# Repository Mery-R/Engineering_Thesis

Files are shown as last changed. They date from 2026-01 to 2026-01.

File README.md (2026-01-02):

# Engineering Thesis - GPS & CAN Data Collection System

## Project Overview

This is an ESP32-based data acquisition system designed for an engineering thesis. The system collects telemetry data from multiple sources including GPS (NMEA), Temperature (DS18B20), and CAN bus (via TWAI). Data is transmitted to the ThingsBoard IoT platform via MQTT over Wi-Fi and simultaneously logged to an SD card for offline retrieval.

 The system is designed with a coordinator-driven architecture using FreeRTOS to ensure synchronized data snapshots.

## System Architecture

### Main Components

1.  **main.ino**: Entry point handling FreeRTOS task creation, hardware setup, and the central Coordinator logic.
2.  **GpsModule**: Wrapper for `TinyGPSPlus`, handles UART communication with the GPS receiver.
3.  **CanModule**: Manages the ESP32 Two-Wire Automotive Interface (TWAI) to read speed data from the vehicle's CAN bus.
4.  **SdModule**: Manages logging data to SD card in JSON Lines format (`.jsonl`), including an "offline pending" queue for later transmission.
5.  **ThingsBoardClient**: Handles MQTT connection, telemetry data upload, and attribute synchronization (e.g., changing sampling intervals remotely).
6.  **TimeManager**: Maintains high-precision system time, synchronized via GPS PPS (Pulse Per Second) or optional NTP/WiFi fallback.
7.  **WebServerModule**: Provides a local web interface for system status/map visualization (runs on port 80).
8.  **WiFiManager**: Handles Wi-Fi connection logic, manages a list of known networks (SSID/Password), and handles automatic reconnection.
9.  **SensorData**: Header-only helper defining the core global data structure (`struct SensorData`) and bitwise error codes [ec] used for data exchange between tasks.

### FreeRTOS Tasks & Logic

 The system uses a **Coordinator-driven** architecture. A central task triggers sensors, waits for their data, creates a synchronized snapshot, and dispatches it for storage/upload.

1.  **CoordinatorTask** (Priority 2)
    *   Wakes up every `Delay_MAIN` (default 15s).
    *   Triggers measurement tasks (`TaskGPS`, `TaskTemp`, `TaskCAN`) via task notifications.
    *   Waits for an Event Group signal indicating all enabled sensors have finished (or timed out).
    *   Collects a snapshot of all sensor data + timestamp + RSSI.
    *   Pushes the snapshot to a Ring Buffer (Queue).
    *   Notifies `TaskDataSync` to process the new data.

2.  **TaskGPS** (Priority 1)
    *   Waits for trigger.
    *   Wakes GPS module and processes NMEA stream for up to 5 seconds to get a fresh fix.
    *   Updates global state with Lat, Lon, Alt, Speed.

3.  **TaskTemp** (Priority 1)
    *   Waits for trigger.
    *   Requests conversion on DS18B20 (approx 750ms delay).
    *   Updates global state with Temperature.

4.  **TaskCAN** (Priority 2)
    *   Continuously monitors CAN bus but updates the global snapshot timestamp/value when triggered by Coordinator or when fresh data arrives.

5.  **TaskDataSync** (Priority 1)
    *   Handles both ThingsBoard (MQTT) upload and SD Card logging.
    *   **Online**: Sends data from Ring Buffer to ThingsBoard.
    *   **Offline**: Saves data to a "Pending" file on SD card.
    *   **Recovery**: When connection is restored, reads from "Pending" file and uploads to ThingsBoard.
    *   **Archiving**: Always saves every record to `archive_timestamp.jsonl` on SD card.

6.  **TaskWiFi** (Priority 1)
    *   Monitors connection status and manages reconnection logic.

7.  **TaskSleep** (Priority 5)
    *   Handles the Wake/Sleep button.
    *   On press: debounces, waits for release, flushes all buffers to SD/MQTT, and initiates Deep Sleep.

### Data Flow

```mermaid
graph TD;
    Coord[Coordinator Task] -->|Trigger| GPS[TaskGPS];
    Coord -->|Trigger| Temp[TaskTemp];
    Coord -->|Trigger| CAN[TaskCAN];
    
    GPS -->|Signal Ready| EventGrp[Event Group];
    Temp -->|Signal Ready| EventGrp;
    CAN -->|Signal Ready| EventGrp;
    
    EventGrp -->|All Done| Coord;
    
    Coord -->|Snapshot| Queue[Ring Buffer Queue];
    Queue -->|Process| Sync[TaskDataSync];
    
    Sync -->|MQTT| Cloud[ThingsBoard];
    Sync -->|Write| SD[SD Card];
    
    subgraph SD Card;
    SD --> Archive[Archive File];
    SD --> Pending[Pending File];

    end;
    
    Pending -.->|Retry when Online| Sync;
```

## Hardware Configuration (ESP32)

### GPIO Pinout

These mappings are defined in `main.ino`.

| Component | Pin (GPIO) | Notes |
| :--- | :--- | :--- |
| **WiFi LED** | 27 | Status Indicator |
| **GPS LED** | 26 | Status Indicator |
| **SD LED** | 25 | Status Indicator |
| **GPS RX** | 17 | Connect to GPS TX |
| **GPS TX** | 16 | Connect to GPS RX |
| **GPS PPS** | 32 | Pulse Per Second (Time Sync) |
| **SD CS** | 5 | SPI Chip Select |
| **SD MOSI** | 23 | Standard VSPI |
| **SD MISO** | 19 | Standard VSPI |
| **SD SCK** | 18 | Standard VSPI |
| **DS18B20** | 4 | 1-Wire Data |
| **CAN RX** | 21 | TWAI RX |
| **CAN TX** | 22 | TWAI TX |
| **Wake Button** | 33 | Input Pullup (FALLING edge wake) |

> **Note**: The official pinout usually connects ESP32 TX to Device RX and vice-versa.
> *   `GPS_RX_PIN 17` -> Connect to GPS Module TX pin.
> *   `GPS_TX_PIN 16` -> Connect to GPS Module RX pin.

## SD Data Format

Data is stored in JSON Lines format.

**Example SD Record:**
```json
{
"ts":1767307224811,
"ts_source":2,
"lat":50.0691678,
"lon":19.9044705,
"alt":220.32,
"vel":0.87044,
"temp":18.8125,
"can_vel":0,
"lgr_ts":1767307224044,
"ltr_ts":1767307224811,
"lcr_ts":0,
"ec":0,
"tb_sent":true,
"rssi":-36
}
```

> **Note**: Explanation of fields:
> *   ts: Timestamp
> *   ts_source: Source of Timestamp
> *   lat: Latitude
> *   lon: Longitude
> *   alt: Altitude
> *   vel: Speed
> *   temp: Temperature
> *   can_vel: CAN Speed
> *   lgr_ts: Last GPS Read Timestamp
> *   ltr_ts: Last Temperature Read Timestamp
> *   lcr_ts: Last CAN Read Timestamp
> *   ec: Error Code
> *   tb_sent: If data was successfully sent to ThingsBoard
> *   rssi: Received Signal Strength Indicator

### Error Codes (`ec`)
Defined in `SensorData.h`:
*   `Bit 0 (1)`: GPS No Fix / Timeout
*   `Bit 1 (2)`: Temperature Sensor Failure
*   `Bit 2 (4)`: SD Card Failure
*   `Bit 3 (8)`: ThingsBoard/MQTT Failure

### Time Source (`ts_source`)
Defined in `TimeManager.h`:
*   `0`: Local/RTC
*   `1`: NTP
*   `2`: GPS

## ThingsBoard Data Format

Data is sent in ThingsBoard MQTT Telemetry JSON format.

**Example TB data with 2 records:**
```json
[
  {
    "ts": 1767307224811,
    "values": {
      "ts_source": 2,
      "lat": 50.0691678,
      "lon": 19.9044705,
      "alt": 220.32,
      "vel": 0.87044,
      "temp": 18.8125,
      "can_vel": 0,
      "ec": 0,
      "rssi": -36
    }
  },
  {
    "ts": 1767307224811,
    "values": {
      "ts_source": 2,
      "lat": 50.0691678,
      "lon": 19.9044705,
      "alt": 220.32,
      "vel": 0.87044,
      "temp": 18.8125,
      "can_vel": 0,
      "ec": 0,
      "rssi": -36
    }
  }
]
```

## Configuration

Several parameters can be adjusted remotely via ThingsBoard Shared Attributes:

*   `Delay_MAIN`: Main sampling interval (ms). Default: 15000.
*   `Delay_WIFI`: WiFi check interval (ms). Default: 30000.
*   `SEND_BATCH_SIZE`: Number of records to bundle before sending/saving. (Default: 2)
*   `BUFFER_SEND_THRESHOLD`: Minimum buffered records to trigger processing. (Default: 2)
*   `REQUIRE_VALID_TIME`: If true, buffers data until valid time source (GPS/NTP) is available. (Default: true)

## Usage Instructions

1.  **Boot**: Power on the device. It will attempt to connect to WiFi and sync time via GPS/NTP.
2.  **Running**: The LEDs will indicate status.
    *   **WiFi LED (27)**: ON = Connected and got IP.
    *   **GPS LED (26)**: ON = GPS Fix acquired.
    *   **SD LED (25)**: ON = SD Write Success.
3.  **Sleep**: Press the Button (GPIO 33) to trigger a flush of all data and enter Deep Sleep.
4.  **Wake**: Press the Button again to wake the device.

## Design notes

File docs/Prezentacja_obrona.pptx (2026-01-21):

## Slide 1

Projekt i wykonanie systemu lokalizacji pojazdu

Autor
Miłosz Stec
Opiekun pracy
dr inż. Grzegorz Góra

Akademia Górniczo-Hutnicza im. Stanisława Staszica w Krakowie
AGH University of Krakow

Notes: Dzień dobry Państwu. Nazywam się Miłosz Stec. Mam przyjemność przedstawić wyniki mojej pracy inżynierskiej pod tytułem: 'Projekt i wykonanie systemu lokalizacji pojazdu'. Praca została zrealizowana pod opieką Pana dr inż. Grzegorza Góry.

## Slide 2

Motywacja

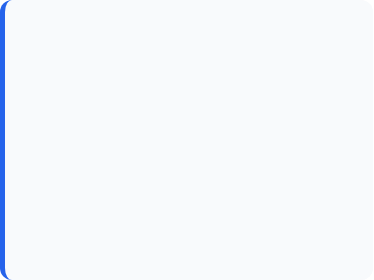
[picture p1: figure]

Rozwój
wiedzy

Chęć zdobycia praktycznej wiedzy z zakresu projektowania
i budowy urządzeń Internetu Rzeczy (IoT) oraz programowania mikrokontrolerów.

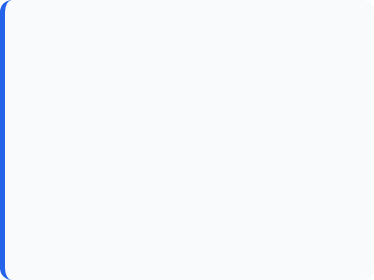
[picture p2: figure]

Zapotrzebowanie rynkowe

Rosnące zapotrzebowanie na narzędzia do precyzyjnej analizy przebytych tras oraz monitorowania parametrów eksploatacyjnych pojazdów.

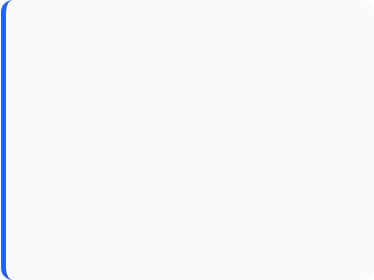
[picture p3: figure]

Aspekt
ekonomiczny

Koszt gotowych rozwiązań rynkowych jest relatywnie wysoki. Projekt własny stanowi tańszą, a równie funkcjonalną alternatywę.

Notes: Na motywację do podjęcia tego tematu złożyło się kilka czynników:
Po pierwsze, aspekt edukacyjny. Moim głównym celem osobistym była chęć zdobycia praktycznej wiedzy inżynierskiej. Zależało mi na połączeniu projektowania urządzeń Internetu Rzeczy (IoT) z programowaniem mikrokontrolerów, co stanowi fundament nowoczesnej elektroniki.
Drugim czynnikiem był aspekt ekonomiczny. Analiza rynku wykazała, że gotowe systemy są kosztowne. Mój projekt stanowi tańszą alternatywę.
Ostatnim elementem motywacji jest rosnące zapotrzebowanie rynkowe. Obserwujemy duży popyt na narzędzia pozwalające na precyzyjną analizę przebytych tras oraz monitorowanie parametrów eksploatacyjnych pojazdów, zarówno w firmach logistycznych, jak i w zastosowaniach prywatnych.

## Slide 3

Cel i założenia projektu

Cel pracy:

Projekt i realizacja urządzenia monitorowania położenia pojazdu z wykorzystaniem mikrokontrolera ESP32.

Założenia projektowe:
- Możliwość pracy urządzenia offline,
- Synchronizacja danych z serwerem po powrocie WiFi,
- Możliwość rozszerzenia o obsługę portu OBD2 oraz czujników środowiskowych,
- Oprogramowanie typu open-source.

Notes: Przechodząc do sedna pracy: celem było zaprojektowanie urządzenia opartego na mikrokontrolerze ESP32. Zdefiniowałem cztery kluczowe założenia projektowe:
Praca offline: Urządzenie musi gromadzić dane nawet przy braku zasięgu.
Synchronizacja: Po odzyskaniu połączenia WiFi dane mają automatycznie trafić na serwer.
Skalowalność: Możliwość rozszerzenia o interfejs OBD2 i dodatkowe czujniki.
Open-source: Oprogramowanie ma być otwarte i modyfikowalne."

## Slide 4

Algorytm pracy urządzenia

Wielowątkowa akwizycja danych (FreeRTOS):
- Akwizycja danych z modułów (GNSS, CAN, DS18B20) jest realizowana równolegle, w osobnych zadaniach.
Archiwizacja ciągła:
- Wszystkie dane są zapisywane na karcie SD w pliku archiwalnym.
Retransmisja danych:
- Przy braku połączenia z siecią WiFi dane trafiają do pliku „Pending”, a po odzyskaniu połączenia system automatycznie przesyła brakujące pakiety, zachowując chronologię.

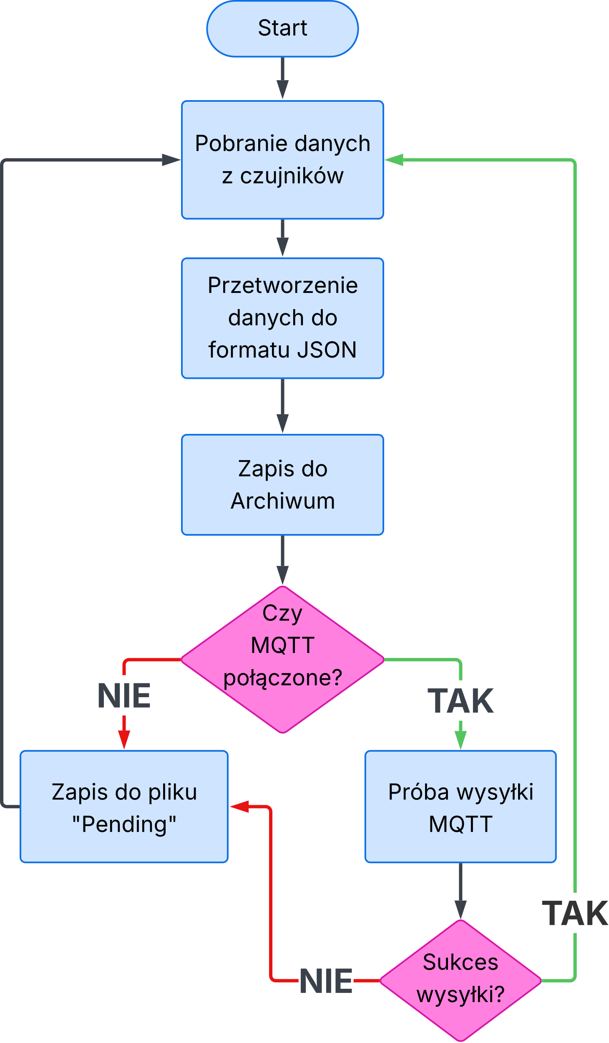
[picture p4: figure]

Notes: Sercem systemu jest oprogramowanie oparte na systemie czasu rzeczywistego FreeRTOS. Widoczny na slajdzie schemat jest pewnym uproszczeniem i prezentuje ogólną logikę pracy w trybie standardowym. W rzeczywistości, dzięki RTOS, kluczowe zadania realizowane są równolegle. Akwizycja danych z GNSS, odczyt z magistrali CAN oraz obsługa zapisu na kartę SD to niezależne wątki. Schemat pokazuje ścieżkę zapisu do pliku „Pending” przy braku sieci. Warto jednak dodać, że mechanizm retransmisji tych danych działa w tle – system automatycznie wysyła zaległe pakiety w momentach mniejszego obciążenia, nie blokując bieżących pomiarów.

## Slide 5

Realizacja prototypu

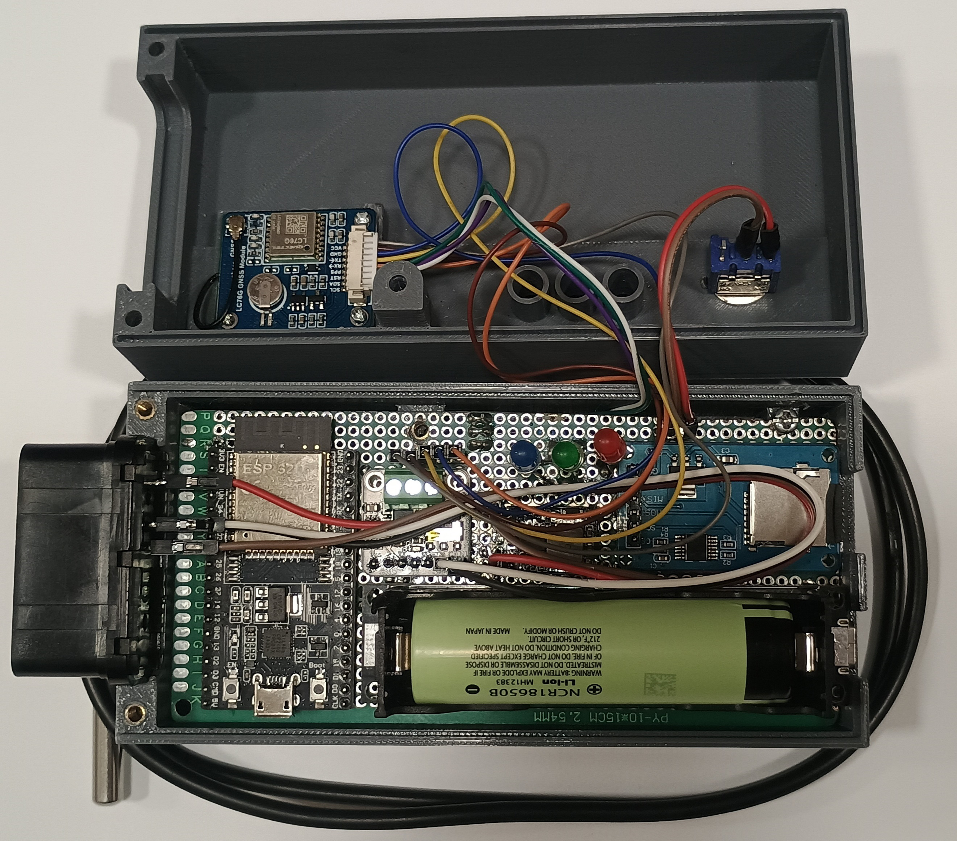
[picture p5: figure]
Obraz zawierający elektronika, Inżynieria elektroniczna, Element obwodu, Komponent elektroniczny Zawartość wygenerowana przez AI może być niepoprawna.

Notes: Fizyczna realizacja prototypu została przedstawiona na tym slajdzie. Widać tutaj moduł GNSS, mikrokontroler ESP32 oraz ogniwo zasilające 18650. Całość została zamknięta w zaprojektowanej i wydrukowanej w technologii 3D obudowie, co zapewnia ochronę mechaniczną.

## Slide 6

Interfejs ThingsBoard

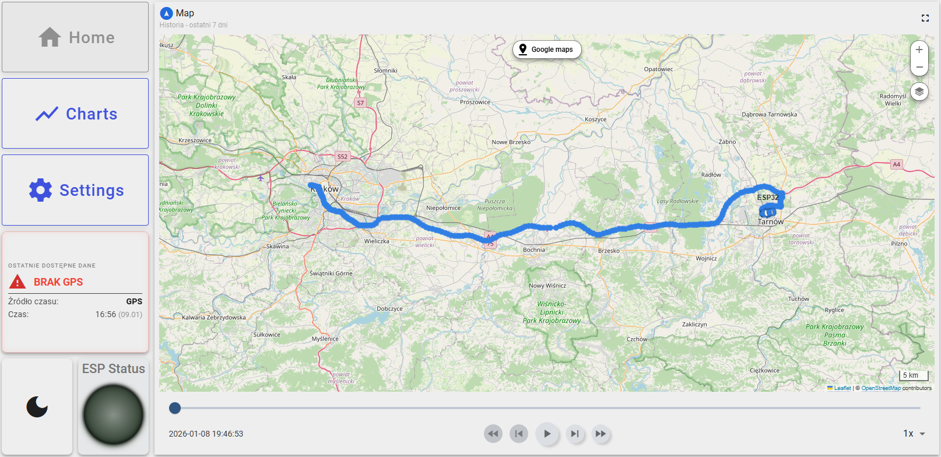
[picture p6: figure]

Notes: Do wizualizacji danych wykorzystano platformę ThingsBoard. Na slajdzie widzimy rzeczywisty zapis trasy przejazdu na odcinku Kraków – Tarnów. Potwierdza to, że precyzja pozycjonowania modułu GNSS jest wystarczająca do dokładnego śledzenia trasy, a ciągłość linii świadczy o poprawnym działaniu buforowania danych.

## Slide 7

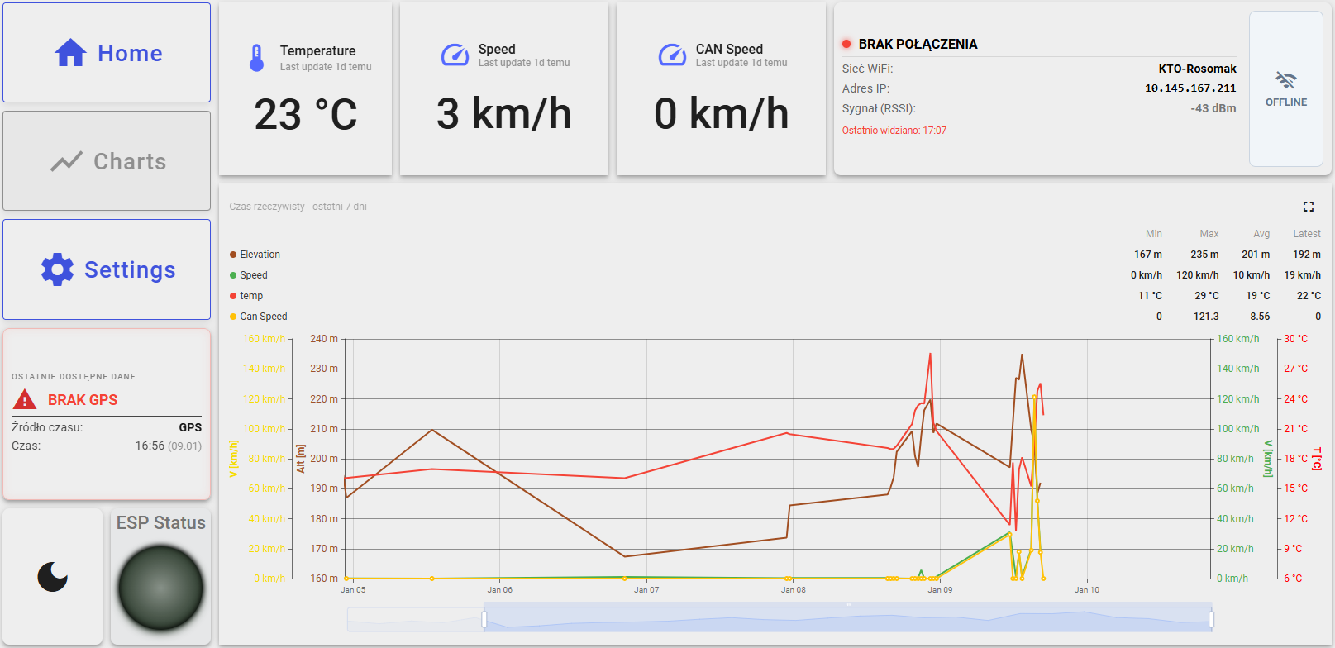
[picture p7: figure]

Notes: System oferuje również panel analityczny. Widzimy tu aktualne odczyty (temperatura, prędkość) oraz, co ważniejsze, wykresy historyczne. Na wykresie liniowym zestawiono prędkość, wysokość n.p.m. oraz temperaturę. Pozwala to na korelację parametrów jazdy z ukształtowaniem terenu.

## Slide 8

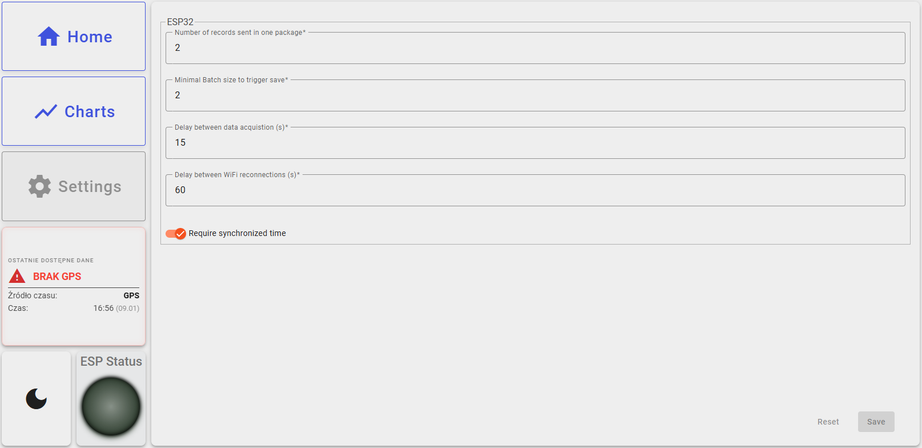
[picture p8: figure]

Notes: Zakładka 'Settings' pozwala na zdalną konfigurację urządzenia bez fizycznego dostępu do niego. Możemy zmieniać np. częstotliwość akwizycji danych czy interwały próby łączenia z WiFi, co pozwala optymalizować zużycie energii w zależności od potrzeb. Niestety działa to tylko przy poprawnym połączeniu WiFi.

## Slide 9

Podsumowanie

CEL PRACY ZOSTAŁ OSIĄGNIĘTY

Możliwości rozwoju

Wykonanie dedykowanej płytki PCB.

Dodanie modułu GSM dla śledzenia w czasie rzeczywistym.

Szyfrowanie danych na karcie SD.

Wnioski końcowe

Urządzenie realizuje wszystkie założone funkcje.

Potwierdzono poprawność integracji części sprzętowej z oprogramowaniem.

Precyzja pozycjonowania zastosowanego modułu GNSS jest wystarczająca do śledzenia trasy pojazdu.

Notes: Podsumowując, cel pracy został osiągnięty. Projekt ma jednak duży potencjał rozwojowy. Kolejnymi krokami, które zaplanowałem, są:

Zaprojektowanie dedykowanej płytki PCB zamiast układu prototypowego,
Dodanie modułu GSM, co uniezależniłoby urządzenie od WiFi i pozwoliło na śledzenie w czasie rzeczywistym,
Wdrożenie szyfrowania danych na karcie SD dla bezpieczeństwa.

Kończąc, chciałbym podkreślić najważniejsze wnioski:

Urządzenie w pełni realizuje założone funkcje akwizycji i transmisji danych.
Potwierdziłem poprawność integracji warstwy sprzętowej z oprogramowaniem i chmurą.
Zastosowany moduł GNSS zapewnia wystarczającą precyzję do śledzenia trasy pojazdu.

## Dziękuję za uwagę

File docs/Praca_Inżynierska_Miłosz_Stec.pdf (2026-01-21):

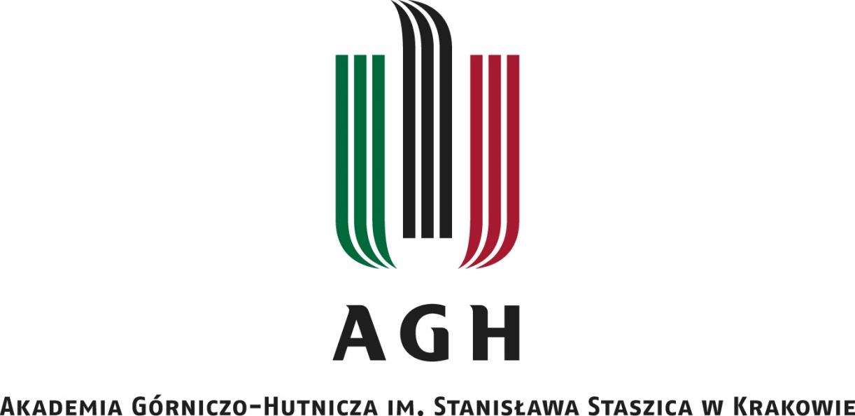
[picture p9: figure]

1

Wydział Inżynierii Mechanicznej i Robotyki

KATEDRA ROBOTYKI I MECHATRONIKI

## Projekt dyplomowy

### Projekt i wykonanie systemu lokalizacji pojazdu Design and Implementation of a Vehicle Localization System

Autor: | Miłosz Stec
Kierunek studiów: | Inżynieria Mechatroniczna
Opiekun pracy: | dr inż. Grzegorz Góra
| Kraków, 2025/2026

2

### Spis treści

4.3.6. Mechanizmy synchronizacji i komunikacji międzyprocesowej ..... 32

3

4

### 1. Wstęp

Dynamiczny rozwój technologii Internetu Rzeczy (ang. IoT – Internet of Things) oraz postępująca miniaturyzacja układów elektronicznych redefiniują współczesne podejście do systemów monitorujących. Pod pojęciem Internetu Rzeczy rozumie się koncepcję, w której przedmioty fizyczne (rzeczy) są wyposażone w czujniki, oprogramowanie i inne technologie w celu łączenia się i wymiany danych z innymi urządzeniami i systemami za pośrednictwem Internetu [1]. Możliwość tworzenia zaawansowanych, a jednocześnie kompaktowych i energooszczędnych urządzeń znajduje szerokie zastosowanie w wielu gałęziach przemysłu, ze szczególnym uwzględnieniem logistyki i transportu.

Współczesne systemy lokalizacyjne ewoluowały z prostych rejestratorów pozycji do roli kompleksowych narzędzi telemetrycznych. Telemetria, będąca kluczowym elementem omawianego zagadnienia, to dziedzina techniki zajmująca się automatycznym pozyskiwaniem danych pomiarowych z trudno dostępnych miejsc oraz ich przesyłaniem drogą radiową lub przewodową do zewnętrznych systemów rejestrujących [2]. Pozwalają one nie tylko na śledzenie trasy pojazdu, ale także na akwizycję i analizę danych diagnostycznych oraz parametrów środowiskowych, co znacząco zwiększa ich wartość użytkową w zarządzaniu flotą.

Niniejsza praca inżynierska dotyczy projektu i realizacji autorskiego systemu lokalizacji pojazdu, opartego na platformie sprzętowej ESP32. Opracowany układ, działający w architekturze IoT, ma za zadanie rejestrować dane o położeniu geograficznym i zapisywać je lokalnie na karcie pamięci SD (Secure Digital), a po uzyskaniu dostępu do zaufanej sieci bezprzewodowej – synchronizować je z serwerem zewnętrznym. Projekt zakłada również opcjonalną integrację z magistralą pojazdu (CAN – Controller Area Network / OBDII – On Board Diagnostics II) w celu rejestracji podstawowych parametrów eksploatacyjnych oraz możliwość rozbudowy o czujniki środowiskowe.

Główną motywacją do podjęcia tematu była chęć pogłębienia wiedzy w zakresie systemów wbudowanych czasu rzeczywistego oraz praktycznego zastosowania protokołów komunikacyjnych w systemach rozproszonych. Istotnym czynnikiem decyzyjnym było również zidentyfikowane zapotrzebowanie rynkowe w ramach

5

rodzinnej firmy zajmującej się wynajmem pojazdów. Istniała tam potrzeba monitorowania eksploatacji floty, jednak dostępne rozwiązania komercyjne okazywały się nieekonomiczne lub zbyt zamknięte na modyfikacje. Budowa własnego rozwiązania pozwoliła uwzględnić aspekt ekonomiczny, oferując funkcjonalną i tańszą alternatywę dostosowaną do specyficznych wymagań użytkownika.

Realizacja pracy wymagała spełnienia szeregu założeń technicznych, w tym implementacji systemu operacyjnego czasu rzeczywistego (FreeRTOS – Free Real Time Operating System), w celu zapewnienia współbieżności procesów akwizycji i transmisji danych oraz stworzenia obudowy umożliwiającej testy w warunkach drogowych.

6

### 2. Cel i zakres pracy

Celem głównym jest zaprojektowanie i realizacja urządzenia monitorowania położenia pojazdu z wykorzystaniem mikrokontrolera ESP32.

### 2.1. Szczegółowe cele pracy

Niniejszy podrozdział precyzuje zakres prac niezbędnych do realizacji celu głównego. Poniżej przedstawione zostały cele szczegółowe, które stanowią fundament planowanych działań projektowych.

- Implementację oprogramowania, umożliwiającego akwizycję danych z modułu GNSS (Global Navigation Satellite System), ich archiwizację na karcie pamięci SD oraz zdalną synchronizację z serwerem.
- Zaprojektowanie i wykonanie warstwy sprzętowej urządzenia, w tym obwodu drukowanego (lub układu prototypowego) oraz obudowy.
- Przeprowadzenie testów funkcjonalnych prototypu w warunkach rzeczywistych.
- Analizę jakości pozyskanych danych lokalizacyjnych oraz ocenę skuteczności mechanizmu synchronizacji danych.

### 2.2. Zakres pracy

W celu realizacji zdefiniowanych powyżej celów pracy, ustalono zakres prac składających się z:

- analizy wymagań projektowych i przeglądu konkurencyjnych rozwiązań,
- opracowania schematu połączeń,
- realizacji fizycznego prototypu urządzenia (montażu podzespołów),
- implementacji oprogramowania sterującego dla układu ESP32,
- weryfikacja działania urządzenia,
- przygotowania wniosków i propozycji dalszych prac.

7

Układ pracy został podzielony na rozdziały odpowiadające etapom procesu projektowego. Rozdział pierwszy stanowi wstęp, wprowadzający w tematykę systemów telemetrycznych i Internetu Rzeczy. W rozdziale drugim zdefiniowano cel główny, cele szczegółowe oraz zakres realizowanej pracy. Rozdział trzeci stanowi studium teoretyczne, zawierające przegląd wykorzystanych technologii (m.in. GNSS, MQTT – Message Queuing Telemetry Transport) oraz analizę porównawczą rozwiązań dostępnych na rynku. W rozdziale czwartym określono zakres funkcjonalny projektowanego urządzenia, przedstawiono proces projektowania i implementacji systemu, obejmujący opis architektury sprzętowej, a także strukturę oprogramowania oraz integrację z platformą serwerową ThingsBoard. Opisano tu również fizyczne wykonanie prototypu. W końcowej części tego rozdziału przedstawiono wyniki przeprowadzonych testów elektrycznych, funkcjonalnych oraz drogowych. Rozdział piąty zawiera podsumowanie i wnioski. Omówiono w nim napotkane problemy i ograniczenia realizacyjne, sformułowano finalne wnioski z realizacji projektu oraz zaproponowano kierunki dalszego rozwoju systemu.

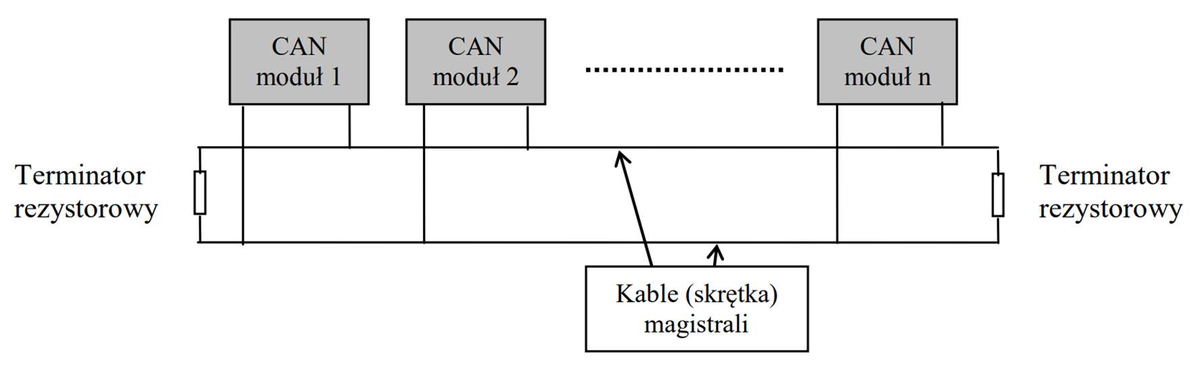
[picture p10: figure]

8

### 3. Podstawy teoretyczne i przegląd rozwiązań

### 3.1. Przegląd technologiczny

Współczesne systemy telemetryczne i lokalizacyjne wymagają integracji wielu warstw technologicznych, począwszy od niskopoziomowej obsługi sprzętu, poprzez systemy operacyjne czasu rzeczywistego, aż po protokoły komunikacyjne. Niniejszy rozdział stanowi studium technologii wybranych do realizacji projektu inżynierskiego.

### 3.1.1. Magistrala CAN

Magistrala CAN to szeregowa magistrala komunikacyjna opracowana przez firmę Bosch w latach 80. XX wieku, znormalizowana jako ISO 11898. Jest ona nadal jednym z kluczowych standardów wymiany danych w systemach motoryzacyjnych oraz automatyce przemysłowej [3].

CAN wykorzystuje transmisję różnicową, co zapewnia wysoką odporność na zakłócenia elektromagnetyczne, co jest cechą kluczową w środowisku pracy jakim jest pojazd. Dla sieci CAN pokazanej na rysunku 3.1, fizyczne medium transmisyjne stanowi zazwyczaj para skręconych przewodów tzw. „skrętka”, zakończona rezystorami terminującymi o wartości 120 Ω, co zapobiega odbiciom sygnału.

Rys. 3.1. Podstawowy schemat magistrali CAN [4]

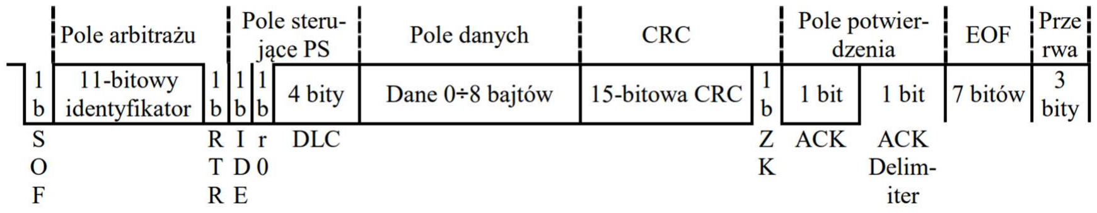
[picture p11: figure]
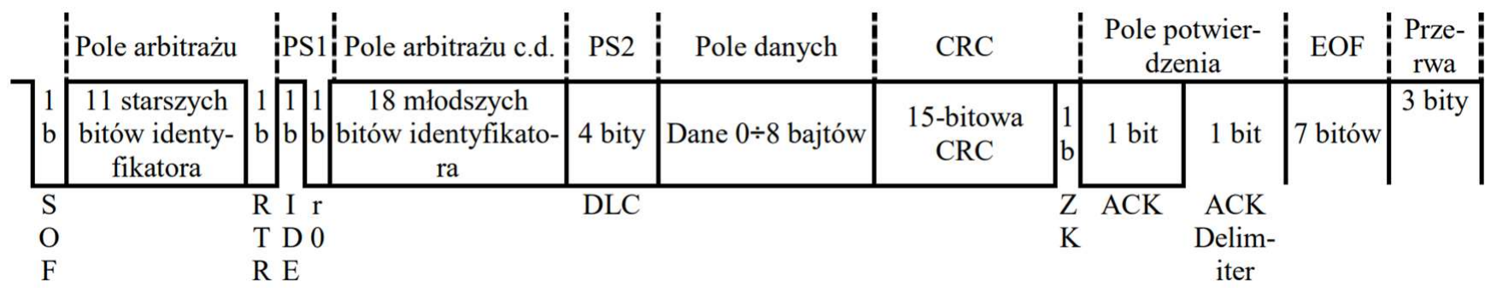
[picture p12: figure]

9

Sygnał interpretowany jest na podstawie różnicy potencjałów między liniami CAN High i CAN Low [4]:

- Stan recesywny (logiczna „1”): występuje, gdy napięcie na obu liniach jest zbliżone (ok. 2,5 V).
- Stan dominujący (logiczne „0”): występuje, gdy różnica napięć wzrasta

(CAN Higℎ = 3,5 V, CAN Low = 1,5 V).

W przypadku jednoczesnego nadawania przez dwa węzły, „wygrywa” ten, który nadaje stan dominujący („0”) na bitach identyfikatora o niższej wadze liczbowej (niższy numer ID oznacza wyższy priorytet).

Format ramek CAN pokazano na rysunkach 3.1 oraz 3.2.

Rys. 3.2 Struktura ramki danych (format ramki standardowej – CAN 2.0A) [5]

Rys. 3.3 Struktura ramki danych (format ramki rozszerzonej – CAN 2.0B) [5]
Zalety sieci CAN obejmują między innymi [5]:
- brak jednostki centralnej,
- duża prędkość transmisji,
- odporność na zakłócenia,
- sprawne procedury obsługi błędów,
- możliwość podłączenia dużej liczby stacji,
- możliwość utworzenia 2
różnych identyfikatorów wiadomości.

10

### 3.1.2. Protokół MQTT

MQTT to protokół transmisji danych (charakteryzujący się niskim narzutem danych, gdzie nagłówek pakietu może wynosić zaledwie 2 bajty), wykorzystujący protokół TCP – Transmission Control Protocol / IP – Internet Protocol jako warstwę transportową. Został znormalizowany w 2014 roku przez firmę OASIS. Jest często stosowany w systemach IoT oraz telemetrii pojazdowej. [6]

W przeciwieństwie do modelu klient-serwer (znanego np. z HTTP – Hypertext Transfer Protocol), MQTT wprowadza trzeci podmiot – brokera wiadomości. Architektura składa się z trzech elementów [6]:

- Wydawca (ang. Publisher): urządzenie końcowe (lokalizator), które wysyła dane telemetryczne.
- Broker: serwer pośredniczący, odpowiedzialny za filtrowanie i dystrybucję wiadomości.
- Subskrybent (ang. Subscriber): aplikacja lub baza danych odbierająca informacje.

Taka architektura zapewnia asynchroniczność komunikacji oraz skalowalność systemu – wydawca nie musi znać adresu IP odbiorcy ani jego stanu aktywności. Protokół MQTT definiuje trzy poziomy jakości usług (ang. QoS – Quality of Service), które pozwalają dostosować pewność dostarczenia danych do warunków sieciowych (np. niestabilnego połączenia GSM – Global System for Mobile Communications) [6]:

- QoS 0 (At most once): „Wyślij i zapomnij”. Brak potwierdzenia odbioru. Najmniejsze zużycie transferu.
- QoS 1 (At least once): gwarancja dostarczenia (możliwe duplikaty). Wymagane potwierdzenie (PUBACK).
- QoS 2 (Exactly once): gwarancja jednokrotnego dostarczenia. Największy narzut komunikacyjny.

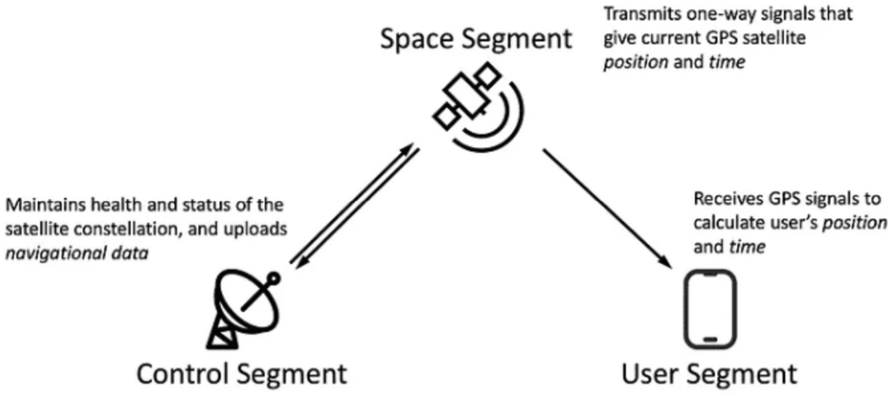
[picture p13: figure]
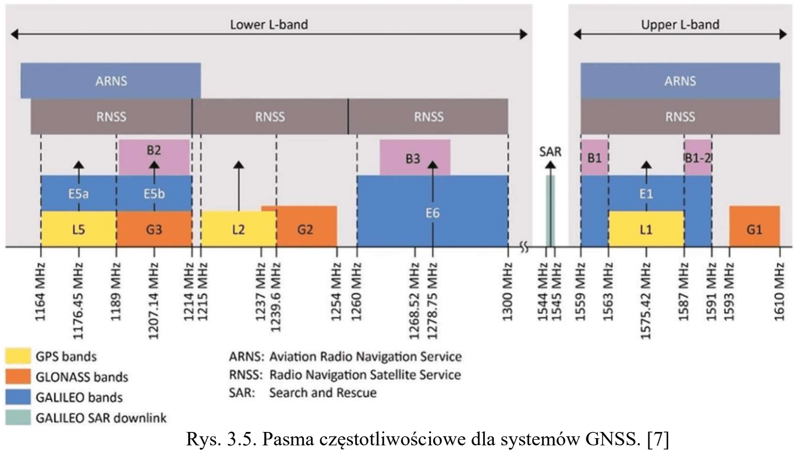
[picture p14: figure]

11

### 3.1.3. Systemy GNSS i standard NMEA 0183

GNSS to ogólna nazwa systemów nawigacji satelitarnej, obejmująca m.in. amerykański GPS, europejski Galileo, rosyjski GLONASS oraz chiński BeiDou. Architektura systemów GNSS składa się ze stacji naziemnych, satelitów oraz odbiorników końcowych, co można zaobserwować na rysunku 3.4.

Rys. 3.4. Architektura systemu GNSS. [7]
Większość tych satelitów operuje na średniej orbicie okołoziemskiej (ang. MEO – Medium Earth Orbit), czyli około 20000 km. Każdy z nich wysyła sygnał modulowany o odpowiedniej częstotliwości [7]. W zależności od systemu ta częstotliwość jest inna co można zaobserwować na rysunku 3.5.

Rys. 3.5. Pasma częstotliwościowe dla systemów GNSS. [7]

12

Zasada wyznaczania pozycji opiera się na trilateracji sferycznej, gdzie odbiornik oblicza swoją lokalizację na podstawie pomiaru czasu propagacji sygnału radiowego z co najmniej czterech satelitów [7].

Standard NMEA 0183 to dobrowolny standard specyfikacji interfejsu elektrycznego i protokołu danych dla sprzętu morskiego i nawigacyjnego, opracowany przez National Marine Electronics Association. W systemach wbudowanych komunikacja odbywa się zazwyczaj poprzez interfejs asynchroniczny UART (Universal Asynchronous Receiver/Transmitter). Dane przesyłane są w postaci czytelnych ciągów znaków ASCII, zwanych „zdaniami”.

Przykład struktury ramki RMC (Recommended Minimum Specific GNSS Data)[8]:

$GPRMC,210230,A,3855.4487,N,09446.0071,W,0.0,076.2,130495,003.8,E*69

Tabela 3.1 Wyjaśnienie struktury ramki RMC
Przykład | Wyjaśnienie
$ | Początek sekwencji
GPRMC | Typ wiadomości

210230 Obecny czas UTC

A Status pozycji (A - poprawny, V – niepoprawny)

3855.4487,N | Szerokość geograficzna wraz z kierunkiem (DDMM.MMM)
09446.0071,W | Długość geograficzna wraz z kierunkiem (DDDMM.MMM)

0.0 Prędkość

076.2 Kurs

130495 Data (DDMMYY)
003.8,E | Wariacja magnetyczna wraz z kierunkiem
*69 | Suma kontrolna (w systemie szesnastkowym)

Technologia EASY™ (Embedded Assist System) jest istotnym rozszerzeniem funkcjonalności w nowoczesnych odbiornikach GNSS. Służy ona do skrócenia czasu ustalenia pozycji. W przeciwieństwie do rozwiązań typu A-GPS wymagających

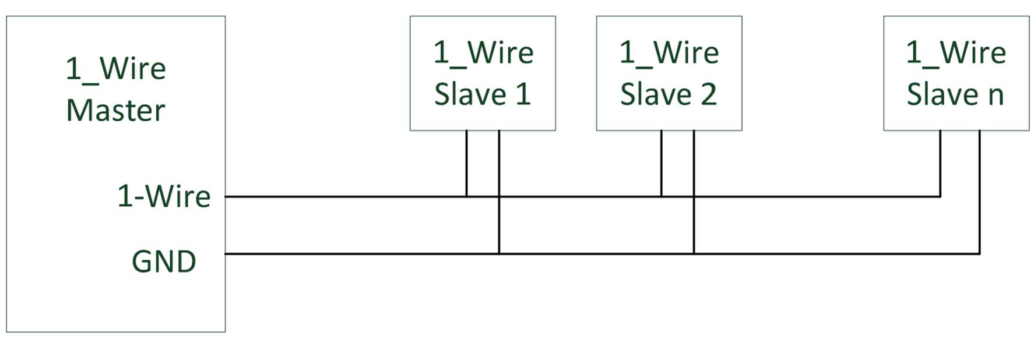
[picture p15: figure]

13

połączenia z siecią, EASY działa autonomicznie – odbiornik oblicza i przewiduje orbity satelitów na okres do 3 dni naprzód, bazując na danych odebranych podczas ostatniej aktywności. Informacje te są przechowywane w podtrzymywanej bateryjnie pamięci RAM lub Flash. Dzięki temu, po ponownym uruchomieniu urządzenia (nawet przy braku bieżącego sygnału z satelitów przez pierwsze sekundy), moduł może błyskawicznie wyznaczyć pozycję, korzystając z zapamiętanych efemeryd [9].

### 3.1.4. Magistrala 1-Wire

1-Wire to system magistrali komunikacyjnej zaprojektowany przez Dallas Semiconductor (obecnie Analog Devices), który zapewnia stosunkowo niską prędkość transmisji danych na poziomie 16 kbps. Magistrala działa w układzie „Master-Slave”, co przedstawia rys.3.3.

Rys. 3.6. Podstawowy schemat sieci 1-Wire. [10]
Kluczową cechą magistrali jest wyjście typu otwarty dren z rezystorem podciągającym (o wartości 1000-5000 Ω) do zasilania (zazwyczaj 3,3 V lub 5 V). Umożliwia to realizację tzw. „zasilania pasożytniczego” – urządzenia podrzędne mogą czerpać energię z linii danych w stanie wysokim, ładując wewnętrzny kondensator, co pozwala na redukcję okablowania do dwóch przewodów (DATA, GND). [10]

Każde urządzenie 1-Wire posiada fabrycznie nadany, unikalny, 64-bitowy kod ROM, na który składa się [10]:

- 8 bitów kodu rodziny: identyfikuje typ urządzenia (np. termometr),
- 48 bitów unikalnego numeru seryjnego,
- 8 bitów sumy kontrolnej CRC.

14

### 3.1.5. FreeRTOS

FreeRTOS jest systemem czasu rzeczywistego zapewniającym determinizm czasowy, co oznacza że czas reakcji musi być znany i powtarzalny. Sercem tego systemu jest planista (ang. Scheduler), który odpowiada za wykonywanie zadania o aktualnie najwyższym priorytecie.

Aby zapewnić stabilną wymianę danych i synchronizację między wątkami, wykorzystuje się zaawansowane mechanizmy komunikacji międzyprocesowej (ang. Inter Process Communication) [11]:

- Powiadomienia: stosuje się w celu wysłania bezpośrednio powiadomienia do innego zadania,
- Kolejki: służą do bezpiecznego buforowania i przesyłania struktur danych między zadaniami,
- Semafory: są używane do synchronizacji i zarządzania zasobami,
- Mutexy: semafory, które posiadają mechanizm dziedziczenia priorytetów,
- Grupy Zdarzeń: pozwalają zadaniu czekać na kombinacje wielu flag bitowych.

Dodatkowo, nadzór nad stabilnością pracy sprawuje sprzętowy „Watchdog Timer”, który resetuje układ w przypadku wykrycia anomalii w działaniu któregokolwiek z krytycznych wątków.

### 3.2. Analiza wybranych rozwiązań rynkowych

Rynek systemów lokalizacji pojazdów cechuje się obecnie szeroką gamą rozwiązań o zróżnicowanej funkcjonalności, cenie oraz przeznaczeniu. Od prostych rejestratorów tras, przez systemy antykradzieżowe, aż po zaawansowaną telematykę flotową. W celu osadzenia realizowanego projektu w kontekście rynkowym, dokonano analizy trzech reprezentatywnych urządzeń dostępnych w sprzedaży oraz porównano je z projektowanym rozwiązaniem.

Do przeglądu wybrano urządzenia reprezentujące różne segmenty rynku:

- klasyczny lokalizator montowany na stałe,

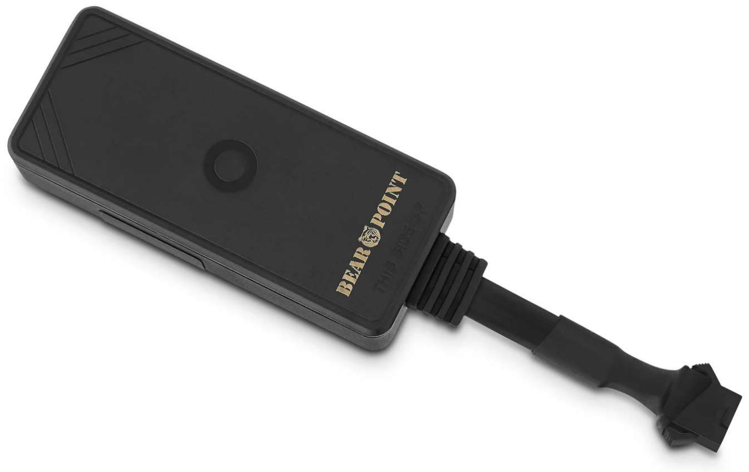
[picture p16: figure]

15

- rozwiązanie typu „Plug & Play” pod złącze OBD,
- przenośny lokalizator z własnym zasilaniem.

### 3.2.1. Lokalizator GPS BearPoint C18

Rys. 3.4. Urządzenie BearPoint C18. [12]
BearPoint C18 (rys. 3.4) stanowi przykład klasycznego lokalizatora montowanego na stałe w instalacji elektrycznej pojazdu, dedykowanego zarówno klientom indywidualnym, jak i zarządcom flot. Warstwa komunikacyjna urządzenia bazuje na technologii 4G/LTE z mechanizmem automatycznego przełączania do sieci 2G, co gwarantuje stabilność zasięgu. Konstrukcja sprzętowa uwzględnia wbudowaną baterię, podtrzymującą pracę modułu w przypadku awarii lub sabotażu zasilania głównego. W zakresie funkcjonalności system oferuje śledzenie pozycji w czasie rzeczywistym, obsługę geostref, alerty o przekroczeniu prędkości oraz możliwość zdalnego unieruchomienia pojazdu poprzez wysterowanie przekaźnika zapłonu. Z perspektywy modelu biznesowego rozwiązanie to opiera się na udostępnieniu przez producenta gotowego środowiska wizualizacyjnego, co zazwyczaj wiąże się z modelem abonamentowym i generuje stałe koszty eksploatacji.

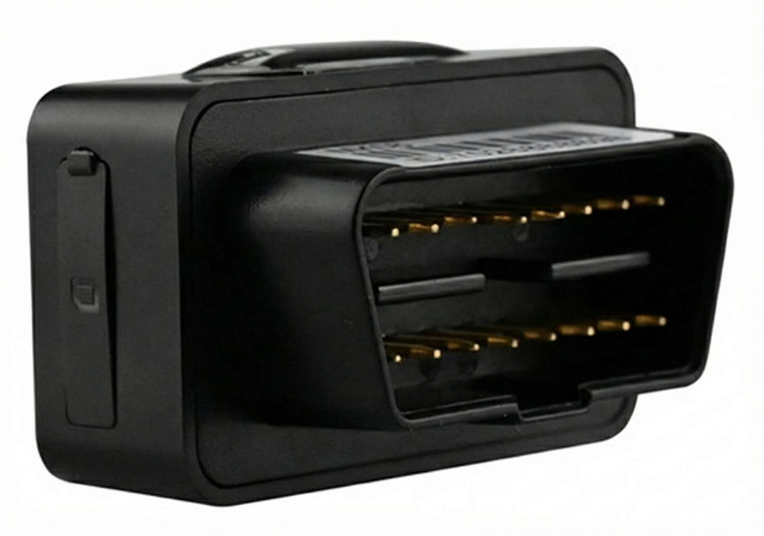
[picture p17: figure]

16

### 3.2.2. Lokalizator GPS OBD MK08

Rys. 3.5. Urządzenie MK08. [13]
MK08 (rys. 3.5) to przedstawiciel kategorii urządzeń „Plug & Play”, które wykorzystują złącze diagnostyczne OBDII jako źródło zasilania oraz punkt montażowy. Kluczową zaletą tego rozwiązania jest brak konieczności ingerencji w instalację elektryczną pojazdu, proces instalacji ogranicza się do wpięcia urządzenia w gniazdo diagnostyczne. W zakresie funkcjonalności moduł oferuje podstawowe usługi lokalizacyjne, archiwizację historii tras oraz system alarmów wstrząsowych. Warto jednak odnotować, że budżetowe wersje tego typu rozwiązań często wykorzystują interfejs OBDII wyłącznie do zasilania, nie implementując pełnej obsługi protokołu diagnostycznego (brak odczytu parametrów takich jak RPM czy kody błędów), co stanowi istotne ograniczenie względem zaawansowanych systemów telematycznych. Ciągłe zasilanie z instalacji pojazdu rozwiązuje problem konieczności ładowania baterii wewnętrznej, lecz w przypadku dłuższego postoju może prowadzić do nadmiernego obciążenia akumulatora rozruchowego.

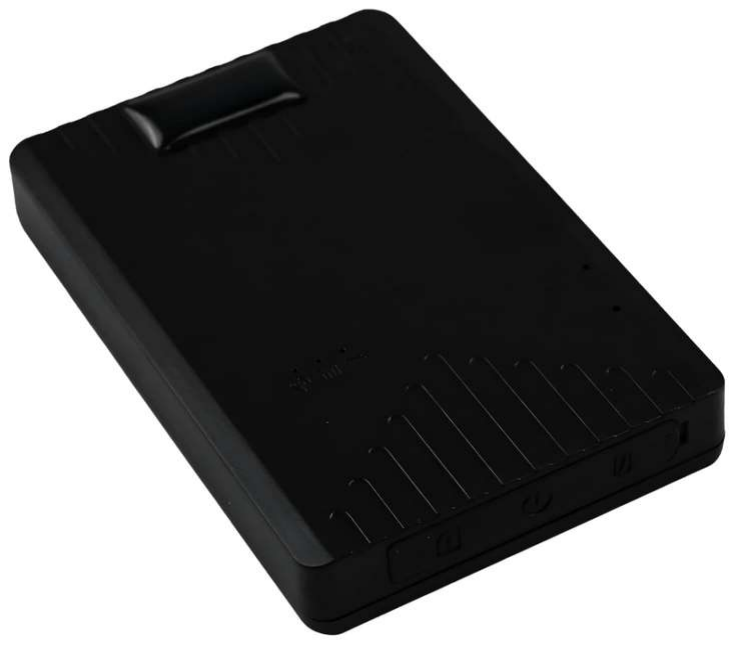
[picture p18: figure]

17

### 3.2.3. Lokalizator GPS MK6B 4G

Rys. 3.6. Urządzenie MK6B. [14]
Model MK6B (rys. 3.6) reprezentuje segment lokalizatorów mobilnych, działających niezależnie od stałej instalacji elektrycznej pojazdu. Cechą wyróżniającą to rozwiązanie jest implementacja ogniwa o wysokiej pojemności (3000 mAh), co pozwala na osiągnięcie czasu pracy wynoszącego nawet 35 dni, w zależności od skonfigurowanej częstotliwości rejestracji i wysyłania danych. Urządzenie wyposażono w zintegrowany montaż magnetyczny, umożliwiający szybką instalację na zewnętrznych elementach karoserii lub kontenerach transportowych. Warstwa komunikacyjna oparta jest na modemie 4G LTE, zapewniającym transmisję danych w czasie rzeczywistym. Ze względu na swoją autonomiczność energetyczną, urządzenie to znajduje zastosowanie głównie w monitoringu doraźnym, zabezpieczaniu ładunków oraz śledzeniu maszyn budowlanych pozbawionych dostępu do pokładowej sieci zasilającej.

18

### 3.2.4. Kategoryzacja dostępnych rozwiązań

Na podstawie przeglądu rynku można wyróżnić trzy główne kategorie systemów lokalizacji, różniące się architekturą, kosztami, dokładnością i grupą docelową.

Rozwiązania OEM (Original Equipment Manufacturer): Systemy fabrycznie montowane w nowoczesnych pojazdach, głęboko zintegrowane z magistralą CAN i systemami multimedialnymi. Stawiają na wygodę użytkownika cywilnego, a nie na analizę logistyczną. Oferują najwyższą jakość danych diagnostycznych poprzez wykorzystanie m.in. eSIM (Embedded SIM), GPS, żyroskopów, akcelerometrów, kąta skrętu kół. Poprzez bezpośrednie wbudowanie w systemy pojazdy rozwiązania takie są zamknięte dla użytkownika. Większość producentów ogranicza system do podglądu pozycji parkowania ze względów prywatności. Koszty początkowe są zerowe (w cenie zakupu auta), i często abonament na usługi lokalizacyjne jest opłacony na 1-3 lat. Niestety po tym okresie trzeba zapłacić nawet kilkaset złotych rocznie za utrzymanie łączności.

Gotowe komercyjne lokalizatory GPS (np. BearPoint C18, MK08, MK6B): są to kompletne produkty, często zamknięte systemowo, zintegrowane z kartą SIM (Subscriber Identity Module) i dedykowaną chmurą producenta. Zapewniają wysoką niezawodność, dokładność oraz łatwość obsługi dla użytkownika końcowego. Koszt początkowy to zazwyczaj kilkaset złotych w zależności od producenta i modelu. Do tego dochodzą koszty abonamentu za kartę SIM oraz dostęp do chmury. Takie rozwiązanie wiąże się z brakiem możliwości modyfikacji oprogramowania czy sposobu przetwarzania danych.

Modułowe rozwiązania własnego wykonania „DIY” (ang. Do it yourself): są to systemy oparte na uniwersalnych mikrokontrolerach (ESP32, Arduino) i oddzielnych modułach GNSS/GSM. Koszt początkowy to wartość wszystkich komponentów potrzebnych do zbudowania urządzenia, zazwyczaj do kilkuset złotych. W zależności od zastosowanych technologii mogą również występować koszty abonamentu związane np. z kartą SIM. Rozwiązanie takie cechuje się wysoką elastycznością, relatywnie niskim kosztem początkowym i pełną kontrolą nad danymi, wymagają jednak samodzielnej integracji sprzętowej i programowej.

19

### 3.2.5. Wnioski z przeglądu i uzasadnienie wyboru technologii

Analiza konkurencyjnych rozwiązań prowadzi do następujących wniosków, które ukształtowały założenia projektowe niniejszej pracy:

- Zasadność podejścia modułowego: dla celów edukacyjnych i prototypowych, wykorzystanie mikrokontrolera jest wystarczające. Pozwala na obniżenie kosztów budowy urządzenia oraz umożliwia szybkie iteracje (zmiany w algorytmie i sprzęcie), co jest niemożliwe w zamkniętych produktach komercyjnych.
- Akceptacja ograniczeń komunikacyjnych: wybór Wi-Fi jako głównego kanału transmisji jest świadomym kompromisem pomiędzy ciągłością transmisji oferowaną przez GSM a minimalizacją kosztów, wynikającą z rezygnacji z modułów łączności (GSM) oraz abonamentu karty SIM. Choć komercyjne lokalizatory (BearPoint C18, MK08, MK6B) oferują ciągły monitoring przez LTE, w zastosowaniach takich jak analiza tras po fakcie, logistyka wewnętrzna czy „czarne skrzynki”, synchronizacja okresowa po powrocie do zasięgu znanej sieci jest wystarczająca.
- Potencjał integracji OBD2: przegląd urządzenia MK08 wskazuje na duży potencjał złącza diagnostycznego. Jednakże, aby w projekcie „DIY” uzyskać funkcjonalność wykraczającą poza samo zasilanie, konieczne jest zastosowanie dodatkowego transceivera CAN (np. TJA1050).

Podsumowując, realizowany projekt nie stanowi bezpośredniej konkurencji dla systemów antykradzieżowych (wymagających LTE), lecz jest elastyczną platformą telemetryczną, oferującą funkcjonalności niedostępne w tanich lokalizatorach, takie jak pełny dostęp do surowych danych i możliwość dowolnej konfiguracji parametrów zapisu.

20

### 4. Projekt i implementacja urządzenia

Rozdział ten opisuje szczegóły projektowe warstwy sprzętowej i programowej, prezentując sposób, w jaki omówione wcześniej technologie zostały zintegrowane w spójny system.

### 4.1. Założenia projektowe

Na podstawie zdefiniowanego celu głównego przyjęto szereg założeń funkcjonalnych, sprzętowych oraz programowych, które determinują sposób realizacji projektu.

### 4.1.1. Założenia funkcjonalne

Określają one zakres operacji realizowanych przez system, aby spełnić cel projektu. Poniżej zdefiniowano kluczowe funkcje i zachowania, jakimi musi charakteryzować się gotowe urządzenie.

- Autonomia działania: urządzenie powinno działać w sposób bezobsługowy, automatycznie rozpoczynając akwizycję danych po włączeniu zasilania.
- Rejestracja danych: system musi umożliwiać ciągły zapis parametrów lokalizacyjnych (szerokość i długość geograficzna, czas, prędkość) na lokalnym nośniku danych (karta SD).
- Synchronizacja danych: urządzenie powinno posiadać mechanizm wykrywania dostępności połączenia sieciowego i automatycznego przesyłania zgromadzonych danych na serwer zewnętrzny (buforowanie danych w trybie offline).
- Sygnalizacja stanu: zastosowanie diod LED (Light Emitting Diode) lub innego interfejsu informującego użytkownika o statusie pracy (np. status WiFi, status karty SD, aktywność GNSS).
- Możliwość rozbudowy: projekt powinien uwzględniać możliwość przyszłego dołączenia interfejsu diagnostycznego pojazdu (OBD/CAN) oraz dodatkowych czujników (np. temperatury).

21

### 4.1.2. Założenia sprzętowe

Definiują one wymagania dotyczące fizycznej konstrukcji urządzenia, w tym doboru układów elektronicznych i parametrów zasilania. Do realizacji projektu niezbędne jest zastosowanie podzespołów spełniających następujące kryteria.

- Jednostka sterująca: wykorzystanie mikrokontrolera z wbudowanym modułem komunikacji bezprzewodowej (Wi-Fi/Bluetooth) oraz wysoką wydajnością obliczeniową.
- Moduł lokalizacyjny: zastosowanie modułu GNSS obsługującego standard NMEA, zapewniającego dokładność lokalizacji wystarczającą do śledzenia trasy pojazdu.
- Zasilanie: system przystosowany do zasilania z instalacji samochodowej (poprzez odpowiedni układ obniżający napięcie) lub zewnętrznego źródła mobilnego (powerbank/akumulator Li-Ion).
- Pamięć masowa: wykorzystanie karty pamięci SD jako bufora danych o dużej pojemności, umożliwiającego długotrwały zapis historii tras.
- Obudowa: konstrukcja mechaniczna powinna zapewniać ochronę układów elektronicznych przed uszkodzeniami mechanicznymi.

### 4.1.3. Założenia programowe

Dotyczą architektury kodu, wyboru języka programowania, środowiska deweloperskiego oraz zastosowanych algorytmów i protokołów komunikacyjnych. Warstwę logiczną zaprojektowano w oparciu o następujące wytyczne i narzędzia:

- Środowisko programistyczne: oprogramowanie zostanie zrealizowane w języku C++ w oparciu o środowisko programistyczne Arduino, co zapewni dostęp do szerokiej bazy bibliotek obsługi układów peryferyjnych.

22

- Struktura danych: dane na karcie SD będą zapisywane w ustrukturyzowanym formacie tekstowym (np. CSV – Comma Separated Values, JSON – JavaScript Object Notation), co umożliwi ich późniejsze przetwarzanie i analizę.
- Obsługa błędów: system musi być odporny na typowe błędy, takie jak brak karty SD, utrata sygnału GNSS czy brak połączenia z serwerem, i wznawiać pracę po ustąpieniu awarii.

### 4.2. Architektura sprzętowa

Zaprojektowany system akwizycji danych opiera się na architekturze modułowej, w której jednostka centralna zarządza układami peryferyjnymi odpowiedzialnymi za pozycjonowanie, komunikację z magistralą pojazdu, pomiary środowiskowe oraz
archiwizację | danych. | Poniżej | przedstawiono | szczegółową | charakterystykę
poszczególnych bloków funkcjonalnych urządzenia.

### 4.2.1. Jednostka centralna

Jako główny sterownik systemu wybrano moduł deweloperski ESP32-DevKitC V4 (widocznym na rysunku 4.1) firmy Espressif Systems. Decyzja ta podyktowana była obecnością dwurdzeniowego procesora, który umożliwia jednoczesną obsługę stosu komunikacyjnego Wi-Fi oraz zadań czasu rzeczywistego (akwizycja danych z czujników). Mikrokontroler pracuje w standardzie napięciowym 3,3 V i dysponuje wystarczającą liczbą interfejsów sprzętowych (UART, SPI, TWAI/CAN) do obsługi wszystkich założonych modułów bez konieczności stosowania ekspanderów wyprowadzeń. [15]

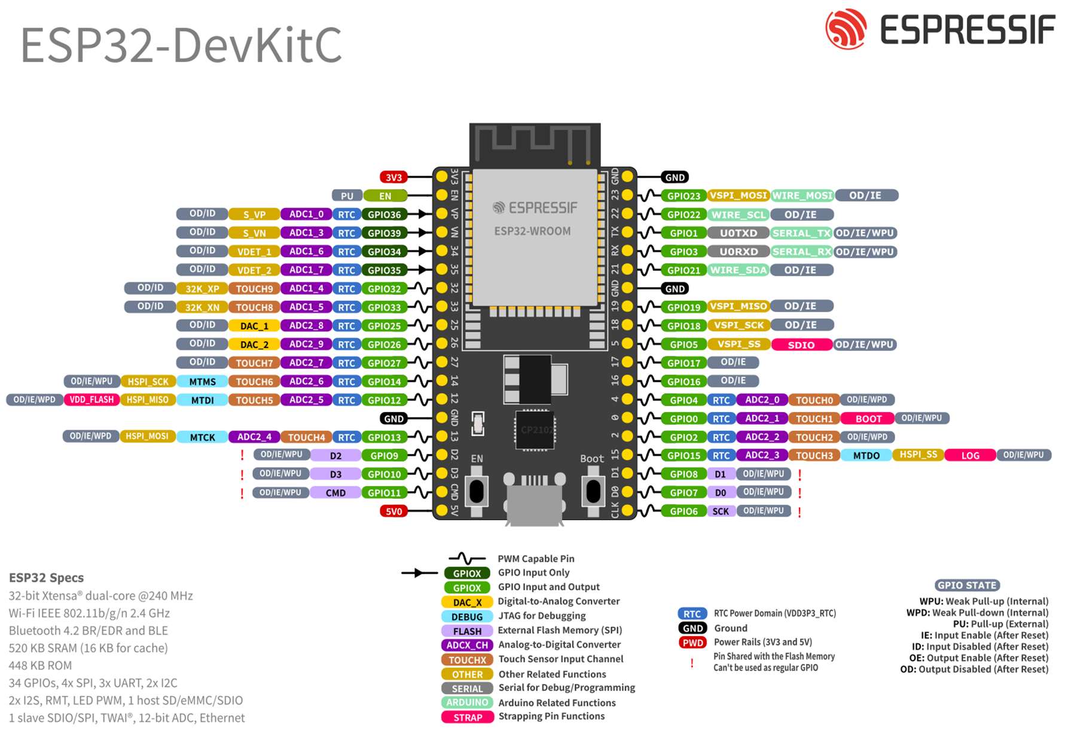
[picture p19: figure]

23

Rys. 4.1. Schemat wyprowadzeń ESP32-DevKitC V4. [15]

### 4.2.2. Układy peryferyjne

### 1. Moduł pozycjonowania GNSS

Do określania pozycji geograficznej wykorzystano układ Quectel LC76G. Jest to odbiornik Multi-GNSS obsługujący systemy GPS, GLONASS, Galileo oraz BeiDou, co zapewnia wysoką precyzję i szybkość ustalania pozycji nawet w trudnych warunkach terenowych. Komunikacja z mikrokontrolerem odbywa się za pośrednictwem interfejsu UART (piny GPIO 16 i 17), przy prędkości transmisji 9600 bps. Dodatkowo, system wykorzystuje sygnał PPS (Pulse Per Second) podłączony do pinu GPIO 32 w celu precyzyjnej synchronizacji czasu systemowego. [16]

### 2. Komunikacja z magistralą CAN

W celu odczytu danych telemetrycznych z pojazdu (np. prędkość pojazdu), zastosowano zewnętrzny transceiver CAN-PAL oparty na układzie TJA1051T/3. Pełni on rolę medium fizycznego, konwertując poziomy napięć magistrali różnicowej CAN na poziomy logiczne akceptowane przez sterownik CAN (TWAI) wbudowany w układ ESP32. Transceiver podłączono do pinów GPIO 21 (RX) oraz GPIO 22 (TX). [17]

24

### 3. Pomiar temperatury

Do pomiaru temperatury wykorzystano cyfrowy czujnik temperatury DS18B20, wykorzystujący magistralę 1-Wire o parametrach technicznych:

- Zakres pomiarowy: od -55 °C do +100 °C. (ograniczenie do 100 °C wynika z wytrzymałości przewodów.)
- Dokładność: ±0,5 °C (w zakresie od -10 °C do +85 °C).
- Rozdzielczość: od 9 do 12 bitów.

Został on podpięty do GPIO 4 co pozwoliło na monitorowanie temperatury otoczenia lub, w zależności od montażu, temperatury wewnątrz pojazdu. [18]

### 4. Pamięć masowa

W celu zapewnienia redundancji danych oraz możliwości pracy w trybie offline, system wyposażono w moduł czytnika kart microSD komunikujący się poprzez magistralę SPI (piny GPIO 5, 18, 19, 23). Umożliwia to zapis danych do archiwizacji lub bufforowanie danych w przypadku braku połączenia z siecią Wi-Fi.

### 4.2.3. Układ zasilania

Ze względu na specyfikę pracy w pojeździe, zaprojektowano hybrydowy układ zasilania:

- Wejścia zasilania: urządzenie może być zasilane z instalacji 12 V pojazdu (poprzez złącze OBDII) lub z portu USB-C.
- Przetwornica Step-Down: napięcie 12 V jest obniżane do 5 V za pomocą przetwornicy impulsowej.
- Zabezpieczenie przetwornicy: zastosowano diodę Schottky’ego co pozwala na bezprzerwowe przełączanie między zasilaniem USB-C lub 12 V z instalacji pojazdu.
- Zasilanie awaryjne (UPS): ogniwo Li-Ion typu 18650 (Panasonic NCR18650B) wraz z modułem ładowania i przetwornicą podwyższającą, która zapewnia ciągłość pracy urządzenia po wyłączeniu zapłonu w pojeździe.

25

### 4.3. Architektura oprogramowania

Oprogramowanie urządzenia zaimplementowano w języku C++ z wykorzystaniem frameworka Arduino dla platformy ESP32. Ze względu na konieczność równoległej obsługi wielu procesów asynchronicznych, takich jak akwizycja danych z czujników, obsługa stosu sieciowego TCP/IP, operacje plikowe oraz obsługa żądań HTTP, zrezygnowano z klasycznej pętli głównej (super-loop) na rzecz systemu operacyjnego czasu rzeczywistego FreeRTOS.

### 4.3.1. Organizacja kodu źródłowego i struktura plików

Kod źródłowy projektu został przygotowany w środowisku Visual Studio Code z wykorzystaniem Arduino IDE jako narzędzia do wgrywania kodu na ESP32. Zarządzanie cyklem życia oprogramowania oraz historią zmian realizowano przy użyciu rozproszonego systemu kontroli wersji Git. Kompletne repozytorium projektu, zawierające pełną strukturę katalogów, pliki konfiguracyjne oraz dokumentację techniczną, zostało umieszczone w serwisie hostingowym GitHub. Takie podejście umożliwia łatwą replikację środowiska programistycznego oraz weryfikację poszczególnych etapów powstawania oprogramowania. Kod źródłowy podzielono na moduły funkcjonalne zgodnie z zasadami programowania obiektowego. Poniżej przedstawiono charakterystykę kluczowych plików projektu:

- main.ino: zawiera konfigurację sprzętową (setup()), inicjalizację obiektów systemowych (kolejki, semafory) oraz implementację głównego zadania CoordinatorTask,
- SensorData.h: plik nagłówkowy definiujący globalną strukturę danych oraz mapowania dla serializacji JSON (X-Macro). Jest to jedyne miejsce definicji parametrów telemetrycznych, co gwarantuje spójność w całym projekcie,
- SdModule: zaawansowany menedżer pamięci masowej. Odpowiada za fizyczny zapis na kartę SD i rotację plików archiwalnych,
- ThingsBoardClient: obsługuje protokół MQTT dla platfromy Thingsboard, w tym autoryzację, przesyłanie telemetrii oraz odbiór atrybutów zdalnej konfiguracji,

26

- WiFiManager: moduł zarządzający łącznością. Implementuje logikę skanowania i wyboru najlepszego punktu dostępowego z listy znanych sieci,
- WebServerModule: obsługuje lokalny serwer HTTP, udostępniając interfejs mapy,
- GpsModule / CanModule: klasy warstwy abstrakcji sprzętowej. Ukrywają one złożoność komunikacji UART/TWAI, udostępniając wyższym warstwom gotowe, przetworzone dane (np. prędkość w km/h, współrzędne geograficzne),
- TimeManager: moduł odpowiedzialny za synchronizację czasu. Zarządza priorytetami źródeł czasu (GPS > NTP > RTC) i dostarcza spójny znacznik czasowy Unix Timestamp dla wszystkich logowanych zdarzeń.

### 4.3.2. Podział na zadania

System operacyjny zarządza pulą niezależnych wątków o zróżnicowanych priorytetach:

- CoordinatorTask: cykliczne wyzwalanie pomiarów i agregacja danych (Snapshot),
- TaskGPS / TaskTemp / TaskCAN: obsługa poszczególnych czujników i protokołów komunikacyjnych,
- TaskDataSync: krytyczny proces odpowiedzialny za opróżnianie bufora danych (wysyłka MQTT oraz zapis SD),
- TaskWiFi: monitorowanie stanu połączenia i automatyczna reasocjacja,
- TaskWebServer: obsługa żądań HTTP od klientów lokalnych (przeglądarka),
- TaskSleep: zarządzanie energią i procesem bezpiecznego wyłączania urządzenia.

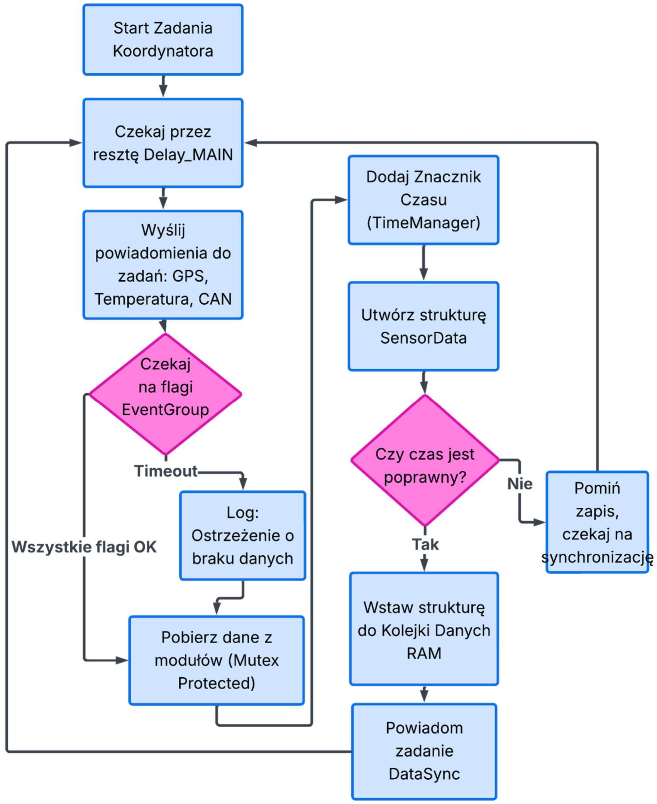
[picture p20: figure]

27

Rys. 4.2. Diagram funkcjonalny zadania koordynatora

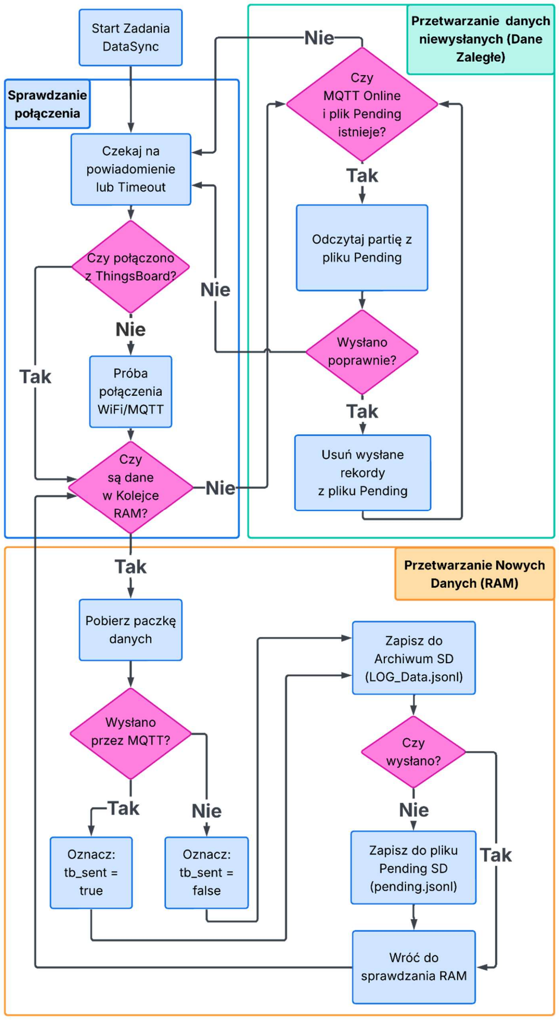
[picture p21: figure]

28

Rys. 4.3. Diagram funkcjonalny zadania synchronizacji danych

29

### 4.3.3. Użyte biblioteki

Efektywna realizacja oprogramowania wbudowanego wymagała wykorzystania sprawdzonych bibliotek open-source, które zapewniają stabilność działania oraz abstrakcję warstwy sprzętowej. Poniżej zestawiono kluczowe biblioteki użyte w projekcie wraz z uzasadnieniem ich doboru.

- ArduinoJson [19]: jest to standard w środowisku Arduino służący do manipulacji danymi w formacie JSON. W projekcie biblioteka ta pełni kluczową rolę w formowaniu pakietów telemetrycznych wysyłanych do brokera MQTT. Pozwala na dynamiczne tworzenie struktur danych, co jest niezbędne przy zmiennej liczbie parametrów.
- PubSubClient [20]: biblioteka implementująca klienta protokołu MQTT. Została wybrana ze względu na swoją niezawodność, minimalne zużycie pamięci oraz pełną obsługę poziomów Quality of Service. Odpowiada za utrzymywanie połączenia z brokerem, obsługę mechanizmu „Keep-Alive” oraz publikowanie i subskrybowanie tematów.
- TinyGPS++ [21]: biblioteka służąca do parsowania surowego strumienia danych NMEA 0183, odbieranego z modułu GNSS przez interfejs UART. Jej obiektowa struktura pozwala na łatwą ekstrakcję kluczowych informacji, takich jak szerokość i długość geograficzna, wysokość n.p.m., prędkość oraz czas, eliminując konieczność ręcznego analizowania ciągów znaków.
- OneWire [22] oraz DallasTemperature [23]: zestaw bibliotek obsługujący komunikację na magistrali 1-Wire. OneWire realizuje niskopoziomową obsługę protokołu, natomiast DallasTemperature dostarcza wysokopoziomowy interfejs do obsługi cyfrowych czujników temperatury z rodziny DS18B20, umożliwiając ich adresowanie i odczyt w trybie pasożytniczym.
- ESP32-TWAI-CAN [24]: biblioteka stanowiąca nakładkę dla wbudowanego w układ ESP32 kontrolera TWAI (Two Wire Automotive Interface), kompatybilnego ze standardem CAN 2.0B. Umożliwia ona filtrowanie ramek sprzętowych oraz obsługę przerwań, co jest kluczowe dla płynnego odczytu danych z magistrali pojazdu bez blokowania głównego wątku procesora.

30

### 4.3.4. Format danych i technika X-Macro

System wykorzystuje format JSON, jednak jego struktura różni się w zależności od medium docelowego:
Format chmurowy (ThingsBoard) [25]: Dane pomiarowe zgrupowane są w obiekcie „values”, co jest wymagane przez API (Application Programming Interface) platformy:

[
{
"ts": 1767307224811,
"values": {
"ts_source": 2,
"lat": 50.0691678,
"lon": 19.9044705,
"alt": 220.32,
"vel": 0.87044,
"temp": 18.8125,
"can_vel": 0,
"ec": 0,
"rssi": -36
}
},
{
"ts": 1767307224811,
"values": {
"ts_source": 2,
"lat": 50.0691678,
"lon": 19.9044705,
"alt": 220.32,
"vel": 0.87044,
"temp": 18.8125,
"can_vel": 0,
"ec": 0,
"rssi": -36
}
}
]
Format lokalny (Karta SD): Stosowany jest format JSON Lines, gdzie każdy wiersz stanowi płaski obiekt JSON:

{
"ts":1767307224811,
"ts_source":2,
"lat":50.0691678,
"lon":19.9044705,
"alt":220.32,
"vel":0.87044,
"temp":18.8125,
"can_vel":0,
"lgr_ts":1767307224044,
"ltr_ts":1767307224811,
"lcr_ts":0,
"ec":0,
"tb_sent":true,
"rssi":-36
}

31

W celu zapewnienia ścisłej spójności między strukturą danych w pamięci RAM mikrokontrolera a formatami wyjściowymi (JSON), w pliku nagłówkowym SensorData.h zastosowano zaawansowaną technikę preprocesora C/C++ zwaną X-Macro. Pozwala ona na zdefiniowanie listy pól danych w jednym centralnym miejscu, co eliminuje konieczność wielokrotnego definiowania tych samych struktur kodu i zmniejsza ryzyko błędów.

Poniżej przedstawiono fragment definicji makra mapującego:

#define SENSOR_DATA_MAP(XX) \

XX(uint64_t, ts, "ts", false, true) \
XX(double, lat, "lat", true, true) \
/* ... kolejne definicje pól ... */

Makro to jest rozwijane dwukrotnie w procesie kompilacji, pełniąc dwie odrębne funkcje:

1. do budowy struktury SensorData w pamięci urządzenia,

### 2. do generowania funkcji sensorDataToTb oraz sensorDataToSd, które mapują pola

struktury na odpowiednie klucze JSON.

Zastosowanie | tej techniki | eliminuje ryzyko powszechnych | błędów
programistycznych, takich jak pominięcie nowo dodanego pola w procedurze serializacji.

### 4.3.5. Zaawansowana obsługa pamięci

Moduł „SdModule” implementuje mechanizmy bezpieczeństwa i organizacji danych:

- Automatyczna rotacja archiwum: dane historyczne zapisywane są w plikach z datą w nazwie. Po przekroczeniu 5 MB tworzony jest nowy plik, co ułatwia późniejszą analizę danych oraz zarządzanie pamięcią masową..
- Sprawdzanie karty: przed każdym zapisem weryfikowana jest obecność karty SD. W razie błędu moduł podejmuje próbę ponownej inicjalizacji magistrali SPI.
- Buforowanie danych: obsługuje mechanizm tymczasowego przechowywania danych, które nie zostały jeszcze wysłane do chmury/serwera.

32

- Archiwizacja danych pomiarowych: realizuje stały zapis wszystkich odczytów z czujników do plików na karcie SD, używając formatu JSONL, co pozwala na zachowanie historii pomiarów niezależnie od transmisji sieciowej.

### 4.3.6. Mechanizmy synchronizacji i komunikacji międzyprocesowej

W celu zapewnienia integralności danych współdzielonych pomiędzy wątkami zastosowano mechanizmy synchronizacji dostępne w FreeRTOS:

- Grupy zdarzeń (ang. Event Groups): wykorzystywane przez Koordynatora do oczekiwania na zakończenie pracy przez wszystkie aktywne czujniki (EVENT_GPS_READY, EVENT_TEMP_READY, EVENT_CAN_READY). Pozwala to na synchronizację pomiarów, mimo różnego czasu ich trwania dla poszczególnych sensorów.
- Kolejki (ang. Queues): do przekazywania danych między Koordynatorem a zadaniem synchronizacji (TaskDataSync) zastosowano kolejkę „dataQueue” działającą jako bufor kołowy. Zapobiega to utracie próbek w sytuacjach, gdy zapis na kartę SD lub wysyłka sieciowa ulegną chwilowemu opóźnieniu.
- Muteksy (ang. Mutexes): zabezpieczają dostęp do współdzielonych zasobów sprzętowych, takich jak magistrala SPI (dla karty SD) oraz struktura danych pomiarowych, eliminując ryzyko wyścigów (ang. Race Conditions).

### 4.3.7. Zarządzanie danymi i tryb Offline

System implementuje hybrydowy model zapisu danych, zapewniający ciągłość historii pomiarowej niezależnie od stanu połączenia sieciowego:

- Archiwizacja ciągła: Każdy pomiarowy pakiet danych jest bezwarunkowo zapisywany w lokalnym archiwum na karcie SD w formacie JSON Lines (.jsonl). Pliki są rotowane automatycznie na podstawie rozmiaru.
- Kolejkowanie Offline (Pending): W przypadku braku połączenia z serwerem MQTT, dane trafiają dodatkowo do pliku tymczasowego (pending.jsonl). Po odzyskaniu połączenia, zadanie TaskDataSync wysyła zaległe pakiety danych, a następnie usuwa je z bufora lokalnego.

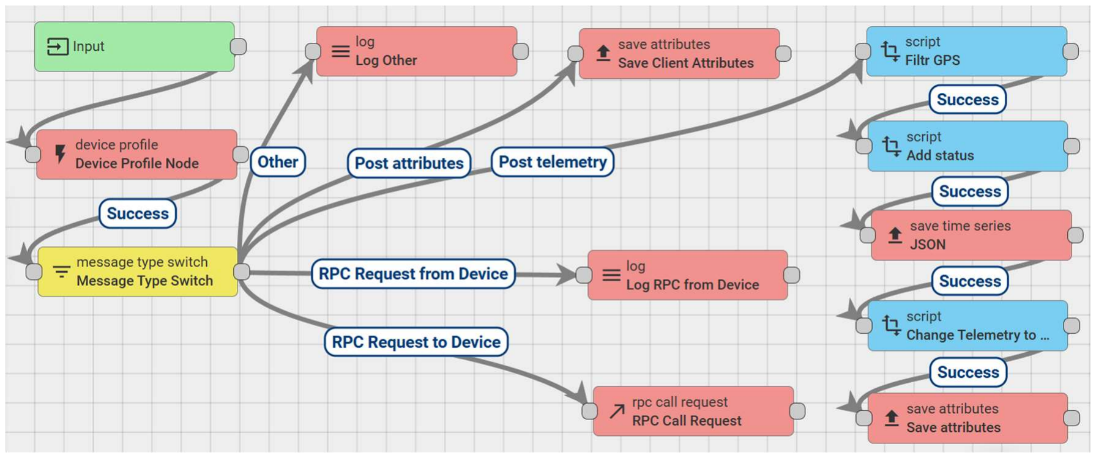
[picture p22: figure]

33

### 4.3.8. Synchronizacja czasu

Kluczowym elementem systemu jest moduł TimeManager, który utrzymuje spójny czas systemowy (Unix Timestamp). System priorytetowo synchronizuje się z precyzyjnym sygnałem GPS, a w przypadku jego braku płynnie przechodzi na czas pobrany z sieci Wi-Fi (jeśli dostępny) lub wewnętrzny licznik RTC, gwarantując chronologiczną spójność logowanych danych.

### 4.4. Integracja z platformą ThingsBoard

Integralną częścią systemu jest warstwa serwerowa, zrealizowana w oparciu o platformę IoT ThingsBoard. Pełni ona rolę brokera MQTT, silnika reguł (ang. Rule Engine) oraz interfejsu użytkownika (ang. Dashboard). Rozwiązanie to pozwala na centralizację danych pomiarowych, ich wizualizację oraz zdalne zarządzanie parametrami pracy urządzenia bez konieczności fizycznej ingerencji w oprogramowanie układowe.

### 4.4.1. Przetwarzanie danych i Silnik Reguł

Algorytm przetwarzania przychodzących komunikatów MQTT został zdefiniowany za pomocą graficznego edytora reguł (ang. Rule Chain). Strumień danych z urządzenia trafia do węzła wejściowego, gdzie następuje jego klasyfikacja.

Rys. 4.4. Schemat łańcucha reguł skonfigurowanego na serwerze. Widoczne węzły odpowiedzialne za filtrację danych GPS, zapis telemetrii oraz aktualizację atrybutów.

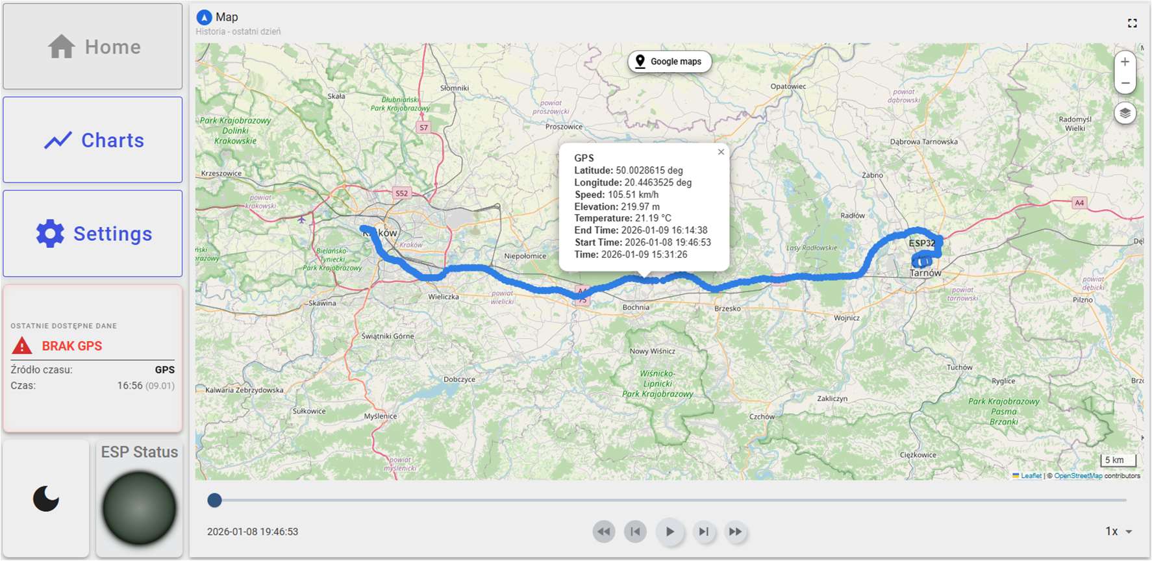
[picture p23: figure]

34

Jak przedstawiono na rysunku 4.4, system automatycznie rozdziela komunikaty na telemetrię (dane pomiarowe) oraz atrybuty (statusy). Zastosowano dedykowane skrypty przetwarzające (Nodes), m.in. Filtr GPS, który wstępnie weryfikuje poprawność współrzędnych przed ich zapisem do bazy danych, oraz skrypty aktualizujące status aktywności urządzenia.

### 4.4.2. Wizualizacja danych i monitoring

Interfejs użytkownika został zaprojektowany w formie interaktywnego pulpitu (ang. Dashboard), podzielonego na sekcje tematyczne. Sekcja mapy (rysunek 4.5) wykorzystuje element interfejsu „Route Map”, który na podkładzie OpenStreetMap wizualizuje aktualną pozycję pojazdu oraz historię przebytej trasy. Interfejs umożliwia odtwarzanie przebiegu trasy w czasie (funkcja Time Window), co pozwala na analizę dynamiki przemieszczania się obiektu.

Rys. 4.5. Wizualizacja trasy przejazdu na mapie cyfrowej. Widoczny znacznik ostatniej pozycji oraz ślad historii przemieszczania.

Do monitorowania parametrów bieżących przygotowano panel „Charts” (rysunek 4.6). Zawiera on wskaźniki cyfrowe prezentujące prędkościomierz, temperaturę otoczenia, poziom sygnału Wi-Fi (RSSI) oraz status połączenia. Wykresy liniowe u dołu ekranu pozwalają na korelację parametrów w czasie, np. wpływu wzniesień terenu na prędkość pojazdu.

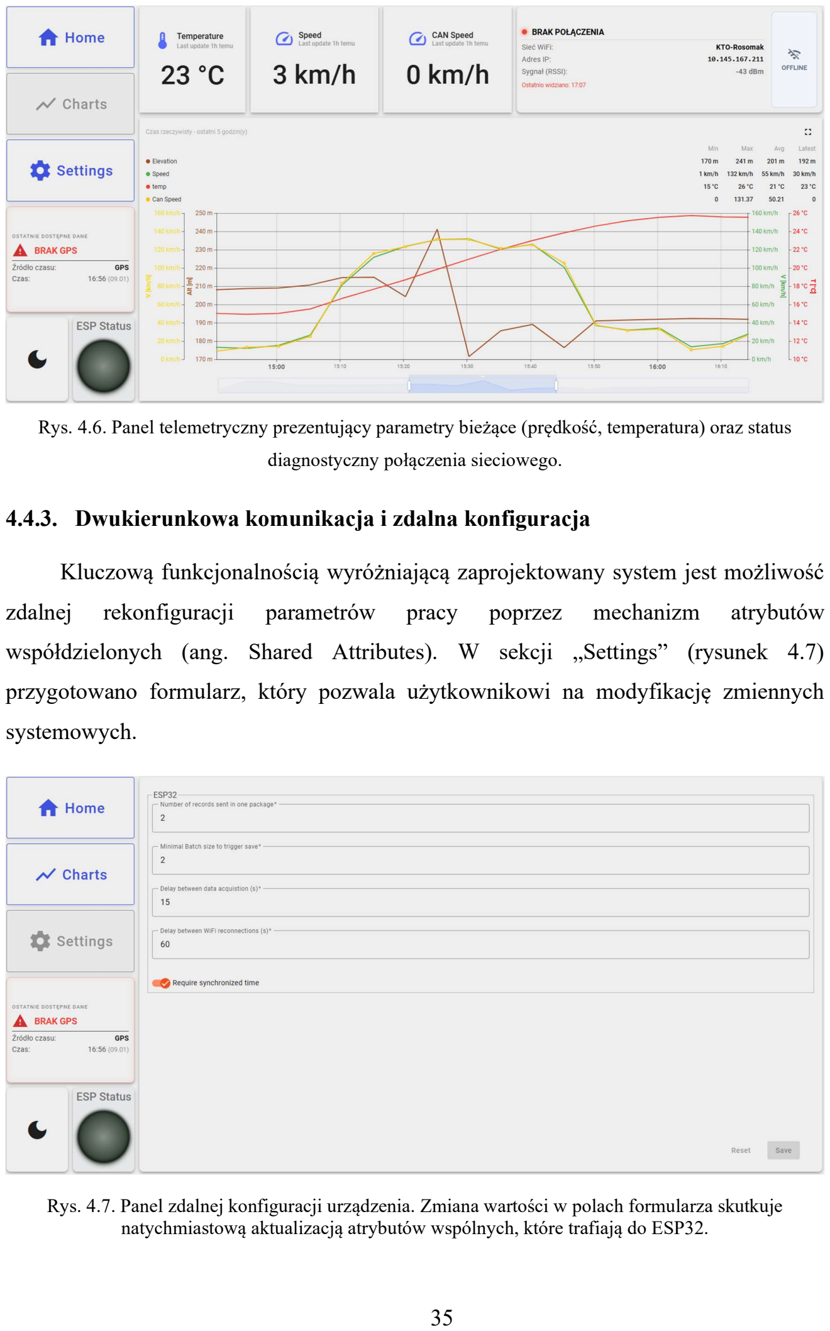
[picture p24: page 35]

35

Rys. 4.6. Panel telemetryczny prezentujący parametry bieżące (prędkość, temperatura) oraz status diagnostyczny połączenia sieciowego.

### 4.4.3. Dwukierunkowa komunikacja i zdalna konfiguracja

Kluczową funkcjonalnością wyróżniającą zaprojektowany system jest możliwość
zdalnej | rekonfiguracji | parametrów | pracy | poprzez | mechanizm | atrybutów
współdzielonych (ang. Shared Attributes). W sekcji „Settings” (rysunek 4.7) przygotowano formularz, który pozwala użytkownikowi na modyfikację zmiennych systemowych.

Rys. 4.7. Panel zdalnej konfiguracji urządzenia. Zmiana wartości w polach formularza skutkuje natychmiastową aktualizacją atrybutów wspólnych, które trafiają do ESP32.


36

Zmiana wartości w tych polach powoduje wysłanie komunikatu aktualizacji danych do urządzenia. Oprogramowanie ESP32, dzięki zaimplementowanej funkcji attributesCallback, odbiera nowe nastawy (pod warunkiem aktywnego połączenia z siecią WiFi) i natychmiast dostosowuje cykl pracy koordynatora zadań, co pozwala na elastyczne zarządzanie zużyciem energii i częstotliwością próbkowania.

### 4.5. Budowa prototypu

Proces realizacji urządzenia został podzielony na etap opracowania schematu połączeń elektrycznych (rysunki 4.8, 4.9, 4.10, 4.11) oraz fizyczny montaż prototypu. Prototyp wykonano z wykorzystaniem płytki uniwersalnej, co pozwoliło na trwałe połączenie komponentów przy zachowaniu możliwości modyfikacji połączeń. Najpierw zamontowano główne moduły, a następnie całość uzupełniono o diody sygnalizacyjne LED (dla statusu Wi-Fi, GPS i zapisu SD), diodę Schottky’ego oraz przełącznik zasilania.

Rys. 4.8. Schemat połączeń elementów.


37

Rys. 4.9. Schemat połączeniowy ESP32.

Rys. 4.10. Schemat połączeniowy zasilania.


38

Rys. 4.11. Schemat połączeniowy układów peryferyjnych.


39

Gotowy prototyp urządzenia przedstawiono na rysunkach 4.12 oraz 4.13.

Rys. 4.12. Widok otwartego prototypu urządzenia. Widoczne osadzone ESP32 oraz moduły peryferyjne na płytce uniwersalnej.

Rys. 4.13. Urządzenie przygotowane do testów.

40

### 4.6. Testy

W celu potwierdzenia zgodności wykonanego urządzenia z założeniami projektowymi, przeprowadzono testy. Proces weryfikacji podzielono na testy laboratoryjne, obejmujące sprawdzenie podsystemów elektrycznych, oraz testy drogowe, mające na celu ocenę pracy urządzenia w warunkach rzeczywistej eksploatacji w pojeździe.

### 4.6.1. Weryfikacja elektryczna i uruchomieniowa

Pierwszym etapem testów była kontrola poprawności montażu oraz stabilności zasilania. Przed instalacją mikrokontrolera w podstawce, zweryfikowano multimetrem napięcie wyjściowe fabrycznie skonfigurowanej przetwornicy Step-Down. Potwierdzono stabilną wartość 5 V, co jest napięciem bezpiecznym dla liniowego stabilizatora napięcia (ang. Low Dropout Regulator) znajdującego się na płytce rozwojowej ESP32.

Następnie zweryfikowano działanie układu podtrzymania zasilania (UPS – Uninterruptible Power Supply). Symulowano nagłe odłączenie zasilania głównego (samochodowego), potwierdzając, że urządzenie płynnie przełącza się na zasilanie z ogniwa Li-Ion 18650, nie powodując przy tym resetu mikrokontrolera.

W kolejnym kroku przeprowadzono pomiary poboru prądu w dwóch charakterystycznych scenariuszach pracy, co pozwoliło oszacować czas autonomii urządzenia na zasilaniu awaryjnym. Procedura pomiarowa obejmowała podłączenie sond multimetru do nóżek przełącznika (przy wyłączonym przełączniku). Urządzenie pomiarowe było ustawione na pomiar prądu stałego o wartości 10 A.

Poniżej przedstawiono metodologię wyznaczenia średniego poboru prądu oraz czasu pracy dla ogniwa Panasonic NCR18650B o pojemności nominalnej 3400 mAh.

### 1. Scenariusz OFFLINE: symuluje pracę poza zasięgiem zaufanej sieci Wi-Fi. W tym

trybie urządzenie większość czasu spędza w stanie uśpienia GPS, wybudzając się cyklicznie na akwizycję danych i rzadkie skanowanie sieci. Obliczenia zostały wykonane dla okresu 300 s.

41

Zdarzenie A (Akwizycja danych, zapis na kartę SD oraz skanowanie sieci): 160 mA przez 2s co 5 minut.

- Liczba wystąpień w 300 s: 1
- Całkowity czas trwania: 5 [s]
- Ładunek: 5 ∗ 160 = 800 [mAs]

Zdarzenie B (Akwizycja danych oraz zapis na kartę SD): 80 mA przez 5 s co 30 s.

- Liczba wystąpień w 300 s:

− 1 = 9
- Całkowity czas trwania: 9 ∗ 5 = 45 [s]
- Ładunek: 45 ∗ 80 = 3600 [mAs]

Zdarzenie C (Akwizycja danych): 60 mA przez 4s co 15s.

- Liczba wystąpień w 300 s:

− 9 − 1 = 10
- Całkowity czas trwania: 10 ∗ 4 = 40 [s]
- Ładunek: 40 ∗ 60 = 2400 [mAs]

Zdarzenie D (Uśpienie GPS): 50 mA w pozostałym czasie.

- Całkowity czas trwania: 300 − 5 − 45 − 40 = 210 [s]
- Ładunek: 210 ∗ 50 = 10500 [mAs]

Średni pobór prądu:

I =

800 + 3600 + 2400 + 10500
300 | = 57,67 [mA]. | (4.1)

Szacowany czas pracy:

t =

3400
57,67 = 58,96 [ℎ]. | (4.2)

### 2. Scenariusz ONLINE: symuluje pracę w zasięgu sieci zaufanej. W tym trybie

urządzenie cały czas jest podłączone do sieci WiFi co zwiększa prąd bazowy układu. Akwizycja danych przebiega cyklicznie co ustalony interwał.

42

Zdarzenie A (Akwizycja danych, zapis na kartę SD oraz transmisja): 100 mA przez 6 s co 30 s.

- Liczba wystąpień w 30 s: 1
- Czas trwania: 6 [s]
- Ładunek: 6 ∗ 100 = 600 [mAs]

Zdarzenie B (Akwizycja danych oraz zapis na kartę SD): 80 mA przez 4 s co 15 s.

- Liczba wystąpień w 30 s: 1
- Czas trwania: 4 [s]
- Ładunek: 4 ∗ 80 = 320 [mAs]

Zdarzenie C (Uśpienie GPS oraz WiFi w stanie spoczynku): 65 mA w pozostałym czasie.

- Całkowity czas trwania: 30 − 5 − 5 = 20 [s]
- Ładunek: 20 ∗ 65 = 1300 [mAs]

Średni pobór prądu:

I =

600 + 320 + 1300
30 | = 74 [mA]. | (4.3)

Szacowany czas pracy:

t =

3400
74 = 45,95 [ℎ]. | (4.4)

### 4.6.2. Testy funkcjonalne oprogramowania

Testy funkcjonalne polegały na weryfikacji działania poszczególnych modułów programowych przy użyciu wbudowanych mechanizmów diagnostycznych, takich jak logi na porcie szeregowym oraz diody statusowe LED:

Sygnalizacje stanu urządzenia zweryfikowano za pomocą diód:

- LED_WiFi (GPIO 27): Zapala się po poprawnym uzyskaniu adresu IP,

43

- LED_GPS (GPIO 26): Sygnalizuje uzyskanie poprawnego położenia geograficznego,
- LED_SD (GPIO 25): W stanie normalnym dioda ta świeci światłem ciągłym, sygnalizując poprawną inicjalizację karty i gotowość systemu plików. Zgaśnięcie diody informuje o błędzie krytycznym zapisu lub braku nośnika.

Symulacja awarii nośnika: przeprowadzono test polegający na fizycznym wyjęciu karty microSD podczas pracy urządzenia. System prawidłowo wykrył brak nośnika (zgaszenie diody LED_SD i ustawienie flagi błędu w telemetrii). Po ponownym włożeniu karty, mechanizm „SdModule::ensureReady” automatycznie przywrócił sprawność systemu plików, wznawiając logowanie danych bez konieczności restartu zasilania.

Watchdog Timer: sprawdzono odporność systemu na zawieszenie. Wymuszona pętla nieskończona w jednym z zadań (Tasks) spowodowała poprawną reakcję układu Watchdog i restart systemu po upływie zdefiniowanego czasu (120 sekund).

Weryfikacja zarządzania zasobami: W celu potwierdzenia stabilności oprogramowania podczas pracy pod dużym obciążeniem, przeprowadzono monitorowanie zużycia pamięci operacyjnej RAM. Krytycznym scenariuszem testowym był moment synchronizacji danych z pliku buforowego („Pending”), który wymaga jednoczesnej obsługi systemu plików (odczyt z karty SD) oraz transmisji sieciowej (obsługa stosu TCP/IP).

Poniższy log z portu szeregowego przedstawia zrzut diagnostyczny z portu szeregowego zarejestrowany podczas trwania procesu synchronizacji danych z ThingsBoard:

----- MEMORY STATUS -----
[HEAP] Free: 109972 bytes, Min Free: 93592 bytes
[TASK] Coordinator: 2336 bytes free stack [TASK] WiFi: 2184 bytes free stack [TASK] DataSync: 3624 bytes free stack
[TASK] GPS: | 2044 bytes free stack
[TASK] Temp: | 2084 bytes free stack
[TASK] WebServer: 2572 bytes free stack [TASK] Sleep: 1524 bytes free stack ------------------------

44

Analiza logów pozwala na sformułowanie następujących wniosków:

Brak wycieków pamięci: Wartość wolnej sterty ([HEAP] Free) utrzymuje się na poziomie ok. 109 kB, a najniższa zarejestrowana wartość (Min Free) wynosi ponad 93 kB, co stanowi bezpieczny margines dla układu ESP32.

Bezpieczeństwo wątków: Każde z zadań FreeRTOS posiada zapas wolnej pamięci stosu (free stack) wynoszący minimum 1500 bajtów. Oznacza to, że rozmiary stosów zadeklarowane w kodzie źródłowym zostały dobrane poprawnie i nie występuje ryzyko przepełnienia stosu (ang. Stack Overflow), co mogłoby prowadzić do niekontrolowanego restartu urządzenia.

Analiza zajętości pamięci masowej: Przeprowadzono analizę wielkości generowanych plików danych w formacie JSON Lines (.jsonl). Na podstawie pomiarów (poprzez opcje „Właściwości” w MS Windows) ustalono, że pojedynczy pakiet telemetryczny (zawierający znacznik czasu, współrzędne, prędkość, temperaturę i statusy) zajmuje średnio 208 bajtów.

Przy założeniu wykorzystania karty pamięci o pojemności użytkowej 29,1 GB oraz ciągłej pracy urządzenia z domyślnym interwałem zapisu wynoszącym 15 sekund, przeprowadzono szacunkowe obliczenia czasu zapełnienia nośnika:

Pojemność karty SD: 29,1 [GB] ≈ 3,12 ∗ 10 [B]

Częstotliwość zapisu: 1 na 15 [s]

Liczba pakietów na dobę: 4 ∗ 60 ∗ 24 ∗ 365 = 2 102 400

Rozmiar pojedynczego pakietu: 208 [B]

Maksymalna liczba pakietów:

N =

3,12 ∗ 10
208 | = 150 000 000. | (4.5)

Szacowany czas pracy do zapełnienia karty:

t =

150 000 000
2 102 400 ≈ 71 lat. | (4.6)


45

Powyższe obliczenia wskazują, że przy przyjętym formacie danych i interwale próbkowania, pojemność karty SD jest w praktyce niewyczerpywalna w całym cyklu życia urządzenia, nawet przy uwzględnieniu narzutu systemu plików (FAT32).

### 4.6.3. Testy w warunkach eksploatacyjnych

Kluczowym elementem weryfikacji był test drogowy mający na celu sprawdzenie mechanizmu buforowania danych. Przeprowadzono przejazd testowy na trasie o długości ok. 95 km (rysunek 4.14).

Procedura testowa:

### 1. uruchomienie urządzenia w zasięgu sieci (Synchronizacja czasu, wysyłka

próbna),

2. celowe wyłączenie punktu dostępowego Wi-Fi na czas jazdy,

### 3. weryfikacja zachowania systemu: urządzenie, nie mogąc połączyć się

z brokerem MQTT, zaczęło zapisywać dane do pliku buforowego pending.jsonl na karcie SD,

4. ponowne włączenie sieci Wi-Fi,

### 5. po dotarciu do punktu docelowego urządzenie, automatycznie wykryło

dostępność sieci i przesłało zaległe pakiety danych z pliku „pending” do platformy ThingsBoard, zachowując chronologię zdarzeń.

Rys. 4.14. Trasa zarejestrowana poprzez prototyp urządzenia i wyświetlona na platformie ThingsBoard.


46

### 4.5.4. Ocena jakości danych GNSS

Dokładność modułu LC76G oceniono poprzez porównanie zarejestrowanej ścieżki na platformie ThingsBoard z trasą referencyjną pobraną z Google Maps Timeline (rysunek 4.15). Analiza wykazała, że w otwartym terenie błąd pozycjonowania w większości przypadków nie przekraczał 5 metrów. Natomiast zauważono również pojedyncze przypadki w których błąd pozycji wynosił nawet 30 metrów. Zauważono również poprawną pracę algorytmu „Cold Start” – czas uzyskania pierwszej pozycji po wybudzeniu urządzenia wynosił średnio poniżej 30 sekund, co jest wartością zgodną z dokumentacją modułu.

Rys. 4.15. Porównanie wycinka trasy zarejestrowanego w ThingsBoard (po lewej) oraz lokalizację w Google Maps (po prawej).

### 4.6.4. Wizualizacja i telemetria

Ostatnim etapem była weryfikacja poprawności danych prezentowanych na platformie ThingsBoard oraz na lokalnym serwerze WWW urządzenia (rysunek 4.16). Potwierdzono, że atrybuty takie jak m.in. prędkość, wysokość oraz temperatura są poprawnie dekodowane z formatu JSON i aktualizowane w czasie rzeczywistym (przy dostępnym połączeniu sieciowym).


47

Rys. 4.16. Widok moblinego serwera HTTP hostowanego na ESP32.

48

### 5. Podsumowanie i wnioski

W ramach niniejszej pracy dyplomowej zaprojektowano, wykonano i przetestowano prototyp systemu lokalizacji i telemetrii pojazdu, oparty na mikrokontrolerze ESP32 oraz systemie operacyjnym czasu rzeczywistego FreeRTOS. Głównym celem projektu było zbudowanie rozwiązania modułowego, które łączyłoby funkcjonalność rejestratora parametrów jazdy z możliwością bezprzewodowej synchronizacji danych z chmurą IoT.

Zrealizowany prototyp spełnia wszystkie założenia funkcjonalne:

- Akwizycja danych: system poprawnie interpretuje strumień NMEA z modułu GNSS oraz odczytuje ramki z magistrali CAN, integrując te dane w spójne pakiety telemetryczne,
- Niezawodność zapisu: zaimplementowany mechanizm transmisji oraz zapisu skutecznie gromadzi dane na karcie pamięci w przypadku braku łączności, a następnie automatycznie synchronizuje je z serwerem ThingsBoard po powrocie do bazy,
- Architektura oprogramowania: wykorzystanie RTOS pozwoliło na równoległą obsługę zadań krytycznych czasowo (CAN, GPS) oraz zadań o wysokim czasie wykonania (zapis na SD, obsługa stosu TCP/IP).

### 5.1. Napotkane problemy i ograniczenia realizacyjne

W toku prac projektowych i wdrożeniowych zidentyfikowano szereg wyzwań technicznych oraz ograniczeń, które wpłynęły na ostateczny kształt prototypu. Poniżej omówiono kluczowe trudności napotkane podczas realizacji pracy.

### 1. Ograniczenia platformy serwerowej (ThingsBoard Demo)

Istotnym wyzwaniem okazały się limity narzucone przez wersję demonstracyjną (Community Edition) platformy ThingsBoard. Zidentyfikowano ograniczenie przepustowości przyjmowania danych telemetrycznych, które uniemożliwiło przesyłanie dużych paczek danych w jednym komunikacie MQTT.

49

- Problem: Próba wysłania tablicy JSON zawierającej więcej niż 2 pakiety pomiarowe skutkowała odrzuceniem połączenia przez brokera lub utratą pakietów.
- Rozwiązanie: | Wymusiło | to | programowe | ograniczenie | parametru
SEND_BATCH_SIZE w oprogramowaniu układowym. System został skonfigurowany tak, aby dzielić dane historyczne (zbuforowane na karcie SD) na mniejsze fragmenty, co wydłużyło czas synchronizacji danych po powrocie urządzenia do trybu online, ale zapewniło stabilność transmisji.

### 2. Kompatybilność z nowoczesnymi systemami bezpieczeństwa pojazdów

(Secure Gateway)

Podczas prób integracji z nowszymi modelami pojazdów (wyprodukowanymi po 2017 roku) napotkano barierę w postaci modułu SGW (Security Gateway).

- Problem: Nowoczesne architektury samochodowe blokują nieautoryzowany dostęp do magistrali CAN, uniemożliwiając odczyt parametrów oraz inżynierię wsteczną ramek bez posiadania certyfikatów producenta i dedykowanego sprzętu odblokowującego.
- Wniosek: Ostatecznie testy funkcjonalne ograniczono do pojazdów starszej generacji, co wskazuje na konieczność stosowania w przyszłości certyfikowanych bramek OBD2 typu „passthru” dla nowszych flot lub bezpośredniego podpięcia się do linii CAN przy np. silniku.

### 3. Wyzwania związane z miniaturyzacją (PCB)

Jednym z założeń projektowych było dążenie do miniaturyzacji urządzenia. Mimo opracowania schematu połączeń, w ramach niniejszej pracy nie udało się zrealizować dedykowanego obwodu drukowanego (PCB – Printed Circuit Board).

- Przyczyna: Ograniczenia czasowe i budżetowe wymusiły pozostanie przy konstrukcji prototypowej opartej na płycie uniwersalnej.
- Skutek: Urządzenie posiada większe gabaryty niż komercyjne odpowiedniki.

50

### 5.2. Wnioski z realizacji

Analiza działania prototypu w warunkach laboratoryjnych i polowych pozwala na sformułowanie następujących wniosków.

- Wydajność platformy sprzętowej: układ ESP32 dysponuje wystarczającą mocą obliczeniową do przetwarzania danych w czasie rzeczywistym, połączeń MQTT oraz obsługi systemu plików, pozostawiając margines zasobów na przyszłą rozbudowę.
- Model komunikacji Wi-Fi: decyzja o wykorzystaniu Wi-Fi jako głównego medium transmisyjnego obniżyła koszty eksploatacji (brak abonamentu GSM) i uprościła konstrukcję urządzenia. Ogranicza to jednak zastosowanie systemu do scenariuszy typu „czarna skrzynka”, wykluczając śledzenie antykradzieżowe w czasie rzeczywistym.
- Złożoność integracji CAN/OBD: choć fizyczny odczyt ramek CAN działa poprawnie, pełna integracja ze standardem OBD2 (ISO 15765) wymaga złożonej implementacji oraz dostosowania zapytań PID do specyfiki konkretnego producenta pojazdu.

### 5.3. Kierunki dalszego rozwoju

Otwarta architektura projektu oraz modułowa budowa kodu źródłowego stwarzają szerokie możliwości rozwoju. Poniżej przedstawiono kluczowe obszary, których implementacja pozwoliłaby na przekształcenie prototypu w pełni funkcjonalny produkt rynkowy.

- Moduł LTE-M / NB-IoT: zastąpienie lub uzupełnienie Wi-Fi modułem komórkowym zapewniłoby ciągłą transmisję danych niezależnie od lokalizacji. Umożliwiłoby to realizację funkcji antykradzieżowych, takich jak powiadomienia „Push” o nieautoryzowanym ruchu pojazdu czy wyjeździe poza wyznaczoną geostrefę (ang. Geofencing).

51

- Aktualizacje OTA (Over The Air): implementacja mechanizmu zdalnej aktualizacji oprogramowania układowego przez Wi-Fi pozwoliłaby na naprawę błędów i dodawanie nowych funkcji bez konieczności fizycznego dostępu do urządzenia.
- Implementacja algorytmu cyklicznego uśpienia: docelowe rozwiązanie powinno opierać się na automatycznej detekcji postoju. Proponuje się wdrożenie logiki, w której system po wykryciu braku przemieszczania się (na podstawie danych GNSS) przez okres 5 minut automatycznie przechodzi w stan głębokiego uśpienia (ang. Deep Sleep). W celu zachowania łączności, układ będzie wybudzany cyklicznie co 10 minut dla wysłania pakietu statusowego, po czym ponownie przejdzie w stan uśpienia.
- Sprzętowy monitoring stanu baterii: w celu zwiększenia niezawodności pracy na zasilaniu akumulatorowym, układ należy rozbudować o dzielnik napięcia podłączony do przetwornika ADC (Analog to Digital Converter) mikrokontrolera ESP32. Umożliwi to ciągły pomiar napięcia ogniwa Li-Ion. Pozwoli to na bezpieczne zamknięcie systemu plików i zakończenie pracy urządzenia przed spadkiem napięcia poniżej poziomu krytycznego, co chroni akumulator przed głębokim rozładowaniem, a dane na karcie SD przed uszkodzeniem.
- Szyfrowanie pamięci masowej: w obecnej wersji pliki na karcie SD są zapisywane jawnym tekstem (JSON). Wdrożenie szyfrowania symetrycznego (np. AES-128 – Advanced Encryption Standard) zabezpieczyłoby dane o trasach i parametrach pojazdu w przypadku kradzieży nośnika.
- Bezpieczna transmisja: implementacja protokołu MQTTS (MQTT over SSL/TLS) z weryfikacją certyfikatów serwera zabezpieczyłaby transmisję przed atakami podczas wysyłki.
- Dedykowane PCB: przeniesienie układu z płytki uniwersalnej na zaprojektowany obwód drukowany (PCB) z wykorzystaniem technologii montażu powierzchniowego (SMD – Surface Mounted Device) pozwoliłoby na znaczną miniaturyzację urządzenia i zwiększenie jego odporności na wibracje występujące w pojeździe.

52

### 6. Wykaz Publikacji

[1] Ciemcioch K. Internet Rzeczy – zastosowanie, zagrożenia, bezpieczeństwo, Zbliżenia Cywilizacyjne, 2023, 19(3), 61–85.
[2] Nores: Telemetria w IoT – co to jest i jak napędza Przemysł 4.0?, Gorzów Śląski: Nores Sp. z o.o. Dostępny: https://nores.pl/telemetria-w-iot-co-to-jest-i-jak-napedza-przemysl-4-0/ (odwiedzona 11.01.2026).
[3] National Instruments: Controller Area Network (CAN) Protocol Overview. Austin: National Instruments Corp. Dostępny: https://www.ni.com/en/shop/seamlessly-connect-to-third-party-devices-and-supervisory-system/controller-area-network--can--overview. html (odwiedzona 11.01.2026).
[4] Sital Technology: CAN Bus Voltage Level: Analyzing the Electrical Potential. Dostępny: https://sitaltech.com/can-bus-voltage-level-analyzing-the-electrical-potential/(odwiedzona 11.01.2026).
[5] Mendel M.: Magistrala CAN (Controller Area Network) konfiguracja i transmisja danych. Zielonka: Wojskowy Instytut Techniczny Uzbrojenia. Dostępny: https://bibliotekanauki.pl/articles/235634.pdf (odwiedzona 11.01.2026).
[6] Usmani M.F.: MQTT Protocol for the IoT - Review Paper. ResearchGate. Dostępny: https://www.researchgate.net/publication/373640610_MQTT_Protocol_for_the_IoT_Review_Paper (odwiedzona 11.01.2026).
[7] Space Economy Academy: Differences Between GNSS Systems. Darmstadt: Space Economy Academy. Dostępny: https://seac-space.com/differences-between-gnss-systems/ (odwiedzona 11.01.2026).
[8] Bernstein D.: NMEA Sentences. Harrisonburg: James Madison University. Dostępny: https://w3.cs.jmu.edu/bernstdh/web/common/help/nmea-sentences.php (odwiedzona 11.01.2026).

53

[9] Quectel Wireless Solutions: LC26G&LC26G-T&LC76G&LC86G Series AGNSS
Application | Note. | Shanghai: | Quectel | Wireless | Solutions. | Dostępny:
https://mm.digikey.com/Volume0/opasdata/d220001/medias/docus/6504/LC26G-LC26
G-T-LC76G-LC86G_Series_AGNSS_Application_Note_V1.1.pdf | (odwiedzona
11.01.2026).
[10] Macekova L., 1-Wire - The Technology for Sensor Networks, Acta Electrotechnica et Informatica, 2012, 12 (4), 52-55.
[11] Barry R.: Mastering the FreeRTOS™ Real Time Kernel: A Hands-On Tutorial Guide. Bristol, Real Time Engineers Ltd 2016.
[12] BearPoint: Lokalizator GPS BearPoint. Wałbrzych: BearPoint. Dostępny: https://bearpoint.pl/produkt/lokalizator-gps-bearpoint/ (odwiedzona 11.01.2026).
[13] Szpiegujemy.com: Lokalizator GPS GL300 Server z długim czasem czuwania. Wrocław: Nexus. Dostępny: https://szpiegujemy.com/product-pol-1690 (odwiedzona 11.01.2026).
[14] Szpiegujemy.com: Lokalizator GPS z hermetyczną obudową i magnesami pod samochód 20000mAh. Wrocław: Nexus. Dostępny: https://szpiegujemy.com/product-pol-1696 (odwiedzona 11.01.2026).
[15] Espressif Systems, ESP32-DevKitC V4 User Guide, Espressif Documentation. Dostępny: https://docs.espressif.com/projects/esp-dev-kits/en/latest/esp32/esp32-devkitc/user_guide.html. (odwiedzona 11.01.2026).
[16] Waveshare, LC76G GNSS Module Wiki, Waveshare Wiki. Dostępny: https://www.waveshare.com/wiki/LC76G_GNSS_Module. (odwiedzona 11.01.2026).
[17] Adafruit Industries, Adafruit CAN PAL Overview, Adafruit Learning System.
Dostępny: | https://learn.adafruit.com/adafruit-can-pal/overview. | (odwiedzona
11.01.2026).

54

[18] Analog Devices, DS18B20: Programmable Resolution 1-Wire Digital Thermometer
Data | Sheet, | Analog | Devices | Technical | Documentation. | Dostępny:
https://www.analog.com/media/en/technical-documentation/data-sheets/ds18b20.pdf. (odwiedzona 11.01.2026).
[19] Benoît B.: ArduinoJson: Efficient JSON serialization for embedded C++. Dostępny: https://arduinojson.org/v7/ (odwiedzona 11.01.2026).
[20] O'Leary N.: PubSubClient: A client library for MQTT messaging. Biblioteka programistyczna. Dostępny: https://github.com/knolleary/pubsubclient (odwiedzona 11.01.2026).
[21] Hart M.: TinyGPSPlus Library. Dostępny: https://github.com/mikalhart/TinyGPS Plus (odwiedzona 11.01.2026).
[22] Stoffregen P. et al.: OneWire Library. Dostępny: https://github.com/PaulStoffregen/OneWire (odwiedzona 11.01.2026).
[23] Burton M. et al.: DallasTemperature Library. Dostępny: https://github.com/milesburton/Arduino-Temperature-Control-Library (odwiedzona 11.01.2026).
[24] Espressif Systems: Two-Wire Automotive Interface (TWAI). Shanghai: Espressif Systems (Shanghai) Co., Ltd. Dostępny: https://docs.espressif.com/projects/esp-idf/en/stable/esp32/api-reference/peripherals/twai.html (odwiedzona 11.01.2026).
[25] | ThingsBoard: | ThingsBoard | Documentation | & | Guides. | Dostępny:
https://thingsboard.io/docs/guides/ (odwiedzona 11.01.2026).

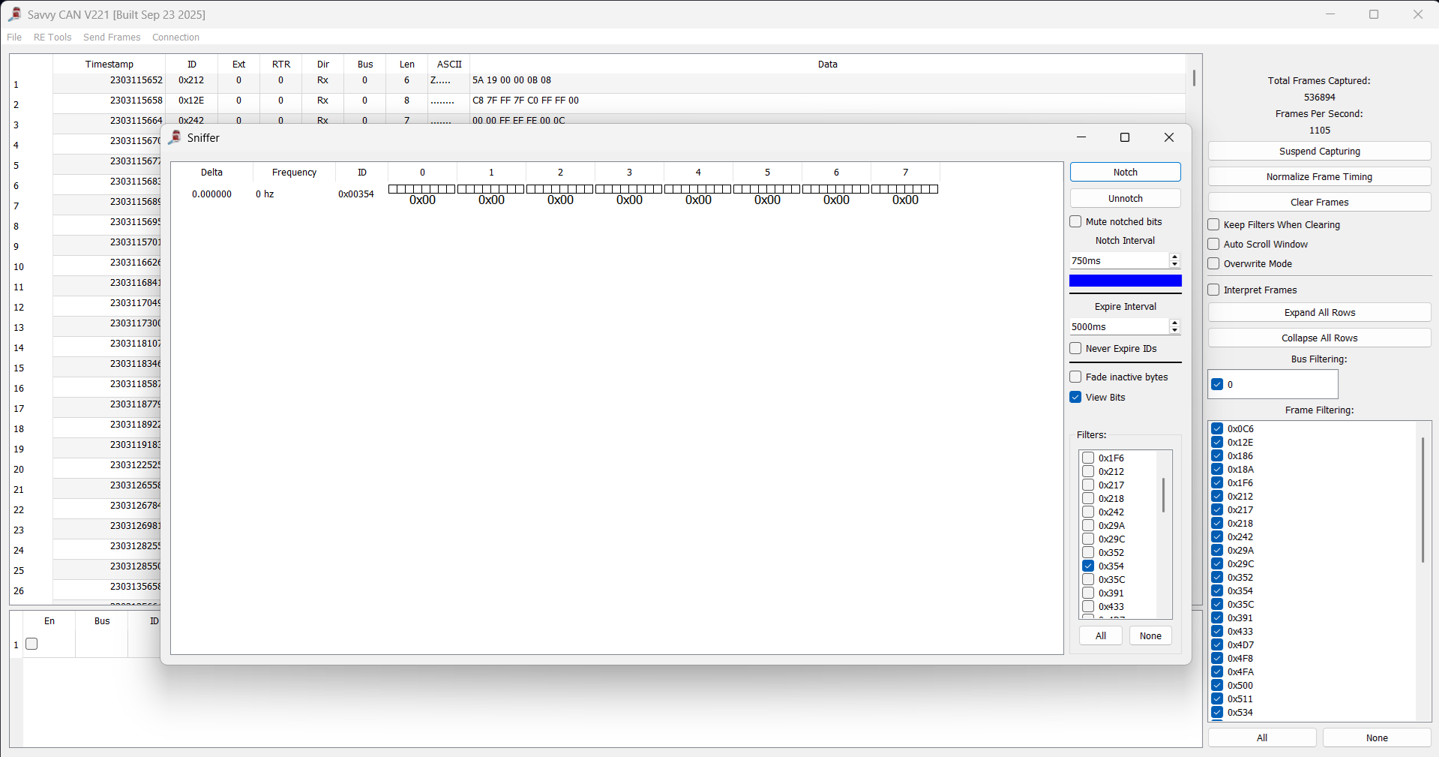
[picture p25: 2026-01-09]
docs/Images/SavvyCAN.png

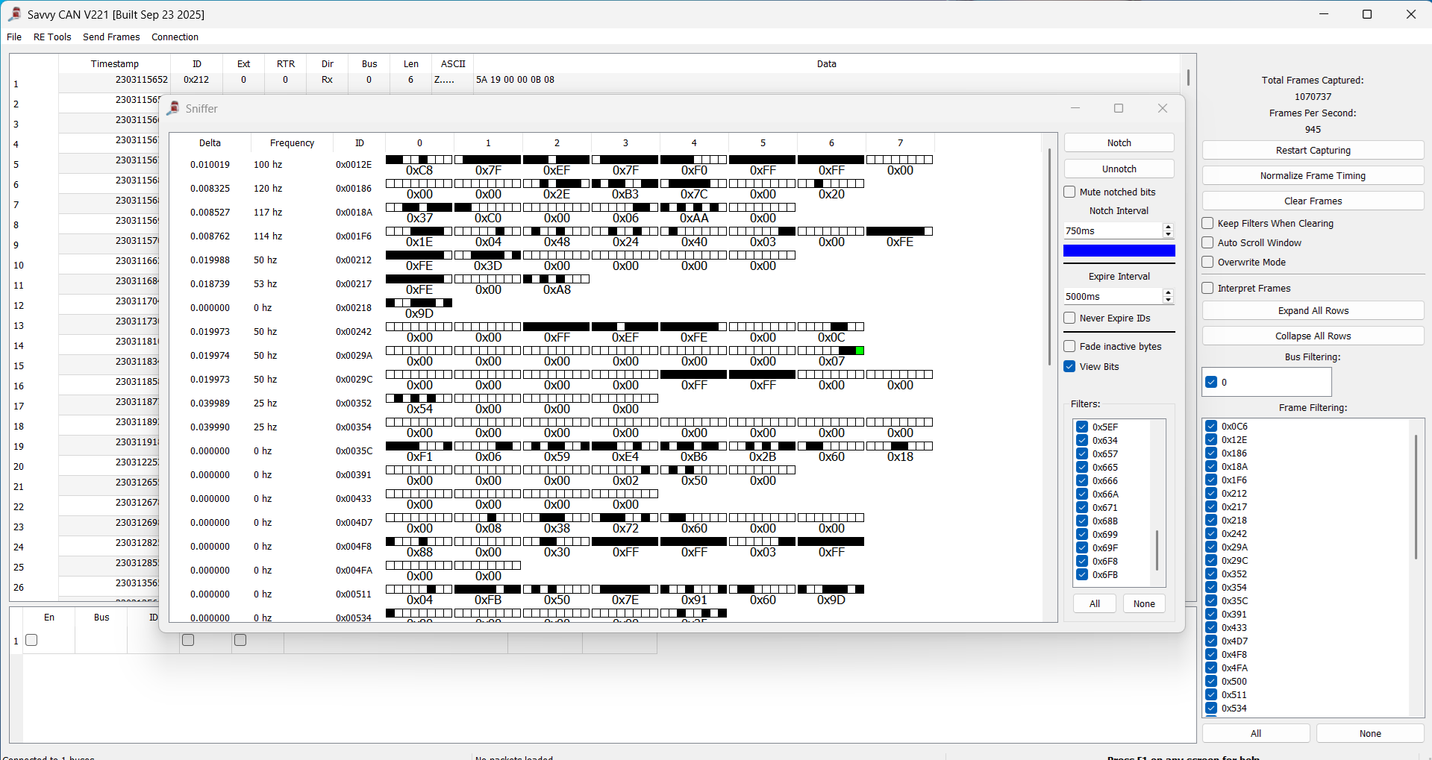
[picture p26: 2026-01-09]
docs/Images/Sniffer.png

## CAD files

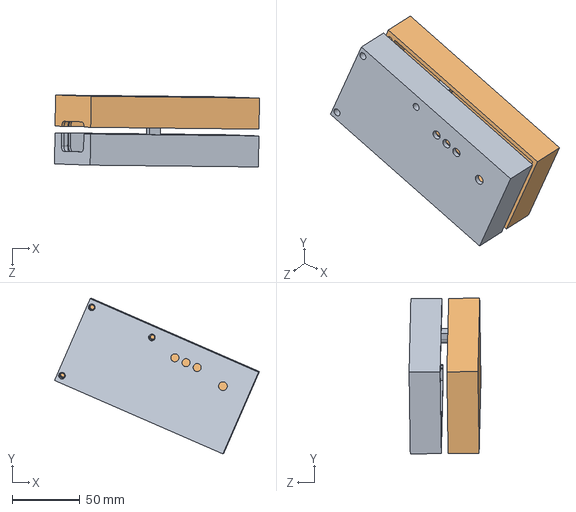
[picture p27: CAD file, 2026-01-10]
3d_models/Obudowa.SLDASM
151.8 x 115.3 x 53.3 mm
Obudowa_dol
Obudowa_gora

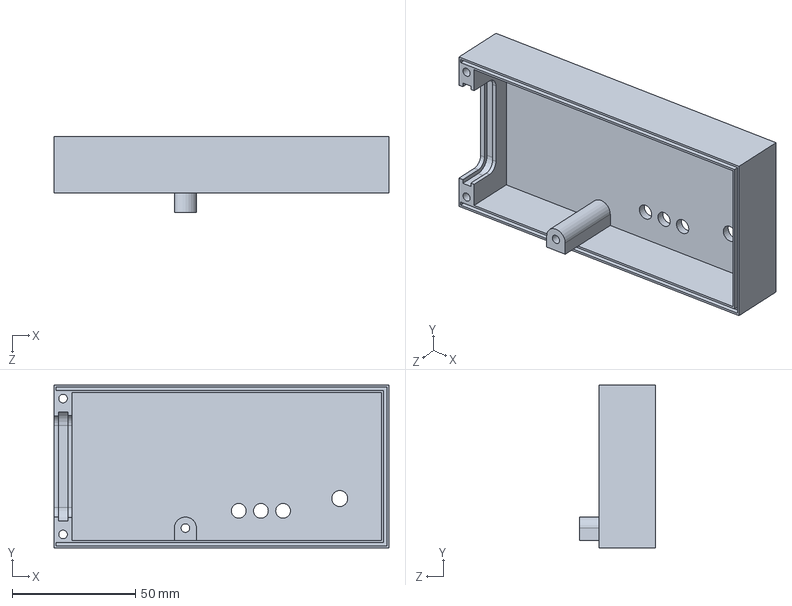
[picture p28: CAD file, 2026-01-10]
3d_models/Obudowa_gora.SLDPRT
136.0 x 66.0 x 31.0 mm

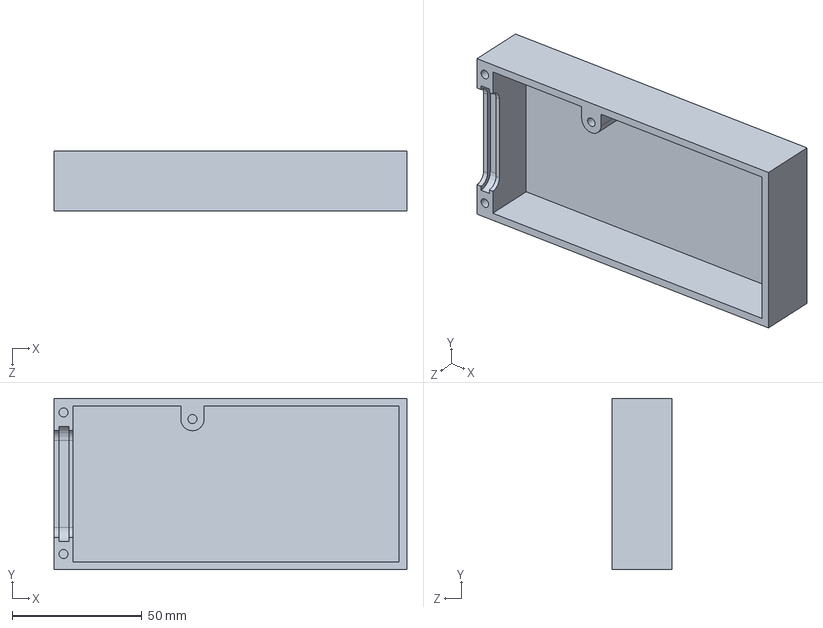
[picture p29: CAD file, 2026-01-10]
3d_models/Obudowa_dol.SLDPRT
136.0 x 66.0 x 23.0 mm

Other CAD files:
3d_models/Obudowa_dol.STL
3d_models/Obudowa_gora.STL

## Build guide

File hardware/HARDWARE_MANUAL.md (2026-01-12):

# 🛠️ Instrukcja Montażu i Dokumentacja Sprzętowa

Dokument zawiera listę części (BOM), schemat połączeń oraz instrukcję montażu dla systemu akwizycji danych GPS/CAN opartego na ESP32.

## 1. Zestawienie Materiałów (BOM)

Ceny są szacunkowe na podstawie wybranych podzespołów (stan na 11.2025).

| Lp. | Nazwa Elementu | Funkcja | Szac. Koszt (PLN) | Link |
| :---: | :--- | :--- | :---: | :--- |
| 1 | **ESP32-DevKitC-32D v4** | Główny mikrokontroler (WiFi/BT) | 25,00 zł | [Kamami](https://kamami.pl/esp32/573333-esp32-devkitc-32d-v4-plytka-rozwojowa-iot-z-modulem-wi-fi-esp-wroom-32d-5906623456529.html) |
| 2 | **Moduł GNSS LC76G** | Odbiornik GPS/GLONASS/Galileo (UART) | 35,00 zł | [Kamami](https://kamami.pl/moduly/1185254-lc76G-multi-gnss-module-supports-gps-bds-glonass-galileo-qzss-5906623423767.html) |
| 3 | **Moduł Czytnika microSD** | Zapis danych offline (SPI) | 10,00 zł | [Kamami](https://kamami.pl/czytniki-kart-pamieci/586607-modul-czytnika-kart-pamieci-microsd-z-konwerterem-poziomow-logicznych-5906623468010.html) |
| 4 | **Karta microSD 32GB** | Nośnik danych (Goodram Class 10) | 20,00 zł | [Kamami](https://kamami.pl/karty-pamieci/563954-karta-pamieci-goodram-micro-sdhc-32gb-class-10-z-adapterem-5908267930144.html) |
| 5 | **DS18B20 (Wodoodporny)** | Czujnik temperatury (1-Wire) | 15,00 zł | [Kamami](https://kamami.pl/czujniki-temperatury/211331-modds18B20-czujnik-temperatury-ds18B20-w-wodoodpornej-obudowie-5906623441044.html) |
| 6 | **Moduł CAN-PAL (TJA1051)** | Komunikacja z magistralą pojazdu | 12,00 zł | [Kamami](https://kamami.pl/konwertery-can/1184871-can-pal-modul-z-transceiverem-can-tja1051t3-5906623431632.html) |
| 7 | **Przetwornica Step-Down (5V 3A)**  | Zasilanie z instalacji auta (12V -> 5V) | 10,00 zł | [Kamami](https://kamami.pl/step-down/585139-modul-przetwornicy-dc-dc-step-down-5v-3a-5906623467921.html) |
| 8 | **Moduł Ładowania + Boost (USB-C)** | Zasilanie awaryjne z ogniwa Li-Ion | 15,00 zł | [Allegro](https://allegro.pl/oferta/gotowy-modul-zasilania-akumulatorowego-usb-c-5v-1a-ogniwo-li-ion-1s-18650-17249844742) |
| 9 | **Akumulator NCR18650B** | Ogniwo Li-Ion 3400mAh | 25,00 zł | [Kamami](https://kamami.pl/akumulatory/583639-akumulator-ncr18650B-panasonic-3400mah-li-ion-37v-68a-5902186324770.html) |
| 10 | **Płytka uniwersalna (dwustronna)** | Baza montażowa (2035 otworów) | 12,00 zł | [Kamami](https://kamami.pl/plytki-uniwersalne/583014-dwustronna-plytka-uniwersalna-2035-otworow-5906623460915.html) |
| 11 | **Obudowa ZOBD (Zaślepka)** | Element montażowy typu OBD | 5,00 zł | [Kamami](https://kamami.pl/akcesoria-do-obudow/1191904-zobd-cap-plug-abs-zlacze-obd-w-postaci-zaslepki-do-obudow-zobd-i-zobd-mini-wykonana-z-czarnego-absu.html) |
| 12 | **Elementy pasywne i drobne** | 3x LED, 3x rezystor 220Ω, 1x rezystor 4.7kΩ, 2x dioda Schottky (np. 1N5817), przełącznik, goldpiny, przewody | 15,00 zł | - |
| **SUMA** | **Całkowity koszt części:** | - |  **~199,00 zł** | - |

---

## 2. Schemat Połączeń (Pinout)

###  Układ Zasilania (UPS - Suma logiczna)

1. **Wejście 12V (Auto):** Podłączone do wejścia przetwornicy Step-Down.
2. **Wejście USB-C:** Podłączenie po przez ładowarkę sieciową.
3. **Wybór Zasilania:** Akumulator powinien być ładowany tylko przez jedno wejście.(To znaczy USB-C lub OBD2)
4. **Masa (GND):** Wszystkie masy połączone razem.

### Peryferia (GPIO ESP32)

| Moduł | Pin Modułu | Pin ESP32 | Uwagi |
| :--- | :--- | :--- | :--- |
| **GPS (LC76G)** | TX | GPIO 16 (RX2) | |
| | RX | GPIO 17 (TX2) | |
| | PPS | GPIO 32 | Opcjonalnie |
| **MicroSD** | CS | GPIO 5 | |
| | MOSI | GPIO 23 | |
| | MISO | GPIO 19 | |
| | SCK | GPIO 18 | |
| **CAN (TJA1051)** | TX (CTX) | GPIO 21 | |
| | RX (CRX) | GPIO 22 | |
| **DS18B20** | DATA | GPIO 4 | Wymagany rezystor 4.7kΩ do 3.3V |
| **Diody LED** | WiFi (Anoda) | GPIO 25 | Przez rezystor 220Ω do GND |
| | GPS (Anoda) | GPIO 26 | Przez rezystor 220Ω do GND |
| | SD/Err (Anoda) | GPIO 27 | Przez rezystor 220Ω do GND |
| **Przycisk** | Pin 1 | GPIO 33 | Drugi pin do GND |

---

## 3. Instrukcja Montażu

1. **Przygotowanie płytki:** Rozmieść elementy na płytce uniwersalnej. Zostaw miejsce na akumulator i przetwornicę.
2. **Sekcja zasilania:**
   * Wlutuj przetwornicę Step-Down i ustaw jej napięcie wyjściowe na 5.1V (przed podłączeniem ESP32!).
   * Wlutuj diode Schottky'ego.
3. **Lutowanie ESP32:** Zalecane użycie listew goldpin (żeńskich), aby moduł był wymienny.
4. **Podłączenie modułów:**
   * Podłącz moduły GPS, SD i CAN zgodnie z tabelą pinów.
   * Pamiętaj o rezystorze pull-up (4.7kΩ) dla czujnika temperatury DS18B20.
5. **Diody LED:** Podłącz diody przez rezystory ograniczające prąd.
6. **Testy:** Sprawdź zasilanie multimetrem przed włożeniem ESP32 w podstawkę.

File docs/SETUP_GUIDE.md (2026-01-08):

# Instrukcja konfiguracji systemu

## Spis treści
1. [Wymagania sprzętowe](#1-wymagania-sprzętowe)
2. [Instalacja oprogramowania](#2-instalacja-oprogramowania)
3. [Konfiguracja](#3-konfiguracja)
4. [Uruchomienie](#4-uruchomienie)

---

## 1. Wymagania sprzętowe

Szczegółowa instrukcja montażu i lista części (BOM) znajduje się w pliku: [📂 hardware/HARDWARE_MANUAL.md](hardware/HARDWARE_MANUAL.md).

**Kluczowe komponenty:**
1.  **Mikrokontroler:** ESP32-DevKitC V4.
2.  **GPS:** Moduł Quectel LC76G (UART).
3.  **CAN:** Transceiver TJA1051T/3.
4.  **Pamięć:** Moduł czytnika microSD + Karta 32GB (FAT32).
5.  **Czujniki:** DS18B20 (Temperatura).
6.  **Zasilanie:** Przetwornica Step-Down (12V->5V) 
7.  **Akumulator:** Ogniwo 18650 (Li-Ion).

---

## 2. Instalacja oprogramowania

Projekt wymaga środowiska **Arduino IDE** (wersja 2.3.6 lub nowsza) ze wsparciem dla płytek ESP32.

1. Instalacja obsługi ESP32
Przejdź do zakładki `Menedżer płytek (ang. Board Manager)`, wyszukaj "esp32" i zainstaluj (wersja od Espressif Systems).
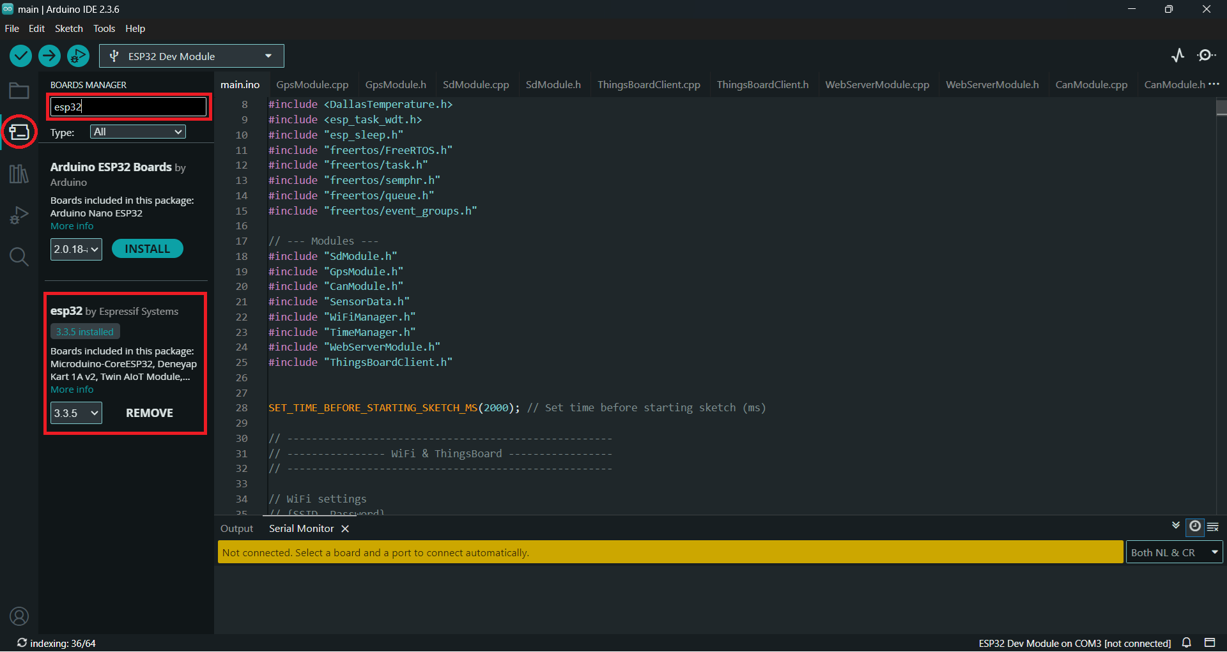
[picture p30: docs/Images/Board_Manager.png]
 

2. Instalacja wymaganych bibliotek
Zainstaluj poniższe biblioteki poprzez Menedżer Bibliotek (`Menedżer bibliotek ang.(Library Manager)`):

| Biblioteka | Autor | Wersja (Testowana) |
| :--- | :--- | :--- |
| **TinyGPSPlus** | Mikal Hart | 1.0.3 |
| **ArduinoJson** | Benoit Blanchon | 7.4.2 |
| **PubSubClient** | Nick O'Leary | 2.8 |
| **DallasTemperature** | Miles Burton | 4.0.5 |
| **OneWire** | Jim Studt | 2.3.8 |

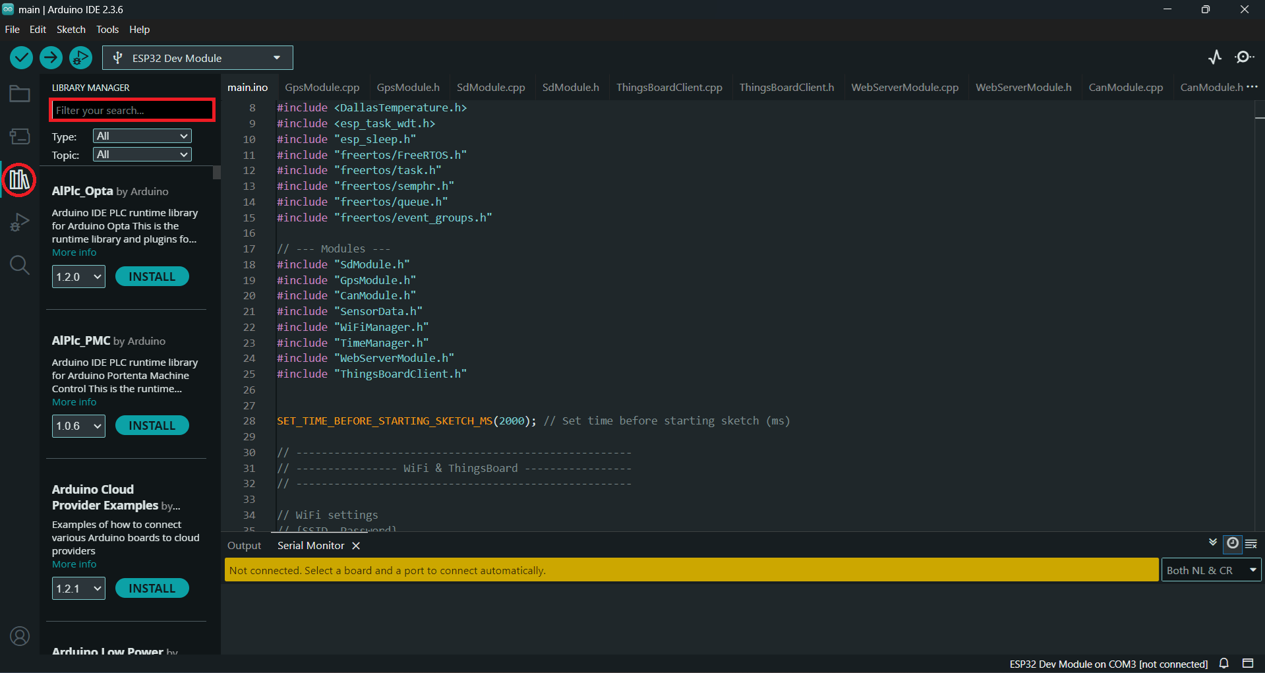
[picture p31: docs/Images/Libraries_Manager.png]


---

## 3. Konfiguracja

Przed wgraniem kodu należy uzupełnić dane logowania w pliku `main/main.ino`.

1.  Otwórz plik `main/main.ino`.
2.  Znajdź sekcję **WiFi settings** (linia ~32) i wpisz dane swojej sieci (możesz dodać więcej niż jedną sieć do tablicy):
    ```cpp
    std::vector<WiFiConfig> WIFI_CONFIG = {
        {"TWOJE_SSID", "TWOJE_HASLO"},   // <--- Edytuj tutaj
        {"Zapasowe_WiFi", "haslo123"}
    };
    ```
3.  Znajdź sekcję **ThingsBoard settings** (linia ~39) i wpisz dane serwera (Pokazane w sekcji "Przygotowanie ThingsBoard"):
    ```cpp
    const char* MQTT_CLIENT_ID = "esp32_test";              //<--- Edytuj tutaj (Client id z ThingsBoard) 
    const char* MQTT_USERNAME  = "user123";                 //<--- Edytuj tutaj (Username z ThingsBoard) 
    const char* MQTT_PASSWORD  = "8erz5sxd48lm797nr4ch";    //<--- Edytuj tutaj (Password z ThingsBoard)
    ```
---

### Przygotowanie ThingsBoard
Aby wizualizacja działała od razu, zaimportuj gotową konfigurację:
1.  Zaloguj się do [ThingsBoard](https://demo.thingsboard.io/).
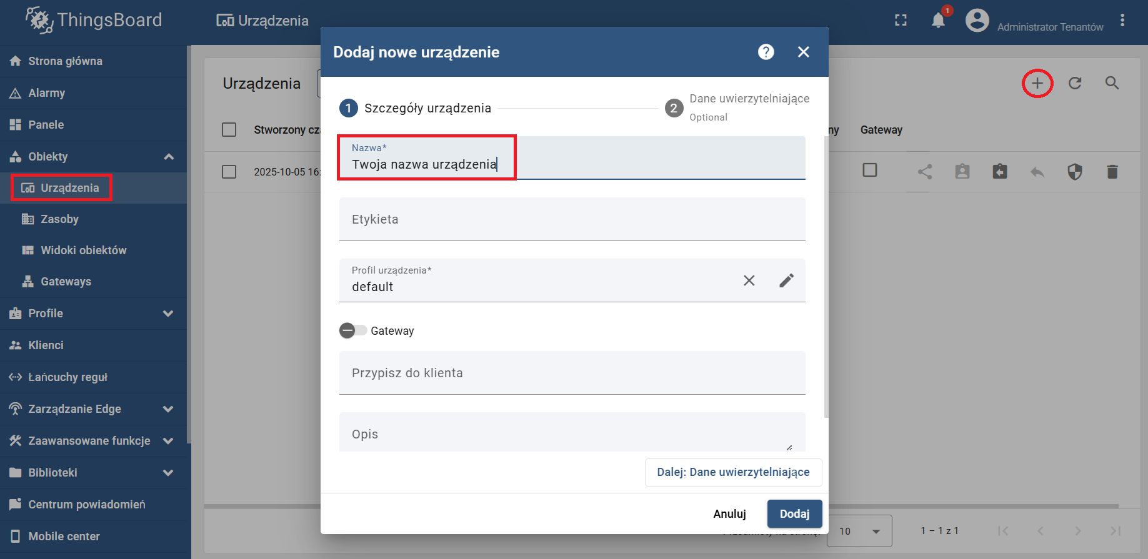
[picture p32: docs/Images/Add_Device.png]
2.  Stwórz nowe urządzenie ("Device").
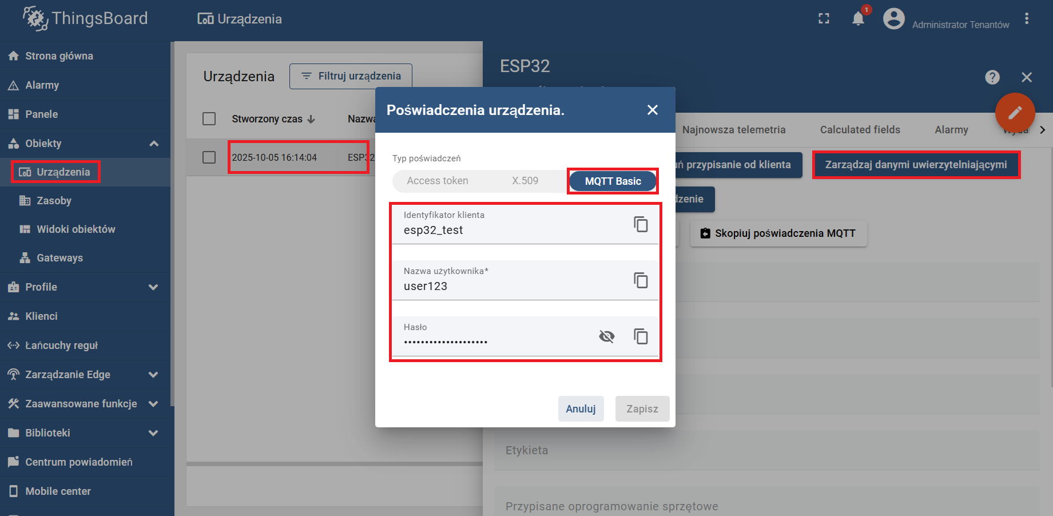
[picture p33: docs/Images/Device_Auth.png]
3.  Skopiuj dane uwierzytelniające 
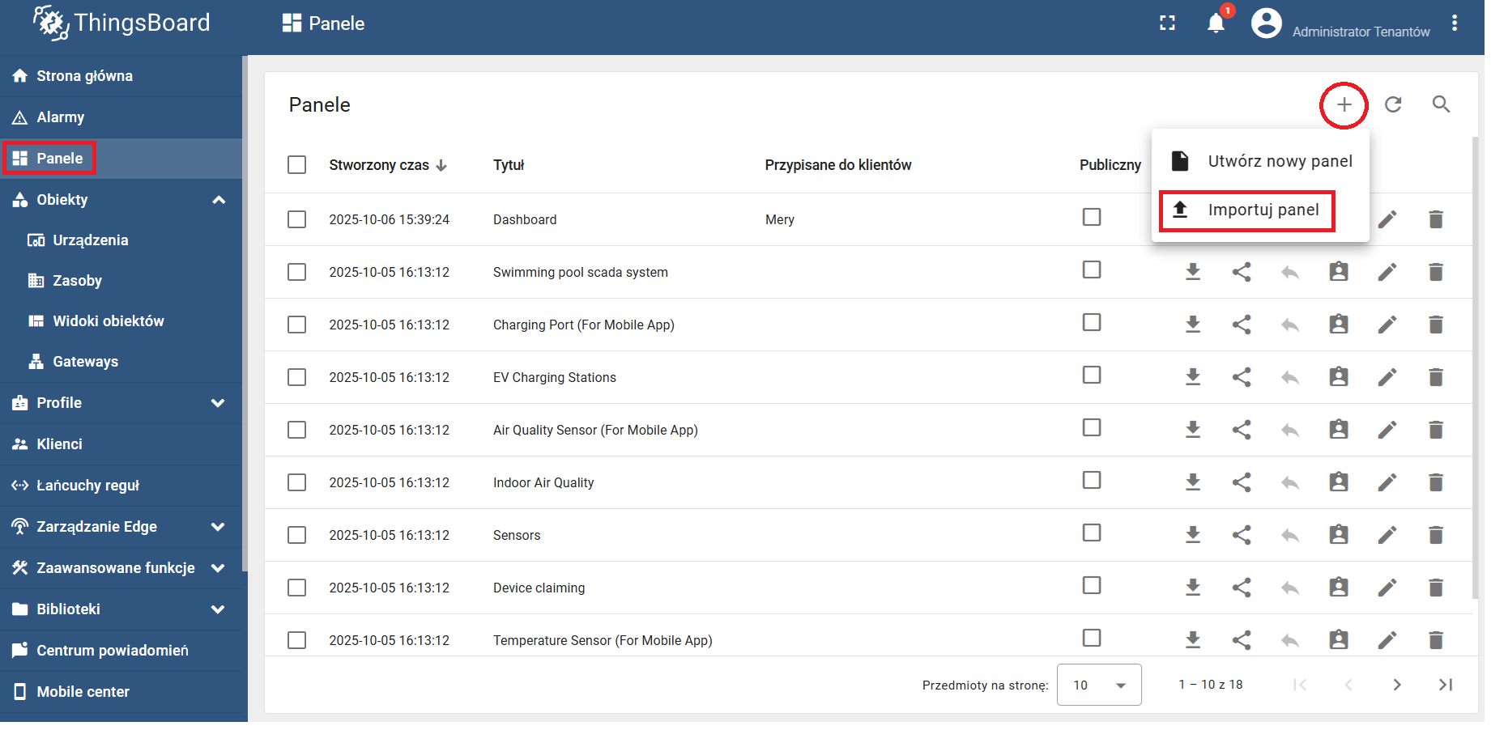
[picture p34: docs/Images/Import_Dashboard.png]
4.  Przejdź do zakładki **Dashboards**, Kliknij `+` -> `Import dashboard` i wybierz plik: `thingsBoard/dashboard.json`.
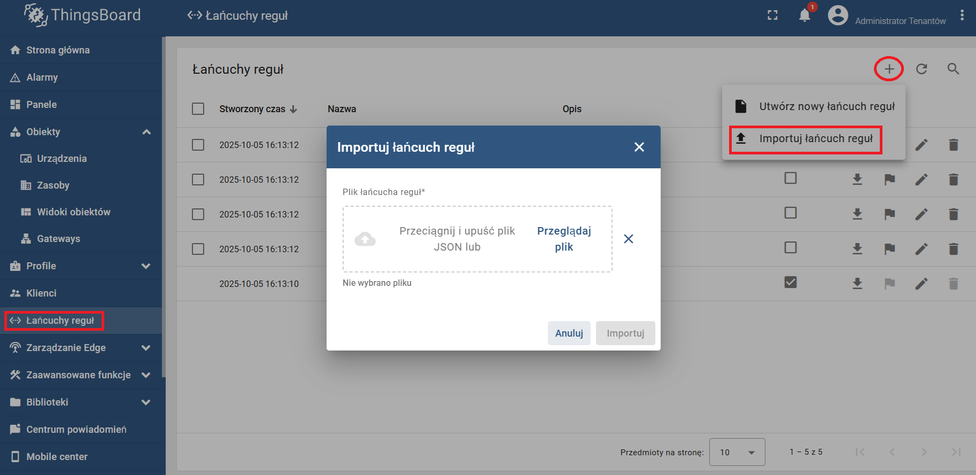
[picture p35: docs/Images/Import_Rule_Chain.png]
5.  Przejdź do zakładki **Rule chains**, Kliknij `+` -> `Import rule chain` i wybierz plik: `thingsBoard/root_rule_chain.json`.

---

## 4. Uruchomienie

### Wgrywanie kodu
1.  Podłącz ESP32 do komputera przez USB.
2.  Wybierz płytkę: `Narzędzia` -> `Płytka` -> `ESP32 Dev Module`.
3.  Wybierz port COM, pod którym wykryto płytkę (nie musi to być COM3).
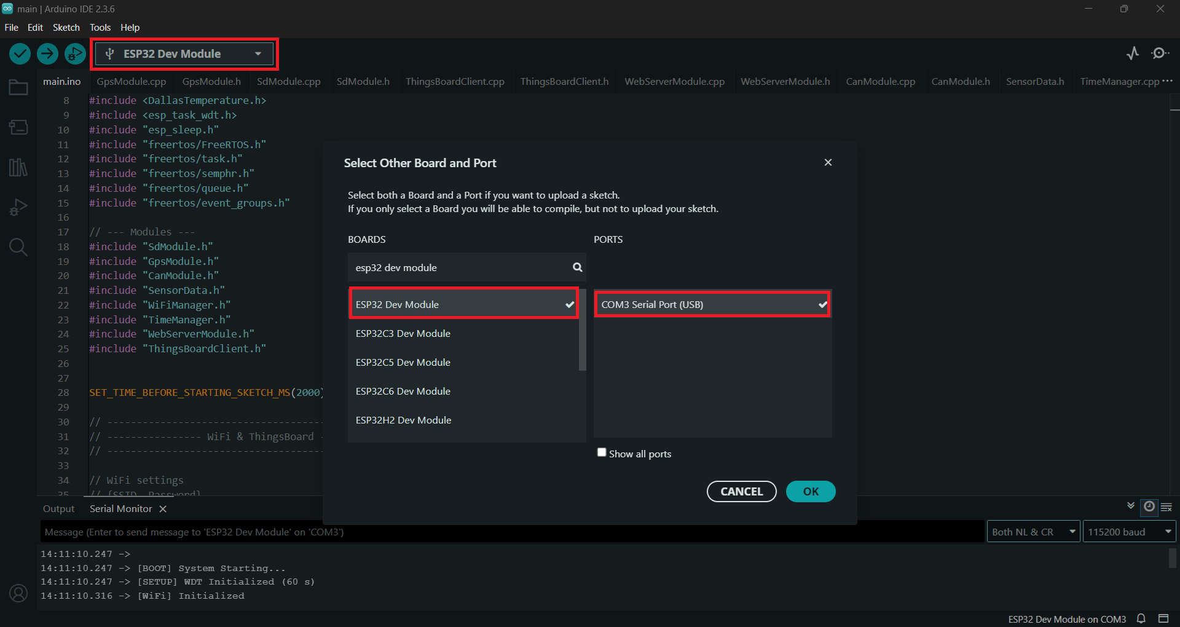
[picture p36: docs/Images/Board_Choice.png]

4.  Kliknij przycisk **Wgraj** (strzałka w prawo).
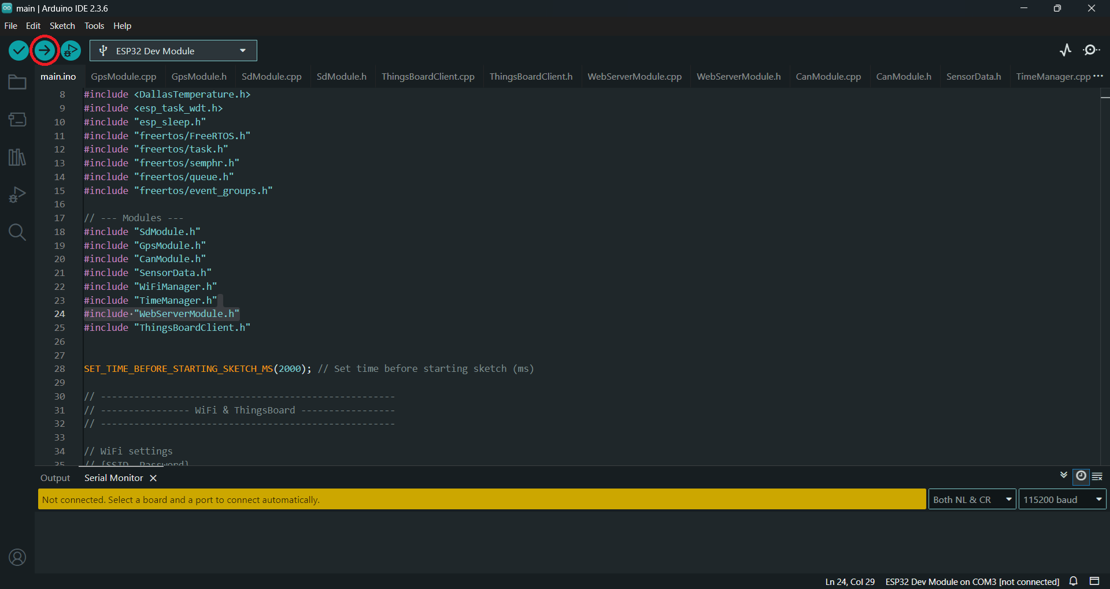
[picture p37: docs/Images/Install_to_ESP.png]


---

## Autor
**Miłosz Stec** Inżynieria Mechatroniczna, AGH Kraków  
Rok: 2026

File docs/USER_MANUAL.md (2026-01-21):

# Instrukcja Użytkownika Systemu Lokalizacji Pojazdu

Niniejszy dokument opisuje sposób codziennego użytkowania urządzenia lokalizacyjnego, interpretację sygnalizacji świetlnej oraz obsługę panelu internetowego.

---

## Spis treści

- [Instrukcja Użytkownika Systemu Lokalizacji Pojazdu](#instrukcja-użytkownika-systemu-lokalizacji-pojazdu)
  - [Spis treści](#spis-treści)
  - [1. Uruchomienie i Zasilanie](#1-uruchomienie-i-zasilanie)
    - [Zasilanie awaryjne (UPS)](#zasilanie-awaryjne-ups)
  - [2. Sygnalizacja LED (Co oznaczają diody?)](#2-sygnalizacja-led-co-oznaczają-diody)
  - [3. Przełącznik zasilania](#3-przełącznik-zasilania)
  - [4. Obsługa Panelu Online (ThingsBoard)](#4-obsługa-panelu-online-thingsboard)
    - [Widok Mapy (Home / Map)](#widok-mapy-home--map)
    - [Wykresy i Parametry (Charts)](#wykresy-i-parametry-charts)
    - [Ustawienia (Settings)](#ustawienia-settings)
  - [5. Praca w trybie Offline](#5-praca-w-trybie-offline)
  - [6. Rozwiązywanie problemów](#6-rozwiązywanie-problemów)

---

## 1. Uruchomienie i Zasilanie

Urządzenie jest zaprojektowane jako **bezobsługowe**.

1.  **Montaż:** Umieść urządzenie w pojeździe w miejscu, które nie zasłania widoku nieba metalowymi elementami (np. na podszybiu lub desce rozdzielczej). Jest to kluczowe dla zasięgu GPS.
2.  **Zasilanie:** Podłącz urządzenie do źródła prądu:
    * **W pojeździe:** Do portu OBD2.
    * **Stacjonarnie:** Do dowolnej ładowarki USB-C (np. od telefonu).
    * **Akumulatorowo:** Włóż akumulator do urządzenia.
    > **Uwaga:** Nie wolno podłączać jednocześnie USB-C oraz portu OBD2. Grozi to uszkodzeniem urządzenia.
3.  **Start:** Urządzenie uruchomi się po włączeniu przełącznika zasilania.

### Zasilanie awaryjne (UPS)
Urządzenie posiada wbudowany akumulator. Po wyłączeniu zapłonu w samochodzie, lokalizator będzie kontynuował pracę przez pewien czas (zależny od poziomu naładowania).

---

## 2. Sygnalizacja LED (Co oznaczają diody?)

Na obudowie znajdują się trzy diody informujące o aktualnym stanie urządzenia.

| Dioda (Kolor) | Stan | Oznaczenie | Co robić? |
| :--- | :--- | :--- | :--- |
| **🔵 WiFi** (Niebieska) | **Świeci** | **Połączono (Online)** | System działa poprawnie, dane są wysyłane na żywo. |
| | Zgaszona | Brak sieci (Offline) | To normalne w trasie. Dane zapisują się na karcie SD. |
| **🟢 GPS** (Zielona) | **Świeci** | **Pozycja ustalona** | Lokalizacja jest precyzyjna. |
| | Zgaszona | Szukanie satelitów | Poczekaj chwilę. W garażach podziemnych /tunelach brak sygnału jest normalny. |
| **🔴 SD** (Czerwona) | **Świeci** | **Karta OK** | Wszystko w porządku, system plików działa. |
| | Zgaszona | Błąd Karty! | Wyjmij i włóż kartę SD ponownie. Jeśli nie pomaga, wymień kartę. |

---

## 3. Przełącznik zasilania

Urządzenie wyposażone jest w jeden przełącznik zasilania, który wyłącza urządzenie.

## 4. Obsługa Panelu Online (ThingsBoard)

Dostęp do danych lokalizacyjnych możliwy jest przez przeglądarkę internetową (na komputerze lub telefonie).

### Widok Mapy (Home / Map)
Główny ekran systemu.
* **Znacznik:** Pokazuje ostatnią znaną pozycję pojazdu.
* **Linia:** Rysuje przebytą trasę.
* **Historia:** Użyj suwaka czasu na dole ekranu lub kalendarza w prawym górnym rogu, aby zobaczyć, gdzie pojazd był wczoraj lub tydzień temu.

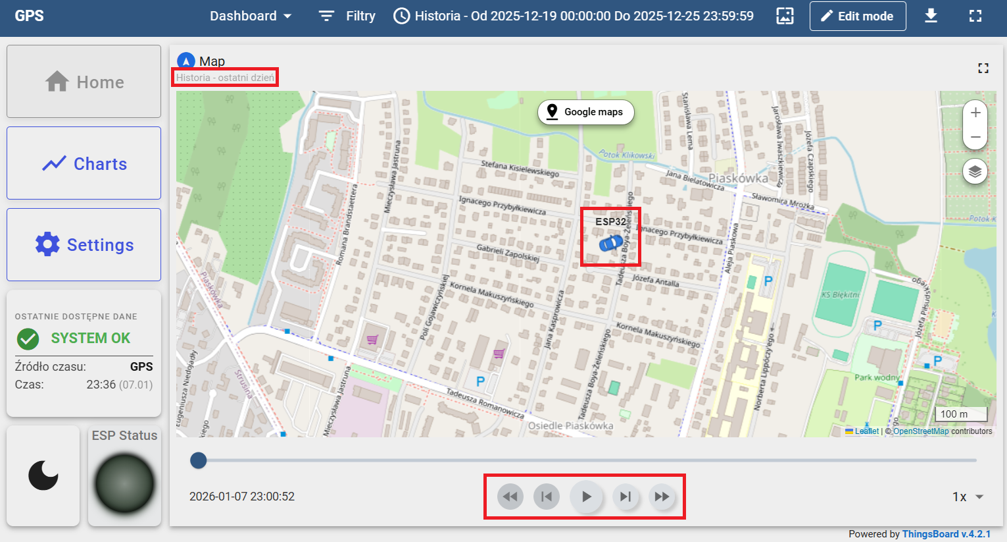
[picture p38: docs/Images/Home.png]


### Wykresy i Parametry (Charts)
Tutaj znajdziesz szczegółowe dane telemetryczne:
* **Prędkość:** Aktualna prędkość pojazdu (km/h).
* **Temperatura:** Odczyt z czujnika temperatury.
* **Siła Sygnału (RSSI):** Informuje o jakości połączenia z siecią WiFi.

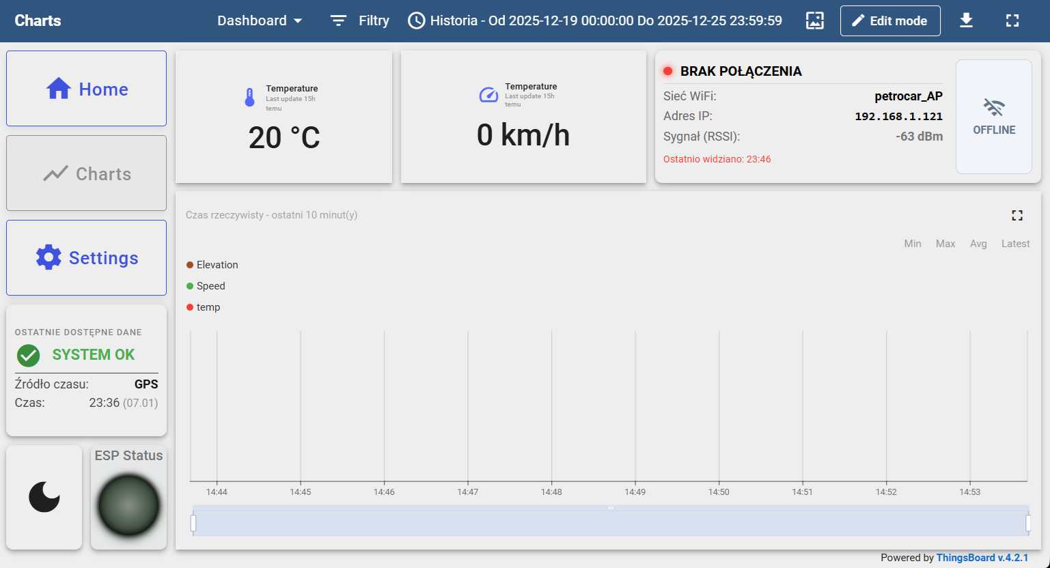
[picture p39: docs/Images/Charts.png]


### Ustawienia (Settings)
W tej zakładce możesz zdalnie zmieniać parametry pracy urządzenia bez konieczności podłączania go do komputera.

* **Interwał zapisu (Delay):** Określa, co ile sekund urządzenie pobiera pozycję.
    * *Mniejsza wartość (np. 5s)* = Bardziej dokładna trasa, ale szybsze zużycie baterii/danych.
    * *Większa wartość (np. 60s)* = Oszczędność energii.
* **Rozmiar paczki (Batch Size):** Ile pomiarów jest wysyłanych naraz.

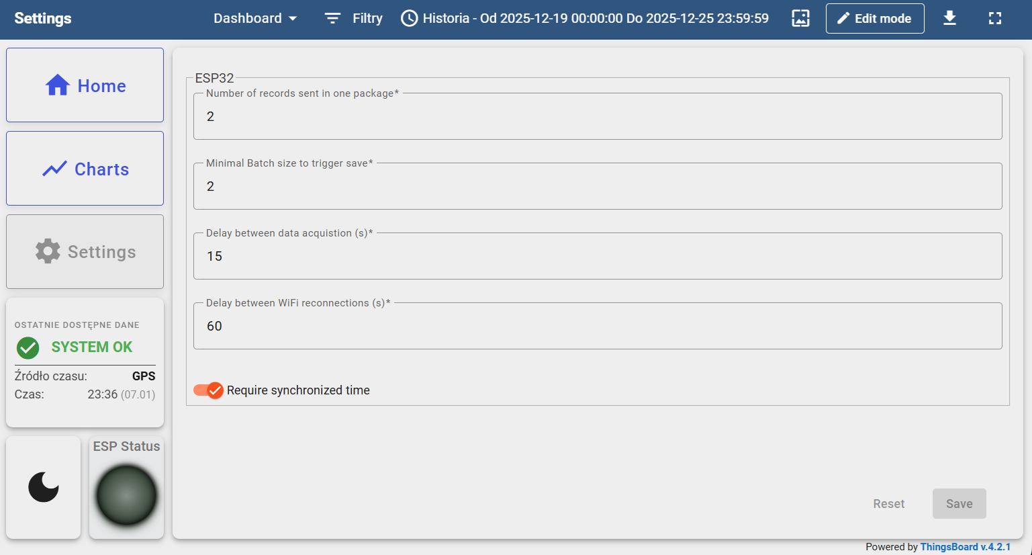
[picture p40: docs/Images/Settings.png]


> **Uwaga:** Zmiana ustawień zostanie wprowadzona w urządzeniu przy następnym połączeniu z serwerem.

---

## 5. Praca w trybie Offline

System jest odporny na zaniki zasięgu WiFi.
1.  Gdy dioda **WiFi (Niebieska)** zgaśnie, urządzenie przechodzi w tryb rejestratora.
2.  Wszystkie dane (trasa, prędkość) są zapisywane na karcie pamięci (bufor).
3.  Po powrocie w zasięg znanej sieci WiFi, urządzenie automatycznie "dosyła" zaległe dane.
4.  Historia trasy na mapie uzupełni się automatycznie.

---

## 6. Rozwiązywanie problemów

**Problem:** Urządzenie nie wysyła danych, świeci tylko czerwona i zielona dioda.
* **Rozwiązanie:** Urządzenie jest poza zasięgiem skonfigurowanej sieci WiFi. To normalne zachowanie. Dane zostaną wysłane po powrocie do bazy/domu.

**Problem:** Dioda GPS (Zielona) nie chce się zaświecić.
* **Rozwiązanie:** Upewnij się, że urządzenie "widzi" niebo. Sygnał GPS nie przenika przez betonowe stropy garaży czy gęste zadaszenia. Pierwsze ustalenie pozycji po długim wyłączeniu (Cold Start) może potrwać do 1 minut.

**Problem:** Dioda SD (Czerwona) zgasła.
* **Rozwiązanie:** Awaria zapisu. Sprawdź, czy karta microSD jest włożona poprawnie. Jeśli tak, sformatuj ją w komputerze (system plików FAT32) i włóż ponownie.

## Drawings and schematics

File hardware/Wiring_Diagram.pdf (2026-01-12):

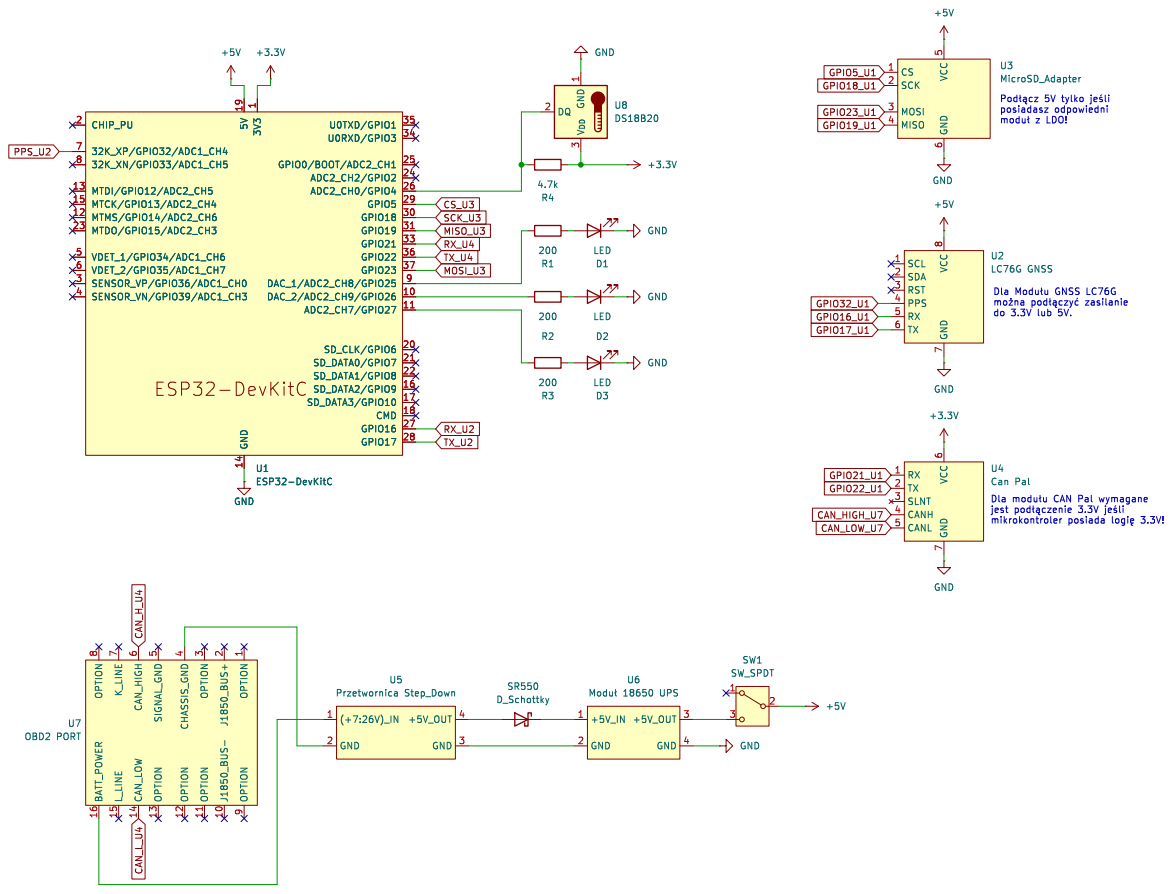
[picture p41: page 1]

+5V GND
þÿmoduB z LDO! Dla þÿmoduBu CAN Pal wymagane

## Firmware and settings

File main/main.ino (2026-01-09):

// --- Libraries ---
#include "FS.h"
#include "SD.h"
#include "SPI.h"
#include <WiFi.h>
#include <OneWire.h>
#include <ArduinoJson.h>
#include <DallasTemperature.h>
#include <esp_task_wdt.h>
#include "esp_sleep.h"
#include "freertos/FreeRTOS.h"
#include "freertos/task.h"
#include "freertos/semphr.h"
#include "freertos/queue.h"
#include "freertos/event_groups.h"

// --- Modules ---
#include "SdModule.h"
#include "GpsModule.h"
#include "CanModule.h"
#include "SensorData.h"
#include "WiFiManager.h"
#include "TimeManager.h"
#include "WebServerModule.h"
#include "ThingsBoardClient.h"


SET_TIME_BEFORE_STARTING_SKETCH_MS(2000); // Set time before starting sketch (ms)

// -----------------------------------------------------
// ---------------- WiFi & ThingsBoard -----------------
// -----------------------------------------------------

// WiFi settings
// {SSID, Password}
std::vector<WiFiConfig> WIFI_CONFIG = {
    {"sdgsdssd", "sd"},
    {"KTO-Rosomak", "12345678"},
    {"Hotspot", "..." }
};

// ThingsBoard settings
const char* THINGSBOARD_SERVER = "demo.thingsboard.io"; // ThingsBoard server address (demo.thingsboard.io for demo server)
const int THINGSBOARD_PORT = 1883;                      // ThingsBoard server port (1883 for MQTT)
const char* MQTT_CLIENT_ID = "esp32_test";              // Client ID for ThingsBoard
const char* MQTT_USERNAME  = "user123";                 // Username for ThingsBoard
const char* MQTT_PASSWORD  = "8erz5sxd48lm797nr4ch";    // Password for ThingsBoard


// -----------------------------------------------------
// ------------------ GPIO Settings --------------------
// -----------------------------------------------------

// LED (Red = 25, Green = 26, Blue = 27)
#define LED_WiFi 27
#define LED_GPS 26
#define LED_SD 25 

// GPS
#define PPS_PIN 32
#define GPS_RX_PIN 17
#define GPS_TX_PIN 16
#define GPS_BAUDRATE 115200

// SD (MOSI = 23, MISO = 19, SCK = 18, CS = 5)
#define SD_CS_PIN 5

// DS18B20
#define ONE_WIRE_BUS 4

// Wake button
#define WAKE_BUTTON_PIN 33

// CAN
#define CAN_RX_PIN 21
#define CAN_TX_PIN 22

// -----------------------------------------------------
// -------------------- Settings -----------------------
// -----------------------------------------------------

// WDT settings
#define WDT_TIMEOUT 120                      // Time before WDT reset (seconds)

// Delays (volatile for dynamic update)
volatile int Delay_MAIN = 15000;            // Main loop delay (ms) (can be changed via ThingsBoard)
volatile int Delay_WIFI = 300000;            // WiFi loop delay (ms) (can be changed via ThingsBoard)
volatile int ATTR_REQUEST_INTERVAL = 300000;// Attributes request interval (ms) (can be changed via ThingsBoard)
volatile int MQTT_KEEPALIVE_TIMEOUT = 2000; // MQTT keep-alive timeout (ms) (can be changed via ThingsBoard)

// LED Brightness (0-255)
volatile int LED_DUTY_WIFI = 10;
volatile int LED_DUTY_GPS  = 80;
volatile int LED_DUTY_SD   = 40;

// PWM for LEDs
#define PWM_FREQ 5000
#define PWM_RES 8

// Buffer settings (volatile for dynamic update)
volatile int BUFFER_CAPACITY = 60;          // Buffer capacity
volatile int SEND_BATCH_SIZE = 2;       // Batch size (how many records to send at once)
volatile int BUFFER_SEND_THRESHOLD = 2; // Threshold to trigger sending (or stop background tasks)
#define MAX_SEND_BATCH_SIZE 20          // Maximum batch size (hard limit)

// Time sync setting (volatile for dynamic update)
volatile bool REQUIRE_VALID_TIME = true;    // Time sync setting (can be changed via ThingsBoard)

// Sensor Enable Flags
bool ENABLE_GPS = true;
bool ENABLE_TEMP = true;
bool ENABLE_CAN = true;

// Debug RAM Usage  
bool DEBUG_RAM = false;

// CPU Frequency
int CPU_FREQ_HIGH = 240;
int CPU_FREQ_LOW = 80;



// -----------------------------------------------------
// ---------- DO NOT CHANGE BELOW THIS LINE ------------
// -----------------------------------------------------



// -----------------------------------------------------
// ------------------- Constants -----------------------
// -----------------------------------------------------

// Event Bits
#define EVENT_GPS_READY  (1 << 0)
#define EVENT_TEMP_READY (1 << 1)
#define EVENT_CAN_READY  (1 << 2)
// Flags for button debouncing
const unsigned long BUTTON_DEBOUNCE_MS = 300;
// Sleep request flag
volatile bool sleepRequestActive = false;
// Delay
const unsigned int TIMEOUT = Delay_MAIN - 3000;
// Data structure
SensorData data;
QueueHandle_t dataQueue;

// -----------------------------------------------------
// -------------------- Semaphores ---------------------
// -----------------------------------------------------
// Used to synchronize access to shared resources

SemaphoreHandle_t dataSem = NULL;
SemaphoreHandle_t sdMutex = NULL;
EventGroupHandle_t sensorEventGroup = NULL;

// -----------------------------------------------------
// -------------------- Task Handlers ------------------
// -----------------------------------------------------
// Used to synchronize task execution

TaskHandle_t coordinatorTaskHandle = NULL;
TaskHandle_t sleepTaskHandle = NULL;
TaskHandle_t tempModuleTaskHandle = NULL;
TaskHandle_t gpsModuleTaskHandle = NULL;
TaskHandle_t dataSyncTaskHandle = NULL;
TaskHandle_t wifiTaskHandle = NULL;
TaskHandle_t canModuleTaskHandle = NULL;
TaskHandle_t webServerTaskHandle = NULL;

// -----------------------------------------------------
// -------------------- Modules ------------------------
// -----------------------------------------------------
// Used to manage and control external modules

SdModule sdModule(SD_CS_PIN);
OneWire oneWire(ONE_WIRE_BUS);
DallasTemperature tempSensor(&oneWire);
WiFiManager wifiManager(WIFI_CONFIG);
CanModule canModule(CAN_RX_PIN, CAN_TX_PIN);
GpsModule gpsModule(GPS_RX_PIN, GPS_TX_PIN, GPS_BAUDRATE);
ThingsBoardClient tbClient(THINGSBOARD_SERVER, THINGSBOARD_PORT, MQTT_CLIENT_ID, MQTT_USERNAME, MQTT_PASSWORD);

// -----------------------------------------------------
// -------------------- Functions ----------------------
// -----------------------------------------------------

void IRAM_ATTR isrButton() {
    // Notify TaskSleep instead of the old ButtonTask
    if (sleepTaskHandle) {
        vTaskNotifyGiveFromISR(sleepTaskHandle, NULL);
    }
}

void initWatchdog(int timeoutSeconds) {
    // Attempt to deinit first if already initialized by Arduino Core
    esp_task_wdt_deinit();
    
    esp_task_wdt_config_t wdt_config = {
        .timeout_ms = (uint32_t)timeoutSeconds * 1000,
        .idle_core_mask = (1 << 0) | (1 << 1),
        .trigger_panic = true
    };
    
    if (esp_task_wdt_init(&wdt_config) != ESP_OK) {
        Serial.println("[SETUP] WDT Init failed!");
    } else {
        Serial.printf("[SETUP] WDT Initialized (%d s)\n", timeoutSeconds);
    }
}

// Callbacks
void attributesCallback(const JsonObject &data) {
    if (data.containsKey("Delay_MAIN")) {
        Delay_MAIN = data["Delay_MAIN"];
        Serial.printf("Updated Delay_MAIN: %d\n", Delay_MAIN);
    }
    if (data.containsKey("Delay_WIFI")) {
        Delay_WIFI = data["Delay_WIFI"];
        Serial.printf("Updated Delay_WIFI: %d\n", Delay_WIFI);
    }
    if (data.containsKey("SEND_BATCH_SIZE")) {
        int val = data["SEND_BATCH_SIZE"];
        if (val > MAX_SEND_BATCH_SIZE) val = MAX_SEND_BATCH_SIZE;
        SEND_BATCH_SIZE = val;
        Serial.printf("Updated SEND_BATCH_SIZE: %d\n", SEND_BATCH_SIZE);
    }
    if (data.containsKey("BUFFER_SEND_THRESHOLD")) {
        BUFFER_SEND_THRESHOLD = data["BUFFER_SEND_THRESHOLD"];
        Serial.printf("Updated BUFFER_SEND_THRESHOLD: %d\n", BUFFER_SEND_THRESHOLD);
    }
    if (data.containsKey("BUFFER_CAPACITY")) {
        BUFFER_CAPACITY = data["BUFFER_CAPACITY"];
        Serial.printf("Updated BUFFER_CAPACITY (needs restart): %d\n", BUFFER_CAPACITY);
    }
    if (data.containsKey("REQUIRE_VALID_TIME")) {
        REQUIRE_VALID_TIME = data["REQUIRE_VALID_TIME"];
        Serial.printf("Updated REQUIRE_VALID_TIME: %d\n", (int)REQUIRE_VALID_TIME);
    }
}

// Helper to print memory stats
void printMemoryStats() {
    Serial.println("----- MEMORY STATS -----");
    Serial.printf("[HEAP] Free: %d bytes, Min Free: %d bytes\n", esp_get_free_heap_size(), esp_get_minimum_free_heap_size());
    
    if (coordinatorTaskHandle) Serial.printf("[TASK] Coordinator: %d bytes free stack\n", uxTaskGetStackHighWaterMark(coordinatorTaskHandle));
    if (wifiTaskHandle)        Serial.printf("[TASK] WiFi:        %d bytes free stack\n", uxTaskGetStackHighWaterMark(wifiTaskHandle));
    if (dataSyncTaskHandle)    Serial.printf("[TASK] DataSync:    %d bytes free stack\n", uxTaskGetStackHighWaterMark(dataSyncTaskHandle));
    if (gpsModuleTaskHandle)   Serial.printf("[TASK] GPS:         %d bytes free stack\n", uxTaskGetStackHighWaterMark(gpsModuleTaskHandle));
    if (tempModuleTaskHandle)  Serial.printf("[TASK] Temp:        %d bytes free stack\n", uxTaskGetStackHighWaterMark(tempModuleTaskHandle));
    if (canModuleTaskHandle)   Serial.printf("[TASK] CAN:         %d bytes free stack\n", uxTaskGetStackHighWaterMark(canModuleTaskHandle));
    if (webServerTaskHandle)   Serial.printf("[TASK] WebServer:   %d bytes free stack\n", uxTaskGetStackHighWaterMark(webServerTaskHandle));
    if (sleepTaskHandle)       Serial.printf("[TASK] Sleep:       %d bytes free stack\n", uxTaskGetStackHighWaterMark(sleepTaskHandle));
    
    Serial.println("------------------------");
}

// -----------------------------------------------------
// ----------------------- TASKS -----------------------
// -----------------------------------------------------

// Coordinator: prepares timestamp, triggers sensor reads, waits for completion and pushes snapshot to buffer
void CoordinatorTask(void* pvParameters) {
    // Add to WDT
    esp_task_wdt_add(NULL);

    // Get last wake time
    TickType_t xLastWakeTime = xTaskGetTickCount();
    
    for (;;) {
        // Wait for next wake
        vTaskDelayUntil(&xLastWakeTime, pdMS_TO_TICKS(Delay_MAIN));
        esp_task_wdt_reset();

        // Print alive for debug
        Serial.println("[COORD] Wakeup");

        if (DEBUG_RAM) {
            printMemoryStats();
        }

        // Trigger tasks via notifications (only enabled ones)
        if (ENABLE_GPS && gpsModuleTaskHandle) xTaskNotifyGive(gpsModuleTaskHandle);
        if (ENABLE_TEMP && tempModuleTaskHandle) xTaskNotifyGive(tempModuleTaskHandle);
        if (ENABLE_CAN && canModuleTaskHandle) xTaskNotifyGive(canModuleTaskHandle);

        // Determine which events to wait for
        EventBits_t expectedBits = 0;
        if (ENABLE_GPS) expectedBits |= EVENT_GPS_READY;
        if (ENABLE_TEMP) expectedBits |= EVENT_TEMP_READY;
        if (ENABLE_CAN) expectedBits |= EVENT_CAN_READY;

        // Wait for all enabled sensors (flags) with timeout
        EventBits_t uxBits = 0;
        if (expectedBits > 0) {
            uxBits = xEventGroupWaitBits(
                sensorEventGroup,
                expectedBits,
                pdTRUE,        // Clear bits on exit
                pdTRUE,        // Wait for ALL bits (AND)
                pdMS_TO_TICKS(TIMEOUT)
            );
        }

        // Check which ones responded (only if enabled)
        bool gpsDone  = !ENABLE_GPS || (uxBits & EVENT_GPS_READY);
        bool tempDone = !ENABLE_TEMP || (uxBits & EVENT_TEMP_READY);
        bool canDone  = !ENABLE_CAN || (uxBits & EVENT_CAN_READY);

        // Output missing sensors
        if (!gpsDone || !tempDone || !canDone) {
             Serial.printf("[COORD] Timeout! Missing: %s%s%s\n", 
                gpsDone ? "" : "GPS ", 
                tempDone ? "" : "TEMP ",
                canDone ? "" : "CAN");
        }

        TimeManager::updateFromGps(gpsModule.getUnixTime());
        
        xSemaphoreTake(dataSem, portMAX_DELAY);
        // Get timestamp
        data.ts = TimeManager::getTimestampMs();
        data.ts_source = TimeManager::getTimeSource();
        // Get SSI (Signal Strength)
        data.rssi = WiFi.RSSI();

        // Make a snapshot
        SensorData snapshot = data;
        xSemaphoreGive(dataSem);

        // Check if time is synchronized before storing data
        if (!TimeManager::isSynchronized() && REQUIRE_VALID_TIME) {
            Serial.println("[COORD] Waiting for time sync...");
            continue;
        } else {
            if (xQueueSend(dataQueue, &snapshot, 0) != pdTRUE) {
                Serial.println("[COORD] Queue full, dropping snapshot");
            }
            // Notify TB task to process data
            if (dataSyncTaskHandle) xTaskNotifyGive(dataSyncTaskHandle);
        }
    }
}

// --- TASK: WiFi ---
void TaskWiFi(void* pvParameters) {
    // Add to WDT
    esp_task_wdt_add(NULL);

    tbClient.setAttributesCallback(attributesCallback);
    
    for (;;) {
        // Wait for notification or timeout, but feed WDT periodically
        unsigned long startWait = millis();
        while (millis() - startWait < (unsigned long)Delay_WIFI) {
            esp_task_wdt_reset();
             // Check every 10 seconds
            if (ulTaskNotifyTake(pdTRUE, pdMS_TO_TICKS(WDT_TIMEOUT/2)) > 0) {
                break; // Force wake up
            }
        }
        esp_task_wdt_reset();

        if (WiFi.status() != WL_CONNECTED) {
            Serial.println("[WiFi] WiFi lost/disconnected. Attempting reconnect...");
            esp_task_wdt_reset();
            setCpuFrequencyMhz(CPU_FREQ_HIGH); // Boost for connection
            if (wifiManager.connectToBest()) {
                 // Clear any notifications received
                 ulTaskNotifyTake(pdTRUE, 0);
                 esp_task_wdt_reset();
            }
            else {
                setCpuFrequencyMhz(CPU_FREQ_LOW); // Back to power save if failed
                Serial.println("[WiFi] Failed to reconnect.");
            }
        }
    }
}

// WifiEventHandler: handles WiFi events
void WiFiEventHandler(void* arg, esp_event_base_t base, int32_t id, void* data)
{
    if (base == WIFI_EVENT) {
        switch (id) {

        // Station started
        case WIFI_EVENT_STA_START:
            break;
        
        // Station connected
        case WIFI_EVENT_STA_CONNECTED:
            break;

        // Station disconnected
        case WIFI_EVENT_STA_DISCONNECTED:
            // digitalWrite(LED_WiFi, LOW);
            ledcWrite(LED_WiFi, 0);
            
            setCpuFrequencyMhz(CPU_FREQ_LOW); // Drop to 80MHz immediately on disconnect
            break;

        }
    }

    // Print IP address when got IP
    if (base == IP_EVENT && id == IP_EVENT_STA_GOT_IP) {
        auto* event = (ip_event_got_ip_t*)data;
        Serial.printf("[WiFi] IP: %s\n", WiFi.localIP().toString().c_str());
        // digitalWrite(LED_WiFi, HIGH);
        ledcWrite(LED_WiFi, LED_DUTY_WIFI);

        setCpuFrequencyMhz(CPU_FREQ_HIGH); // Boost to 240MHz when connected

        if (webServerTaskHandle) xTaskNotifyGive(webServerTaskHandle); // Notify WebServer Task
    }
}

// --- TASK: WebServer ---
void TaskWebServer(void* pvParameters) {

    startWebServer(80); // Start server
    
    for (;;) {
        ulTaskNotifyTake(pdTRUE, portMAX_DELAY);
        Serial.println("[WebServer] Starting server loop.");
        
        // Add to WDT
        esp_task_wdt_add(NULL);

        // Loop while connected
        while (WiFi.status() == WL_CONNECTED) {
            esp_task_wdt_reset(); // Reset WDT
            server.handleClient(); // Handle client
            vTaskDelay(pdMS_TO_TICKS(100)); // Refresh every 100ms
        }
        Serial.println("[WebServer] WiFi lost. Stopping server loop.");
        
        // Remove from WDT
        esp_task_wdt_delete(NULL);
    }
}


// --- TASK: GPS ---
void TaskGPS(void* pvParameters){

    esp_task_wdt_add(NULL); // Add to WDT
    
    for(;;) {
        // Wait for notification
        ulTaskNotifyTake(pdTRUE, portMAX_DELAY);
        
        unsigned long start = millis();
        bool hasFix = false;
        gpsModule.wake();
        // Read GPS data for max TIMEOUT
        do {
            esp_task_wdt_reset(); // Feed the watchdog

            // Process all available GPS data
            while (gpsModule.available()) gpsModule.process(); 

            // If fix is acquired, break early
            if (gpsModule.hasFix()) {
                hasFix = true;
                break; 
            }
            
            vTaskDelay(pdMS_TO_TICKS(10));

        } while (millis() - start < TIMEOUT);

        // Write results
        xSemaphoreTake(dataSem, portMAX_DELAY);
        
        if (hasFix) {
            // Copy data
            GpsDataPacket packet = gpsModule.getData();
            data.lat = packet.lat;
            data.lon = packet.lon;
            data.alt = packet.alt;
            data.alt = packet.alt;
            data.vel = packet.vel;
            data.lgr_ts = TimeManager::getTimestampMs();
            
            data.ec &= ~ERR_GPS_NO_FIX;
            Serial.printf("[GPS] Fix acquired! Lat: %f, Lon: %f\n", data.lat, data.lon);
            // digitalWrite(LED_GPS, HIGH);
            ledcWrite(LED_GPS, LED_DUTY_GPS);
        } else {
            data.ec |= ERR_GPS_NO_FIX;
            Serial.printf("[GPS] Timeout: No fix within %lu ms.\n", TIMEOUT);
            // digitalWrite(LED_GPS, LOW);
            ledcWrite(LED_GPS, 0);
        }
        
        xSemaphoreGive(dataSem);
        gpsModule.sleep();
        // Notify coordinator that GPS finished
        xEventGroupSetBits(sensorEventGroup, EVENT_GPS_READY);
    }
}

// --- TASK: Temperature ---
void TaskTemp(void* pvParameters) {
   
    esp_task_wdt_add(NULL);  // Add to WDT
    
    const TickType_t CONVERSION_DELAY = pdMS_TO_TICKS(750); // Conversion delay for 12-bit resolution is max 750ms

    for (;;) {
        // Wait for signal from Coordinator
        ulTaskNotifyTake(pdTRUE, portMAX_DELAY);
        
        esp_task_wdt_reset();

        // Request temperature
        tempSensor.requestTemperatures();
        
        // Asynchronous waiting (Yield)
        vTaskDelay(CONVERSION_DELAY);

        // Read result
        float tempC = tempSensor.getTempCByIndex(0);
        
        // Write data
        xSemaphoreTake(dataSem, portMAX_DELAY);
        
        // DEVICE_DISCONNECTED_C is constant (-127.0)
        if (tempC != DEVICE_DISCONNECTED_C && tempC > -55 && tempC < 125) {
            data.temp = tempC; 
            data.ltr_ts = TimeManager::getTimestampMs();
            data.ec &= ~ERR_TEMP_FAIL;
            
            Serial.printf("[TEMP] Temp: %.2f C\n", tempC);
        } else {
            data.ec |= ERR_TEMP_FAIL;
            Serial.println("[TEMP] Error: Read failed");
        }
        
        xSemaphoreGive(dataSem);

        // Notify Coordinator that temperature is ready
        xEventGroupSetBits(sensorEventGroup, EVENT_TEMP_READY);
    }
}

void TaskCAN(void* pvParameters) {
    esp_task_wdt_add(NULL);
    twai_message_t msg;

    for (;;) {
        // Wait for notification from Coordinator
        ulTaskNotifyTake(pdTRUE, portMAX_DELAY);

        unsigned long start = millis();
        bool received = false;
        
        // Loop for TIMEOUT to find the specific CAN message
        while (millis() - start < TIMEOUT) {
            esp_task_wdt_reset();

            if (canModule.getMessage(msg)) {

                // Check for Renault Megane 3 Speed ID (0x354)
                if (msg.identifier == 0x354) {

                    // Read vehicle speed (msg, id, startBit, length, isBigEndian, factor)
                    float vehicle_speed = canModule.readSignal(msg, 0x354, 0, 16, true, 0.01f);

                    if (vehicle_speed >= 0) {
                        Serial.printf("[CAN] Speed CAN: %.2f km/h\n", vehicle_speed);
                        
                        xSemaphoreTake(dataSem, portMAX_DELAY);
                        data.can_vel = vehicle_speed;
                        data.lcr_ts = TimeManager::getTimestampMs();
                        xSemaphoreGive(dataSem);

                        received = true;
                        break;
                    }
                }
            } 
            else {
                // Short yield if no message available
                vTaskDelay(pdMS_TO_TICKS(1)); 
            }
        }

        if (received) {
             xEventGroupSetBits(sensorEventGroup, EVENT_CAN_READY);
         }
    }
}
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
void loop() {
    // Nothing to do here
}     

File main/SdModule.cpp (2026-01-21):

#include "SdModule.h"

// Constructor
SdModule::SdModule(int csPin) : _csPin(csPin) {}

// -----------------------------------------------------
// --------------- Public Methods ----------------------
// -----------------------------------------------------

// SD Card Initialization
bool SdModule::ensureReady(bool force) {
    if (sdMutex) xSemaphoreTake(sdMutex, portMAX_DELAY);

    // Cooldown check (only if not forced)
    if (!force) {
        if (millis() - _lastRetryTime < 2000) {
            if (sdMutex) xSemaphoreGive(sdMutex);
            return _initialized; 
        }
        _lastRetryTime = millis();
    }

    // State Check (only if not forced)
    // If we think we are initialized, verify it
    if (_initialized && !force) {
        if (SD.cardType() == CARD_NONE) {
            Serial.println("[SD] Card missing. Unmounting.");
            _initialized = false;
        } else {
            // Logical check
            File root = SD.open("/", FILE_READ);
            if (!root) {
                Serial.println("[SD] FS Error. Invalidating state.");
                _initialized = false;
            } else {
                root.close();
                if (sdMutex) xSemaphoreGive(sdMutex);
                return true; // All good
            }
        }
    }

    // Recovery / Initialization
    // If we reach here, either force=true OR _initialized=false
    
    // Always clean up first
    SD.end(); 
    _initialized = false;

    // Try to mount
    if (SD.begin(_csPin)) {
        Serial.println("[SD] Mount/Restart successful.");
        _initialized = true;
        
        // Ensure pending file exists
        if (!SD.exists(_pendingFilename)) {
            File p = SD.open(_pendingFilename, FILE_WRITE);
            if(p) {
                p.close();
                Serial.println("[SD] Pending file created.");
            }
        }
    } else {
        Serial.println("[SD] Mount failed.");
    }
    
    if (sdMutex) xSemaphoreGive(sdMutex);
    return _initialized;
}

// -----------------------------------------------------
// --------------- PENDING FILE (FIFO) -----------------
// -----------------------------------------------------

bool SdModule::logToPending(const SensorData* batch, int count) {
    if (sdMutex) xSemaphoreTake(sdMutex, portMAX_DELAY);

    // Open in APPEND mode (write to end)
    File file = SD.open(_pendingFilename, FILE_APPEND);
    if (!file) {
        Serial.println("[SD] Failed to open pending file for writing");
        _initialized = false; // Mark SD error to force remount
        if (sdMutex) xSemaphoreGive(sdMutex);
        return false;
    }

    for (int i = 0; i < count; ++i) {
        JsonDocument doc;
        JsonObject obj = doc.to<JsonObject>();
        sensorDataToTb(batch[i], obj);
        

        if (serializeJson(doc, file) == 0) {
            Serial.println("[SD] Failed to write record to pending");
        }
        file.println(); // New line = new record
    }
    
    Serial.printf("[SD] Saved %d records to Pending\n", count);
    file.close();
    
    if (sdMutex) xSemaphoreGive(sdMutex);
    return true;
}

// Reads 'maxItems' lines from the beginning of the file
int SdModule::readPendingBatch(JsonArray &outArray, int maxItems) {
    if (sdMutex) xSemaphoreTake(sdMutex, portMAX_DELAY);

    if (!SD.exists(_pendingFilename)) {
        if (sdMutex) xSemaphoreGive(sdMutex);
        return 0;
    }

    File file = SD.open(_pendingFilename, FILE_READ);
    if (!file) {
        if (sdMutex) xSemaphoreGive(sdMutex);
        return 0;
    }

    int validRecords = 0;
    int linesRead = 0; // Counter for physically read lines

    // Read while data exists and limit not reached
    while (file.available() && validRecords < maxItems) {
        
        String line = file.readStringUntil('\n');
        line.trim();
        linesRead++; // Count every line (even empty/invalid)

        if (line.length() == 0) continue;

        JsonDocument doc;
        DeserializationError error = deserializeJson(doc, line);
        
        if (error) {
            Serial.print("[SD] JSON parse error in pending (skipping): ");
            Serial.println(error.c_str());
            // Invalid line is ignored but will be removed by removeFirstRecords,
            // because removeFirstRecords removes N lines. 
            // There is a risk of desynchronization if we only count valid ones.
            // For simplicity: ignore errors and continue reading.
            continue;
        }

        outArray.add(doc);
        validRecords++;
    }
    
    file.close();
    
    if (sdMutex) xSemaphoreGive(sdMutex);
    return validRecords;
}
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

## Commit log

2025-08-31 Added GPS and Thingspeak connectivity
    ESP32 sends GPS data every 30s to Thingspeak server
2025-10-19 Thingsboard
    Added Thingsboard support
    Added Webserver
    Reworked SdModule
    [GpsModule.cpp, SdModule.cpp, ThingsBoardClient.cpp]
2025-11-21 Cleaned up main
    Added RPC callback(not working)
    TB can send from buffer
    [ThingsBoardClient.cpp, main.ino]
2025-11-27 V1
    Added TaskWifi
    Code restructuredd
    Added comments
    RPC doesn't work
    [GpsModule.cpp, SdModule.cpp, ThingsBoardClient.cpp]
2025-11-30 Data flow change
    Updated WiFi handling
    Added flag for starting with valid ts (REQUIRE_VALID_TIME)
    Merged TaskSD into TaskTB
2025-12-07 Reorganized SensorData
2025-12-30 X-Macro
    Added macro to create sensordata
    Changed keys in sensordata
2026-01-03 Updated CAN
    Added easy filtering to CAN ID
2026-01-06 Fixes
    Changed sending data to TB with delay 2s
    No longer using button to sleep.
    Changed time synchronization
    Added date filtering in webserver
    [main.ino]
2026-01-08 V1.2
    Added Guides,License
    Cleaned code
    Added PWM for LEDs
    Added Wake/Sleep and EASY for GPS
2026-01-10 Files
    Added 3d model
    Updated Praca
    [Obudowa.SLDASM, Obudowa_dol.SLDPRT, Obudowa_dol.STL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]
